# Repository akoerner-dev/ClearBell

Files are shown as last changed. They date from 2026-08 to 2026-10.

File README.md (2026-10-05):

# ClearBell — Smart-Doorbell (ESP32-S3, Hardware + Firmware)

Selbst entwickeltes Türklingelsystem für ein Zweifamilienhaus — vollständig
eigenentwickelt von der Schaltung über das PCB-Layout bis zur Firmware.
Das Projekt dokumentiert nicht nur *was* gebaut wurde, sondern die
**begründeten Technikentscheidungen** dahinter.

> Leitsatz des Projekts: **„Keep it simple, but working."**

**Aktuelle Generation: V0.2** — Redesign auf den ESP32-S3. Beide Platinen sind fertig
verlegt, geprüft und werden bei PCBWay gefertigt und bestückt. Die erste Generation läuft
im Haus und liegt im [Archiv](archiv/V0.1/).

| Außeneinheit V0.2 | Inneneinheit V0.2 |
|---|---|
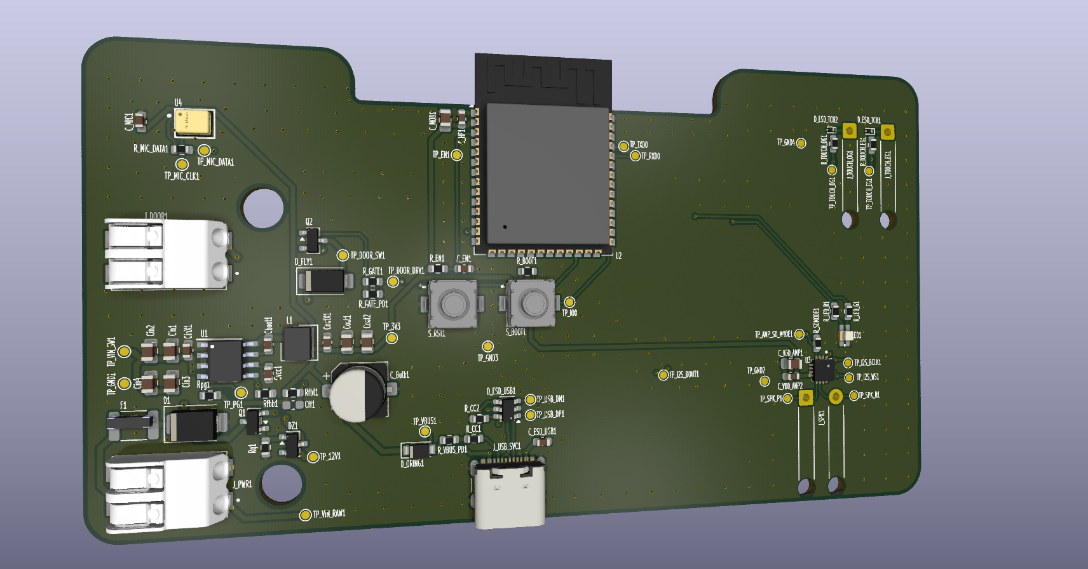
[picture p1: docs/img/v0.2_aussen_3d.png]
Außeneinheit V0.2 – KiCad-3D-Ansicht
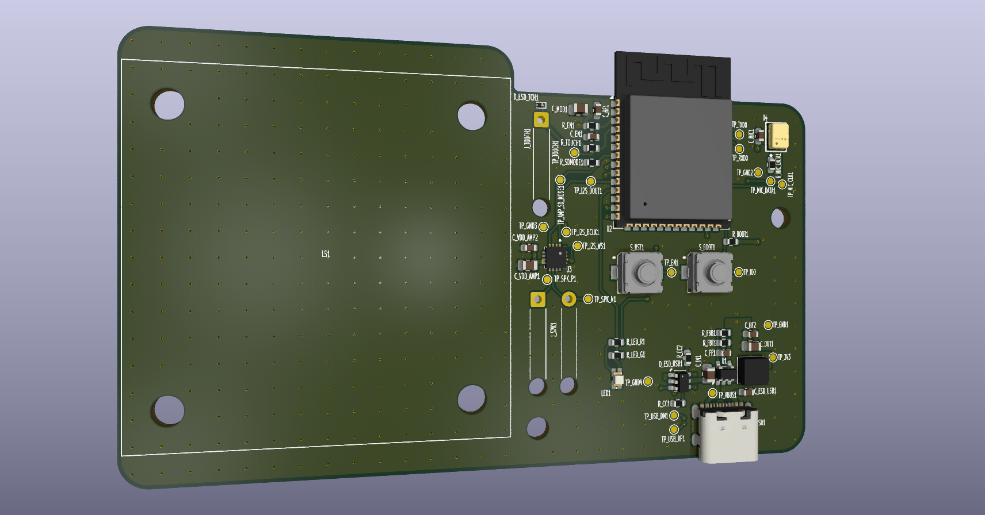
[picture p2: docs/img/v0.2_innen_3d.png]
Inneneinheit V0.2 – KiCad-3D-Ansicht
|  |  |
| 110 × 60 mm, 4 Lagen, 12 V DC | 98 × 60 mm, 4 Lagen, USB-C |

---

## Überblick

Eine **Außeneinheit** an der Haustür und zwei baugleiche **Inneneinheiten**
(je eine pro Wohnung). Klingeln und Türöffnen laufen als quittierte,
gegen Replay abgesicherte Transaktionen über WLAN/UDP.

| Merkmal | V0.2 |
|---|---|
| Controller | ESP32-S3-WROOM-1-N16R8 (16 MB Flash, 8 MB PSRAM), beide Einheiten |
| Stromversorgung außen | 12 V DC (SELV) → 3,3 V mit LMR33630; Polyfuse, TVS-Diode, Verpolschutz |
| Stromversorgung innen | USB-C 5 V → 3,3 V mit TLV62568 |
| Programmierung | natives USB (USB-Serial-JTAG) — innen über die USB-C-Buchse, außen über eine zusätzliche Service-USB-C |
| Bedienung | kapazitive Touch-Taster mit Bronze-Elektroden, ESD-geschützt |
| Audio | MAX98357A I2S-Class-D, Visaton K 50 FL (außen) / K 50 SQ (innen) |
| Mikrofon | Infineon IM72D128V01 (PDM, IP57) auf beiden Einheiten |
| Anzeige | zweifarbige Status-LED (grün / rot, zusammen bernstein) |
| Türöffner | Low-Side-MOSFET mit Freilaufdiode |
| Kommunikation | WLAN + UDP über den Heim-Router, Türbefehl per HMAC-SHA256 authentifiziert |

---

## Was sich gegenüber V0.1 geändert hat — und warum

- **ESP32-S3 statt ESP32.** Natives USB: Flashen und Logs ohne UART-Adapter und ohne
  Tastendruck. PSRAM für Audiopuffer, Flash-Reserve für zwei OTA-Partitionen, vom
  Hersteller zugesagte Verfügbarkeit bis 2033.
- **Mikrofon auf beiden Einheiten** — als Vorbereitung für späteres Wechselsprechen.
  Die Wahl fiel auf ein PDM-Mikrofon, das direkt an 3,3 V läuft: kein zweiter
  Spannungsbereich, keine Pegelwandler.
- **Keine SD-Karte mehr.** Die Klingeltöne sollen im Flash liegen und über die
  Statusseite getauscht werden — ein Steckverbinder und ein mechanischer Fehlerpfad weniger.
- **4 Lagen statt 2.** Beide Innenlagen sind Masse; jede Signallage hat ihre Bezugsfläche direkt
  darunter. Grund: Bei 1,6 mm liegt der dicke Kern zwangsläufig zwischen den Innenlagen, eine
  eigene Versorgungslage brächte dort kaum Flächenkapazität. Bekannte Abweichung (Inneneinheit):
  Eine 3,3-V-Leitung verläuft auf In2 und unterbricht dort die Massefläche.
  USB D+/D−, I2S_BCLK, I2S_WS und LED_RED auf der Unterseite kreuzen diesen Schlitz; ihr Rückstrom
  muss ausweichen. Funktional unkritisch bei USB Full Speed, aus EMV-Sicht aber vermeidbar.
  Behebung in V0.3: Leitung auf eine Außenlage verlegen, In2 wieder geschlossen.
- **Vias neben den Pads, nicht darin.** Ein Via im Pad zieht beim Reflow Lot ab. Der DRC
  prüft das nicht — deshalb eigene Prüfskripte über alle Vias und Pads.
- **Touch ohne Shield/Guard.** Die Bronze-Elektroden bleiben frei zugänglich. Gegen Drift
  durch Feuchte ist eine adaptive Baseline in der Firmware vorgesehen; die ESD-Dioden haben
  nur 0,5 pF, damit die Empfindlichkeit erhalten bleibt.
- **Türöffner-Freilaufdiode auf 1 A ausgelegt** (SMA-Gehäuse). In V0.1 saß dort eine
  Signaldiode, die für den Spulenstrom des Türöffners zu klein war.

Der Funk-Transport bleibt WLAN/UDP über den Router — ESP-NOW wurde an den echten
Montageorten gemessen und verworfen, siehe
[`docs/Funkvalidierung_ESPNOW.md`](docs/Funkvalidierung_ESPNOW.md).

---

## Repo-Struktur

```
clearbell/
├── hardware/                  V0.2, KiCad 10
│   ├── Ausseneinheit/         Schaltplan, Platine, Schaltplan.pdf
│   │   └── fertigung/         Gerber-ZIP, Stückliste, Bestückungsdaten
│   └── Inneneinheit/          dito
├── docs/
│   ├── img/                   3D-Ansichten V0.2
│   ├── Softwarearchitektur_V0.2.md      Firmware-Architektur, Laufzeit, Sicherheit
│   ├── Softwarearchitektur_V0.2.en.md   dasselbe auf Englisch
│   └── Funkvalidierung_ESPNOW.md
└── archiv/V0.1/               erste Generation: Hardware, Firmware, Dashboard, Dokumentation
```

---

## Fertigung

| | |
|---|---|
| Lagenaufbau | 4 Lagen, 1,6 mm, FR-4 (S1000H, TG150), 1 oz außen und innen, keine Impedanzkontrolle |
| Oberfläche | ENIG, Lötstopplack grün, Bestückungsdruck weiß (nur oben) |
| Bestückung | einseitig, maschinell — außen 56, innen 33 Bauteile |
| Stückliste | je Einheit in `fertigung/`, mit Spalte „Ersatz zulässig" (kritische Teile ohne Ersatz) |
| Prüfung | DRC und ERC ohne Befund |

Leiterplatten und Bestückung der V0.2 übernimmt **[www.pcbway.com](https://www.pcbway.com)** im Rahmen eines Sponsorings.

---

## Firmware

Die Firmware — Arduino Core, quittiertes UDP-Protokoll, HMAC-gesicherter Türbefehl,
eigener WAV-Player — läuft auf V0.1 und liegt unter
[`archiv/V0.1/firmware/`](archiv/V0.1/firmware/). Die V0.2-Firmware entsteht nach der
Inbetriebnahme der V0.2-Platinen: Die Prinzipien des Protokolls werden übernommen,
Paketformat, Türbefehl, Fern-Öffnen und Touch-Auswertung dagegen neu aufgesetzt.

**Wie die V0.2-Firmware aufgebaut wird, beschreibt ein eigenes Dokument:** Architektur und
Ausführungsmodell, authentifiziertes Protokoll, Startsequenz und Laufzeitverhalten,
Datenhaltung und Flash-Aufteilung, ein Sicherheitskapitel mit Angreifermodell,
**offen benannten Restrisiken** und einem Abgleich mit ETSI EN 303 645, Fehlerverhalten,
Portierungsplan und Teststrategie. Die aktuelle Revision 2 ist das Ergebnis eines
kritischen Reviews der ersten Fassung mit 29 Befunden.

📄 [**Softwarearchitektur V0.2**](docs/Softwarearchitektur_V0.2.md) · 🇬🇧 [English version](docs/Softwarearchitektur_V0.2.en.md)

Was dort bereits läuft und was noch Entwurf ist, ist durchgehend gekennzeichnet — ebenso die
fünf Verhaltensfragen, die bewusst noch offen sind.

---

## Stand

- **V0.2:** Platinen beider Einheiten in Fertigung und Bestückung bei PCBWay; die
  Firmware-Architektur steht ([Revision 2](docs/Softwarearchitektur_V0.2.md)). Als Nächstes:
  Inbetriebnahme (Versorgung → USB/Flash → Audio → Mikrofon → Touch → Türöffner), danach die
  Firmware-Portierung.
- **V0.1:** läuft im Haus; WLAN/UDP-Transport im Dauertest ohne Paketverlust.

---

## Hinweise

- **Datenblätter** der verwendeten Bauteile sind aus Urheberrechtsgründen **nicht** enthalten —
  sie sind über die Herstellerseiten frei verfügbar; die Typen stehen in den Stücklisten.
- Die eigene KiCad-Bibliothek ist in Schaltplan und Platine eingebettet. Die meisten
  **3D-Modelle** stammen aus der KiCad-Standardbibliothek und erscheinen in jeder
  KiCad-10-Installation; zehn Bauteile nutzen Herstellermodelle (Littelfuse, Panasonic,
  Infineon, TI, WAGO), die aus Lizenzgründen nicht enthalten sind — dort zeigt die
  3D-Ansicht nur die Pads.
- Netzwerknamen, Passwörter und kryptografische Schlüssel sind nicht im Repo.
- **Sicherheitslücken** bitte vertraulich melden, nicht als Issue — wie, steht in
  [`SECURITY.md`](SECURITY.md).

## Lizenz

[MIT](LICENSE) © 2026 André Körner

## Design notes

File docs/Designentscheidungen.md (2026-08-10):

# ClearBell – Designentscheidungen & Begründungen

Dieses Dokument hält fest, WARUM Bauteile gewählt wurden und welche Alternativen verworfen wurden. Wird zu Beginn jedes neuen Chats gelesen, um vollständigen Kontext herzustellen.

---

## Block 1 – Stromversorgung Außeneinheit (12V → 3,3V)

### IC: LMR33630CDDAR (Texas Instruments)

- **Begründung:** Buck-Converter mit 3A, 36V Eingang, 2,1MHz fsw → kleines Induktivitäts-Footprint, hohe Effizienz
- **Alternativen geprüft:** Keine dokumentiert

### L1: Würth 74438356018HT (1,8µH)

- **Begründung:** Passend zur berechneten Induktivität für fsw=2,1MHz, hoher IDC (6,05A), niedriger DCR
- **Status:** Verifiziert gegen Datenblatt ✓

### Verpolschutz: P-Kanal MOSFET (Stelle: Q1)

- **Konzept:** Passiver Verpolschutz ohne aktive Ansteuerung:
  - Source → 12V Eingang
  - Gate → GND über 100kΩ Pull-down (selber Typ wie Rpg, bereits in BOM)
  - Drain → Eingang Buck-Converter
  - Korrekte Polarität: VGS = GND - 12V = -12V → MOSFET leitet
  - Falsche Polarität: VGS = 0V → MOSFET sperrt
- **Begründung für MOSFET statt Schottky:** Verlust bei 1A: \~40mW (MOSFET) vs \~400mW (Schottky) — relevant bei 24/7 Betrieb
- **MOSFET:** DMG2305UX-7 (Diodes Inc., SOT-23) — bleibt in BOM
- **Problem (Review 1.3):** VGS(max) = ±8V, aber bei Betrieb entsteht VGS = -12V → Überschreitung absolutes Maximum
- **Lösung (Review 1.3 ✓):** Zener-Clamp DZ1 parallel Gate-Source
  - Bauteil: Nexperia BZX84-C7V5,215 (7,5V, 250mW, SOT-23)
  - Wirkung: begrenzt VGS auf max. -7,5V → sicher innerhalb ±8V
  - Sättigung des MOSFET bei VGS = -7,5V vollständig gewährleistet (VGS(th) nur -0,5 bis -0,9V)
  - Industriestandard-Lösung, kein Redesign des MOSFET nötig
- **Digikey-Nr. DZ1:** noch einzutragen (BOM v11, Spalte H, Zeile DZ1)

### D1: SMBJ15A (Vishay)

- **Begründung:** TVS-Diode zum Schutz des LMR33630 vor Überspannungstransienten am 12V-Eingang
- **Standoff 15V:** liegt über Betriebsspannung 12V → TVS leitet im Normalbetrieb nicht
- **Klemmspannung 24,4V max.:** tritt nur bei Transienten auf (Spitzenstrom 24,6A) → LMR33630 verträgt 36V → sicher
- **Spitzenleistung 600W:** ausreichend für Transienten in SELV-Haushaltsnetz (kein KFZ)
- **Status:** Verifiziert ✓ (Review 1.4)

### Kondensatoren (Cin, Cout)

- **Regel:** Mindestgehäuse 0603; X7R bevorzugt, X5R akzeptabel wenn Betriebstemperatur ≤ 60°C
- **Temperaturbetrachtung:** Außeneinheit max. \~35°C Umgebung + \~25°C Eigenerwärmung = realistisch \~60°C am Kondensator → X5R (bis 85°C) wäre ausreichend; X7R-Pflicht war zu pauschal

#### Cin — GELÖST (Review 1.5 ✓)

- **Bauteil:** GRM21BZ71E106KE15L — 10µF, 25V, X7R, 0805
- **SimSurfing-Messung bei 12V DC:** nur 2,78µF effektiv (72% Verlust)
- **TI-Anforderung (LMR33630, Section 9.2.2.6):** min. 10µF effektive Kapazität am Eingang
- **Geprüfte Alternativen (verworfen):**
  - GRM21BR61E226ME44 (22µF, 10V, X5R, 0805) → nur 3,85µF bei 12V, unzureichend
  - Höhere Nennspannung in 0805 bei Murata nicht verfügbar
- **Lösung (gewählt): 4× GRM21BZ71E106KE15L parallel**
  - 4 × 2,78µF = \~11,1µF effektiv → erfüllt TI-Minimum von 10µF ✓
  - Kein neues Bauteil nötig, gleicher Typ bereits in BOM
  - TI empfiehlt ohnehin Aufteilung auf beide VIN-Pins (je 2 Caps pro Pin)
- **Fallback Option B** (nur falls PCB-Fläche kritisch wird): Murata GRM32ER71E106KA12L (10µF, 25V, X7R, **1210**) — größeres Gehäuse, besseres DC-Bias-Verhalten, ein Footprint

#### Cout — OK

- **Aktuell:** GRM21BZ71A226ME15L — 22µF, 10V, X7R, 0805 bei 3,3V
- Verhältnis 3,3V/10V = 33% Nennspannung → DC-Bias-Derating unkritisch ✓

---

## Block 2 – ESP32-WROOM-32 Beschaltung

- GPIO6–11 reserviert (internes SPI-Flash) → nicht verwenden ✓ (Review 2.1)
- ADC2 nicht gleichzeitig mit WiFi nutzbar → nur ADC1 Pins verwenden ✓ (Review 2.2)
- GPIO0 Pull-up: 10kΩ empfohlen, Espressif gibt keinen spezifischen Wert vor → 10kΩ akzeptabel ✓ (Review 2.3)
- GPIO12/GPIO15 Strapping-Pins: WROOM-32 hat eFuses für 3,3V Flash gebrannt, GPIO12 unkritisch. Externe Beschaltung darf Strapping-Level nicht überschreiben ✓ (Review 2.4)
- Bulk-Kondensator 100µF (Panasonic EEEFC0J101P): ausreichend für WiFi-Peaks ✓ (Review 2.5)
- UART0: TX=GPIO1, RX=GPIO3 ✓ (Review 2.6)

---

## Block 3 – Kapazitive Touch-Taster (Außeneinheit)

- Touch-Pins: GPIO32 (T9) + GPIO33 (T8) ✓ (Review 3.1) — Hinweis: T8/T9 Bezeichnung in manchen Arduino-Versionen vertauscht, nur Firmware-relevant
- 1kΩ Serienwiderstand ESD-Schutz: innerhalb Espressif-Empfehlung (470Ω–2kΩ, pref. 510Ω) ✓ (Review 3.2)
- Touch durch 2–3mm Holz: Keine Datenblatt-Angabe für max. Dicke. Muss bei Inbetriebnahme empirisch getestet werden (setup_mode: true in ESPHome) ⚠️ (Review 3.3 — offen)
- Steckverbinder: JST-PH

---

## Block 4 – Audio (Außeneinheit)

- IC: MAX98357AETE+T (Maxim/ADI), Class-D, I2S, TSSOP-16
- I2S-Pins: GPIO25 (LRCLK), GPIO26 (BCLK), GPIO22 (DIN) — gängige ESP32 I2S-Pins, via GPIO-Matrix ✓ (Review 4.1)
- ESPHome: i2s_audio + media_player Komponente unterstützt SD-Karten-Audio ✓ (Review 4.2)
- Lautsprecher: Visaton K 36 WP, 8Ω, wetterfest
- SD-Karte für Klingeltöne

---

## Block 2.8 – USB-C Eingang Inneneinheit

### Buchse: Same Sky UJC-HP-3-SMT-TR

- **Typ:** Power-only, 6 Pins (VBUS, GND, CC1, CC2 + 2× Befestigungslaschen), SMD, rechtwinklig
- **Bewertung:** 20V / 3A — ausreichend, Eingang ist 5V
- **Begründung:** Kein Datentransfer nötig → power-only Variante günstiger, einfacher, weniger Footprint-Pins
- **Verfügbarkeit:** Digikey DE, ships today ✓
- **KiCad Symbol/Footprint:** SnapEDA ✓
- **CC-Terminierung:** 2× 5,1kΩ (R_CC1, R_CC2), je CC1/CC2 nach GND
  - Begründung: Ohne Pull-downs kein VBUS-Ausgabe bei modernen USB-C-Netzteilen. Beide CC-Pins müssen beschaltet sein — ein einziger Widerstand genügt nicht.
  - 5,1kΩ signalisiert dem Netzteil: Sink, 5V, Default Current (500mA) — ausreichend für ESP32 + Audio
- **TVS-Schutz:** Entfällt ✓
  - SMBJ5.0A geprüft (Vishay Datenblatt lokal): VC(max) = 9,2V bei IPPM — liegt weit über TLV62568 Abs.Max 5,5V → schützt nicht
  - TVS für 5V-Systeme mit 5,5V Abs.Max generell ungeeignet (kein Bauteil mit VC < 5,5V verfügbar in SMBJ-Serie)
  - Einsteck-Transienten bei USB-C Netzteil in Innenräumen: unkritisch (kurzes Kabel, niedringe Induktivität, interne PSU-Caps, Cin 4,7µF dämpft zusätzlich)
  - Entscheidung: Kein TVS. Cin (4,7µF) ist ausreichender Schutz.

## Block 2.7 – Stromversorgung Inneneinheit (5V USB-C → 3,3V)

- IC: TLV62568DBVR (TI), Buck-Converter, SOT-23-5
- L1: Cyntec SDER041H-2R2MS, 2,2µH
- Cin: Murata GRM188Z71A475KE15D (4,7µF, 10V, X7R, 0603)
- Cout: GRM21BZ71E106KE15L (10µF, 25V, X7R, 0805) — Wiederverwendung aus Außeneinheit-BOM
- **EN-Pin:** Direkt an VIN (+5V) — kein R_EN nötig. Datenblatt Section 7.4.1 + Figure 5 (Referenzschaltbild): EN direkt an VIN, kein Widerstand. Darf laut Datenblatt nicht floaten, direkte VIN-Verbindung ist Standard.
- **C_HF:** 100nF 0603 auf +3V3 direkt an U1 (Layoutregel Datenblatt Section 10.1)
- **PWR_FLAG:** je 1× auf +5V-Netz und +3V3-Netz für ERC

---

## Allgemeine Designregeln

- Mindestgehäuse: 0603
- Kondensatoren: X7R bevorzugt, X5R akzeptabel bei max. ~60°C Betriebstemperatur
- Passivbauteile: 10er-Gebinde
- Lieferanten: Digikey (primär), Mouser, LCSC
- EDA: KiCad (ab Phase 3)
- Firmware: ESPHome
- Leitsatz: **Keep it simple, but working**
- Keine Exoten: E96-Widerstände und schwer beschaffbare Teile vermeiden
- **ESP-NOW + WiFi:** laufen simultan auf demselben WiFi-Kanal. ESP-NOW Kanal kann nicht separat konfiguriert werden wenn WiFi aktiv — teilt automatisch den WiFi-Kanal. Kein Problem für ClearBell. Belegt: ESPHome Docs espnow-Komponente ✓ (Review 5.1)
- **ESPHome Touch:** esp32_touch Komponente vollständig unterstützt. Schwellwert bei Inbetriebnahme kalibrieren ✓ (Review 5.2)

---

## Phase 4 – PCB-Layout Außeneinheit

### Allgemeine Layout-Grundsätze
- **Einseiteige Bestückung:** Alle Bauteile auf Oberseite (F.Cu). Unterseite bleibt frei — wird mit Doppelklebeband ins Gehäuse geklebt.
- **THT-Pins:** Überstehende Lötpins auf der Unterseite werden nach dem Löten bündig abgeknipst, damit die Klebefläche eben ist.
- **J_UART:** Female Socket 90° (liegend), 1×4, 2,54mm, THT — Würth 61300411021, Digikey 732-61300411021-ND. Öffnung muss zur PCB-Kante zeigen (Breadboard-Kabel-Zugänglichkeit).

### Gehäuse & Platinengröße
- Außenmaß Gehäuse: 150 × 100mm
- Rand (Wandstärke + Montagespielraum): 2× 20mm je Achse
- **Platinengröße final: 98 × 60mm** (optimiert nach BT-Platzierung, war initial 110×60mm)
- Touchflächen: mind. 25 × 25mm je Taste (EG rund, OG eckig laut Frontpanel-Design)
- Frontpanel-Layout: 2 Touchflächen + 2 Beschriftungsfelder (vertikal angeordnet)
- **Lautsprecher Visaton K 36 WP: wird auf die PCB geklebt. Hat keine Schraubbefestigung, keine Lötstifte — nur Lötpads direkt auf der Unterseite des Gehäuses. Verbindung zur Schaltung über kurze Drähte in J_SPK (WAGO 2086-1202).**
- **Sperrfläche Lautsprecher: 45×45mm (Keepout Rule Area) — oben rechts in der PCB-Ecke. Kein Bauteil darf unter dem aufgeklebten Lautsprecher liegen. Wird als erstes Element im PCB-Layout eingezeichnet.**
- Touch-Elektroden: Bronze-Blech extern, per kurzem Kabel an R_TOUCH_EG1/R_TOUCH_OG1 angeschlossen (kein PCB-Pad nötig, kein Positionszwang durch Frontpanel-Geometrie)

### Kritische Layout-Randbedingung
- **Touch-Elektroden auf der PCB müssen exakt hinter den Touchflächen des Frontpanels liegen.**
  - Die Kupferfläche der Touch-Pads ist positionsfest durch das Gehäusedesign.
  - Konsequenz: Touch-Pad-Positionen im PCB-Layout zuerst festlegen, dann restliche Bauteile um diese herum platzieren.
- Lautsprecher (Visaton K 36 WP, ø36mm): Position und Gehäuse-Ausschnitt noch festzulegen.

### Fortschritt Phase 4 Außeneinheit
- [x] PCB-Umriss 110×60mm auf Edge.Cuts eingezeichnet
- [x] Keepout Rule Area 45×45mm Lautsprecher — oben rechts eingezeichnet
- [x] PCB aus Schaltplan aktualisiert (F8) — erster Durchlauf, nur Bauteile mit Footprint
- [x] Footprints alle Bauteile zugewiesen (siehe Tabelle unten)
- [x] PCB erneut aus Schaltplan aktualisiert (F8) — alle Bauteile erscheinen
- [x] Footprints manuell auseinandergezogen (kein automatisches Verteilen in KiCad 10 gefunden)
- [x] Bauteilplatzierung abgeschlossen
- [x] Routing abgeschlossen
- [x] GND-Fläche B.Cu gesetzt
- [x] Thermal Vias unter U1 EP gesetzt (0,3mm Bohrung, 0,5mm Pad, Netz GND)
- [x] DRC bestanden: 0 Fehler, 0 Warnungen, 0 Unverbundene Elemente, 37 Ausschlüsse (bekannte SnapEDA-Kosmetik)
- [x] **Phase 4 Außeneinheit PCB-Layout: ABGESCHLOSSEN ✅**

- [ ] **Nächster Schritt: Phase 4 Inneneinheit PCB-Layout**
  - Voraussetzung: F8 Gehäusekonzept Inneneinheit klären (F8)

### Layoutregeln (verifiziert gegen LMR33630 Datenblatt Section 10.1)

**Buck-Converter:**
- Cin direkt an VIN-Pins U1, je 2× pro VIN-Pin
- SW-Knoten (L1 ↔ SW-Pin) so kurz wie möglich, min. 1,5mm breit
- Feedbackteiler (Rfbt/Rfbb) nah an FB-Pin, aber räumlich getrennt vom SW-Knoten (min. 2–3mm)
- EP (Exposed Pad) U1 per Thermal-Via-Array mit GND-Fläche verbinden: 4–9 Vias, 0,3mm Bohrung, 0,5mm Pad, 1mm Raster, Netz GND, kein Via-Tenting Unterseite
- Leiterbahnbreiten: SW-Knoten 1,5mm, 12V-Eingang 1,0mm, +3V3 0,5mm, Signale 0,25mm

**ESP32:**
- C_HF (100nF) direkt am VCC-Pin — näher als C_bulk
- C_bulk (100µF) direkt daneben
- Antenne freihalten: kein Kupfer unter/neben Antennenbereich (auch B.Cu Massefläche)
- Antenne möglichst Richtung Gehäuseaußenwand
- J_UART, S_RST, S_BOOT an PCB-Kante / gut zugänglich

**Thermal Vias allgemein:** 0,3mm Bohrung, 0,5mm Pad, Netz GND, kein Tenting

#### Footprint-Zuweisung — Status

| Bauteil(e) | Footprint | Status |
|---|---|---|
| Alle Widerstände 0603 | `Resistor_SMD:R_0603_1608Metric` | ✓ Festgelegt |
| Kondensatoren 0603 | `Capacitor_SMD:C_0603_1608Metric` | ✓ Festgelegt |
| Kondensatoren 0805 | `Capacitor_SMD:C_0805_2012Metric` | ✓ Festgelegt |
| C_bulk (Elko Ø6,3×5,4mm) | `Capacitor_SMD:CP_Elec_6.3x5.4` | ✓ Festgelegt |
| Q1, DZ1, Q2 (SOT-23) | `Package_TO_SOT_SMD:SOT-23` | ✓ Festgelegt |
| D1 (SMBJ15A, DO-214AA/SMB) | `Diode_SMD:D_SMB` | ✓ Festgelegt |
| D_FLY1 (1N4148W-E3-18, SOD-123) | `Diode_SMD:D_SOD-123` | ✓ Festgelegt — verifiziert gegen Vishay DB: Package = SOD-123 |
| J_UART (Würth 61300411021, Female 90°) | `Connector_PinSocket_2.54mm:PinSocket_1x04_P2.54mm_Horizontal` | ✓ Festgelegt |
| J_TOUCH1, J_TOUCH2 (Lotpad) | `TestPoint:TestPoint_Pad_2.0x2.0mm` | ✓ Festgelegt |
| **WAGO 2086-1202** (J_PWR, J_DOOR, J_SPK) | Von SnapEDA heruntergeladen, in Projektbibliothek eingebunden | ✓ Erledigt |
| **L1 Würth 74438356018HT** | Von Würth heruntergeladen, in Projektbibliothek eingebunden | ✓ Erledigt |
| **PTS526 SK15 SMTR2 LFS** (S_RST, S_BOOT) | Manuell erstellt im KiCad Footprint-Editor. Maße aus C&K-Datenblatt (01/30/26): Körper 5,2×5,2mm, PCB Land 7,0×6,4mm, 4-Pin Gull-Wing. | ✓ Erledigt |

- [ ] Footprint-Zuweisung Inneneinheit (analog, nach Außeneinheit)
- [ ] Bauteilplatzierung
- [ ] Routing

---

## Phase 3 – KiCad Schaltplan (laufend)

### Setup
- KiCad 10.0, deutsche UI
- Zwei separate Projekte (Option A): Außeneinheit + Inneneinheit
- Außeneinheit-Projekt: `<Projektordner>\KiCad\Ausseneinheit\ClearBell_Ausseneinheit.kicad_pro`
- Blattgröße A3, Titelblock ausgefüllt (Rev. 1.0)
- Bibliotheken (projektspezifisch): `<Projektordner>\KiCad\Bibliotheken\`

### Externe Symbole/Footprints (nicht in KiCad-Standardbibliothek)
- **LMR33630CDDAR:** Von TI-Website heruntergeladen, als projektspezifische Bibliothek eingebunden. Footprint: DDA0008J (.pretty-Ordner). ✓
- **ESP32-WROOM-32E-N4:** Von SnapEDA heruntergeladen (N8-Variante, elektrisch identisch zu N4 — gleiche Pins, gleicher Footprint). Als projektspezifische Bibliothek eingebunden. ✓
  - Hinweis: KiCad 10.0 hat ESP32-Symbole bereits in Standardbibliothek (RF_Module) — für zukünftige Bauteile erst dort suchen.

### KiCad-Hinweise aus Praxis
- Standardbibliothek "Device" war initial leer — Lösung: Globale Bibliotheksliste zurücksetzen
- D_TVS in KiCad = bidirektional; unidirektionale TVS (SMBJ15A) → Symbol Device:D_Zener verwenden
- PWR_FLAG auf 12V-Netz UND GND-Netz notwendig um ERC-Fehler "Input-Power-Pin" zu vermeiden
- ERC 7× Ausschlüsse (false positives): VIN/VCC/BOOT/SW Power-Pin-Fehler + Bibliothekswarnungen aus TI-Symbol — alle unkritisch

### Fortschritt Außeneinheit
- [x] Projekt angelegt, Titelblock, A3
- [x] Block 1 komplett: U1, L1, Cin×4+CinX, Cout1/2/CoutX, Cboot, Cvcc, Cff(DNP), Rfbt/Rfbb/Rpg/Rg, Q1+DZ1, D1, J_PWR, 2×PWR_FLAG — ERC sauber
- [x] Block 2 komplett: U2, C_HF1, C_Bulk1, C_EN1, R_EN1, R_BOOT1, R_GPIO2, R_RXD1, S_RST, S_BOOT, J_UART1 — verdrahtet, ERC sauber (10× pin_not_connected für spätere Blöcke bewusst offen)
  - UART J_UART: Pin 2 = TX (ESP TXD0), Pin 3 = RX (ESP RXD0 via R_RXD). Kreuzung TX↔RX passiert im Kabel zum USB-Adapter, nicht auf der Platine.
- [x] Block 3 komplett: R_TOUCH_EG1 (1k), R_TOUCH_OG1 (1k), J_TOUCH_EG (Conn_01x01), J_TOUCH_OG (Conn_01x01) — GPIO32→R→J_TOUCH_EG, GPIO33→R→J_TOUCH_OG
- [x] Block 4 komplett: U2 MAX98357AETE+T (TSSOP-16), C_VDD_AMP1 (10µF), C_VDD_AMP2 (100n), J_SPK (Conn_01x02). SD-Karte: J_SD (Micro_SD_Card, Molex 475710001, Digikey WM9731TR-ND), C_SD (100n). SD_MODE→+3V3 (Left-Channel, direkte Verbindung, kein R_SDMODE), GAIN_SLOT→GND (12dB), EP→GND, Shield→GND. Kein R_SD1–R_SD4 (SPI-Leitungen kurz, 25MHz unkritisch).
- [x] Block 5 komplett: Q2 IRLML6344TRPBF (N-Kanal MOSFET, SOT-23), R_GATE1 (100R), R_GATE_PD1 (100k Pull-down), D_FLY1 (1N4148W), J_DOOR1 (Conn_01x02). GPIO21→R_GATE→Gate, Gate→R_GATE_PD→GND, Source→GND, Drain→J_DOOR Pin1+Anode D_FLY, Kathode D_FLY→+12V, J_DOOR Pin2→+12V. ERC sauber.
  - Türöffner: 9-16V DC, 480mA. Versorgung über vorhandene 12V-Schiene.
  - Designentscheid: MOSFET statt Relais wegen Baugröße (Außeneinheit soll dünn bleiben).
- [x] Block 6 entfällt — alle Steckverbinder bereits in Blöcken 1–5 integriert. Außeneinheit Schaltplan komplett.
- [ ] Inneneinheit Schaltplan
  - [x] KiCad-Projekt angelegt: `KiCad\Inneneinheit\ClearBell_Inneneinheit.kicad_pro`
  - [x] Titelblock: A3, Rev. 0.1
  - [x] Projektbibliotheken eingebunden (ESP32, MAX98357A, UJC-HP-3-SMT-TR)
  - [x] Block 1 vollständig verdrahtet — ERC sauber (2× ignorierte false positives: V-BUS/+5V Netzname + EN bidirektional)
    - J_USB: VBUS→+5V, GND+Shield→GND, CC1→R_CC1→GND, CC2→R_CC2→GND
    - U1: VIN→+5V, EN→+5V, GND→GND, SW→L1→+3V3, FB→Teiler R_FBT/R_FBB
    - R_FBT (470kΩ): +3V3→FB, R_FBB (100kΩ): FB→GND → VOUT = 3,42V (BOM v13: R1_INN=470kΩ RC0603FR-07470KL, R2_INN=100kΩ RC0603FR-07100KL)
    - C_IN1→+5V/GND, C_OUT1/C_HF1→+3V3/GND, PWR_FLAG 1→+5V, PWR_FLAG 2→+3V3
  - [x] Block 2 komplett verdrahtet — ERC sauber (15× ignorierte false positives: GND Kastell-Pads, 3V3/VCC bidirektional; 8× pin_not_connected für Blöcke 3+4 bewusst offen)
    - J_UART1: Pin1=GND, Pin2=TXD0, Pin3=100Ω→RXD0, Pin4=+3V3
    - R_EN1 (10kΩ): +3V3→EN, C_EN1 (100nF): EN→GND, S_RST: EN→GND
    - R_BOOT1 (10kΩ): +3V3→GPIO0, S_BOOT: GPIO0→GND
    - R_GPIO2 (10kΩ): GPIO2→GND (Pull-down für Boot-Modus), No-Connect auf alle ungenutzten Pins
  - [x] Block 3 komplett: R_TOUCH1 (1kΩ) GPIO32→J_TOUCH1
  - [x] Block 4 komplett: U3 MAX98357AETE+T, C_VDD1 (10µF), C_VDD2 (100nF), J_SPK1 (Conn_01x02), J_SD1 (Molex 1040310811, Digikey WM9731CT-ND), C_SD1 (100nF). Kein R_SD-Serienwiderstände, SD_MODE direkt +3V3.
    - I2S: GPIO22→DIN, GPIO25→LRCLK, GPIO26→BCLK, SD_MODE→+3V3
    - SPI SD: GPIO23→CS(DAT3), GPIO21→MOSI(CMD), GPIO19→SCK(CLK), GPIO18→MISO(DAT0), DAT1/DAT2→No Connect — Pins 37/33/31/30 am Modul, optimiert für kurzes Routing zum SD-Slot
    - ERC: 16 Warnungen (SnapEDA-Symbole), teilweise behoben — restliche Fixes ausstehend (s. F5)
  - [x] Block 5 entfällt — alle Steckverbinder bereits in Blöcken 1–4 integriert. Abgleich mit Projektdokumentation Rev.2 bestätigt Vollständigkeit.
  - [x] Inneneinheit Schaltplan komplett — ERC: 0 Fehler, Warnungen werden bereinigt (F5)

### Phase 5 – PCB Layout Inneneinheit
- [x] Edge.Cuts gesetzt (110×65mm vorläufig → optimiert)
- [x] Alle BT platziert
- [x] Geroutet — DRC fehlerfrei
- [x] **F12 GELÖST: Boardgröße optimiert** — finale Größe noch einzutragen (nach Zusammenschieben). Routing wiederholt, DRC sauber.
- [x] **Phase 5 Inneneinheit PCB-Layout: ABGESCHLOSSEN ✅**

### Phase 4 – PCB Layout Außeneinheit (Nachtrag)
- [x] Boardgröße nach Optimierung auf **98×60mm** reduziert (war 110×60mm)

---

## Offene Punkte / Flags

| # | Thema | Beschreibung |
|---|---|---|
| ~~F1~~ | ~~DZ1 Digikey-Nr.~~ | ✓ Gelöst: BZX84-C7V5,215 → DK **1727-5040-1-ND** — in BOM v13 eingetragen |
| ~~F2~~ | ~~Cin Außeneinheit~~ | ✓ Gelöst: 4× GRM21BZ71E106KE15L parallel → ~11,1µF effektiv. Fallback Option B: GRM32ER71E106KA12L 1210 falls Platz knapp. |
| ~~F7~~ | ~~Steckverbinder J_PWR / J_DOOR~~ | ✓ Gelöst: **WAGO 2086-1202 für alle Drahtanschlüsse** (J_PWR, J_DOOR, J_SPK, J_SPK_INN). Begründung: Push-Wire ohne Crimpen, geeignet für Hausinstallationsquerschnitte bis 1,5mm², SMD liegend, kein Spezialwerkzeug. JST-PH Einträge für J_SPK / J_SPK_INN in BOM v13 ersetzt. J_TOUCH/J_TOUCH_INN bleiben Lotpad (Direktanlötung Bronzeelektrode). J_UART bleibt Pin-Header (Programmierschnittstelle). |
| F3 | Review 3.3 Touch/Holz | **Direktkontakt validiert (08.05.2025):** Bronzeelektrode, 1kΩ Reihenwiderstand, GPIO32 (T9), Arduino-ESP32-Core (neuere Version → Rohwerte ~1000er-Bereich, nicht 60–80). Baseline: ~1060, Touch (Finger direkt): ~200, dünner Handschuh: ~910, dicker Skihandschuh: ~990 (bewusst ausgeschlossen). Firmware-Schwellwerte: TOUCH_ON=950, TOUCH_OFF=1000, READS_NEEDED=2, delay=50ms. Skihandschuh: Designentscheidung — nicht unterstützt. **Kalibrierung am eingebauten Gerät (IBN) ausstehend** — Baseline kann je nach Einbauumgebung abweichen. |
| ~~F4~~ | ~~BOM 2.7.3 Digikey-Nr.~~ | ✓ Gelöst: TLV62568DBVR → DK **296-47359-1-ND** — SDER041H-2R2MS → DK **2037-SDER041H-2R2MSCT-ND** — in BOM v13 eingetragen |
| F8 | Inneneinheit Gehäuse | Gehäusekonzept noch nicht entschieden — Bestückungsseite, Befestigung, Formfaktor offen. Entscheidung vor Phase 4 Inneneinheit erforderlich. |
| ~~F12~~ | ~~Boardgröße Inneneinheit optimieren~~ | ✓ Gelöst: BT zusammengeschoben, Routing wiederholt, DRC fehlerfrei. Finale Boardgröße: siehe Phase 5. |
| ~~F11~~ | ~~L1 Inneneinheit Footprint~~ | ✓ Gelöst: Würth WE-MAPI-4020HT Footprint gegen Cyntec SDER041H-2R2MS Datenblatt geprüft — Pad-Maße passen. |
| F5 | ERC Symbol-Mismatch | SnapEDA-Symbole: Pin-Typen direkt im Schaltplan korrigiert (nicht in Bibliothek, da schreibgeschützt). Ursprüngliche 16 Warnungen (falsche Pin-Typen) behoben. Verbleibend: 3× lib_symbol_mismatch (Außeneinheit) + 4× (Inneneinheit) — ignoriert, rein kosmetisch. **ACHTUNG: Niemals "Symbole aus Bibliothek aktualisieren" ausführen — das würde die Schaltplan-Korrekturen mit den alten Bibliotheksversionen überschreiben!** |
| ~~F6~~ | ~~SD-Halter Footprint~~ | ✓ Gelöst: Würth-Footprint aus KiCad-Symbol war nicht kompatibel mit Molex 1040310811. In beiden Schaltplänen auf passenden Molex-Footprint gewechselt. Molex günstiger und mechanisch besser geeignet. BOM-Teilenummer (WM9731CT-ND) war bereits korrekt. |

---
## REVISION 2026-07-05: Kommunikationsarchitektur
ESP-NOW-Direktfunk fuer Klingel/Tueroeffner VERWORFEN nach
Funkvalidierung (Strecke an Montageorten funktional tot, alle Hebel
bewertet: Sendeleistung bereits Maximum 19,5 dBm / EU-Grenze 20 dBm
EIRP; Long-Range-Modus nur ~4 dB; externe Antenne 32UE verworfen).
NEU: Kommunikation ueber Heim-WLAN, UDP direkt zwischen den
Einheiten (kein Broker, kein Pi — Home Assistant laeuft nicht).
Quittungsprotokoll aus ESPNOW_Test wird auf UDP portiert.
Tuerbefehl: Authentifizierung auf Anwendungsebene (Schluessel +
Zaehler). RSSI an allen Montageorten gemessen und tragfaehig.
Details und Messwerte: Funkvalidierung_ESPNOW_2026-07-05.md
Offene Klaerpunkte vor Umsetzung: IoT-SSID vs. Hauptnetz
(Klienten-Isolation pruefen!), DHCP-Reservierungen, Nachrichtensatz,
Wiederverbindungslogik, Volllasttest 3V3, Inneneinheit 2 reparieren.

2026-07-06: WLAN/UDP ueber «Heimnetz» als Transport bestaetigt und
funktional abgenommen (Klingel + Tuer beidseitig, 0 Verluste am
verschaerften OG-Punkt). Langzeit + reale entfernte Funkstrecke als
Worst-Case-Annahme akzeptiert (siehe Funkvalidierung). Naechster
Schritt: Nachrichtensatz + Anwendungs-Authentifizierung Tuerbefehl.

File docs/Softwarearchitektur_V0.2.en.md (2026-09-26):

# ClearBell V0.2 — Software Architecture and Firmware Plan

> **Document type:** architecture and design document for the generation V0.2 firmware · **Revision 2**
> **As of:** 2026-09-26 · **Hardware:** in fabrication · **Firmware:** port not yet started
> **Deutsche Fassung:** [`Softwarearchitektur_V0.2.md`](Softwarearchitektur_V0.2.md)

---

## 0. What this document is — and what it is not

ClearBell is a custom doorbell system for a two-family house: one outdoor unit at the front door, two identical
indoor units, communicating over WLAN/UDP with no server of its own and no broker. The V0.2 hardware is fully
designed and in fabrication; the firmware for that hardware does not exist yet.

This document describes **the software that will run on those boards**: architecture, runtime behaviour, security
concept, data storage, test strategy, and the path from the V0.1 firmware currently in service.

**Revision 2** is the result of a review of the first version that was allowed to question everything except the
external constraints — one outdoor unit, two indoor units, the fabricated hardware, push notifications to a
smartphone. It found 29 issues, among them three paths to the front door against which the carefully built
cryptography did nothing. The seven decisions that followed are incorporated here and recorded in the project as
design decisions R17–R23. Section 16 shows what changed.

**Three things are kept strictly apart throughout:**

| Marker | Meaning |
|---|---|
| **[V0.1 — running]** | In continuous service in the house, measured or confirmed under test. The source is the actual code. |
| **[V0.2 — design]** | Specified target for the upcoming firmware. Not implemented, not measured. |
| **[open]** | Deliberately undecided. Collected in section 12. |

This is not a formality. An architecture document that makes planned work look like finished work is worthless —
and in this project the most expensive mistakes were all caught because assumptions were checked against reality
rather than the other way round. Statements about the platform in this document were checked against the Arduino-ESP32
core 3.3.10 actually installed, not against its documentation.

**Not contained here:** network names, passwords, cryptographic keys, push topics, MAC addresses. Those are
operational secrets of one specific installation, not part of the architecture.

---

## 1. System overview

### 1.1 Topology

```mermaid
graph TB
    subgraph NET["Internet"]
        direction LR
        N["ntfy.sh<br/>push service"] <-->|"Push · signed reply"| S["Smartphone<br/>GF apartment"]
    end

    R{{"Home router<br/>WLAN · static IPs"}}

    subgraph AU["Outdoor unit · 12 V DC · front door"]
        direction TB
        A_T["2× touch<br/>bell GF / UF"] --> A_M["ESP32-S3<br/>N16R8"]
        A_MIC["Microphone<br/>IM72D128V01"] -.-> A_M
        A_M --> A_A["Audio<br/>MAX98357A"]
        A_M --> A_D["Door opener<br/>MOSFET"]
    end

    subgraph EG["Indoor unit GF · USB-C 5 V"]
        direction TB
        E_T["1× touch<br/>door release"] --> E_M["ESP32-S3<br/>N16R8"]
        E_MIC["Microphone<br/>IM72D128V01"] -.-> E_M
        E_M --> E_A["Audio<br/>MAX98357A"]
    end

    subgraph OG["Indoor unit UF · USB-C 5 V"]
        direction TB
        O_T["1× touch<br/>door release"] --> O_M["ESP32-S3<br/>N16R8"]
        O_MIC["Microphone<br/>IM72D128V01"] -.-> O_M
        O_M --> O_A["Audio<br/>MAX98357A"]
    end

    NET <-->|"HTTPS · outdoor unit only"| R
    R <-->|"UDP 4210"| AU
    R <-->|"UDP 4210"| EG
    R <-->|"UDP 4210"| OG
```

*GF = ground floor apartment, UF = upper floor apartment.* The microphones are dashed because in V0.2 they are fitted
but have no function (section 5.7).

### 1.2 Roles and responsibilities

| | Outdoor unit (1×) | Indoor unit (2×, identical) |
|---|---|---|
| **Triggers** | bell GF, bell UF | door release request |
| **Executes** | door opener pulse, push dispatch | chime playback |
| **Verifies** | door commands from the indoor units (challenge–response) and remote openings from the phone (signature) | rings and acknowledgements from the outdoor unit |
| **Knows keys** | one link key each for GF and UF, plus the phone keys | only its own link key |
| **Logs** | remote openings individually, touch openings only as a total | the openings of its own apartment |
| **Supply** | 12 V DC (SELV) | USB-C 5 V |
| **Particularity** | extra service USB-C; carries the door opener driver | supply and programming share one socket |

**Two independent bell paths.** The GF button reaches only the GF unit, the UF button only the UF unit. No
broadcast, no group logic — every ring is a self-contained transaction to exactly one destination. The **door
opener, by contrast, is shared**: both apartments open the same front door.

This asymmetry shapes the security concept (section 7): a failed ring is an annoyance, a falsely triggered door
opener is a burglary. At the same time the two apartments are two **separate households** — what one unit logs is
none of the other's business (section 6.4).

### 1.3 Quality goals

| Goal | Metric | Target | Status |
|---|---|---|---|
| **The door opens only when authorised** | trigger paths without authentication | **0** | design — sections 5.4, 7 |
| **Nothing is lost silently** | messages acknowledged but not executed | **0** | design — section 4.3 |
| The ring gets through | touch outside → chime inside | ≤ 0.5 s | measure during bring-up |
| Failure is reported | touch → failure tone at the door when the apartment does not answer | ≤ 1.5 s | V0.1: ≈ 1.2 s |
| Door command | release indoors → door opener pulse | ≤ 1 s | measure during bring-up |
| Self-healing | WLAN back → operational, without restart | ≤ 30 s | measure during bring-up |
| Continuous operation | no restart, free heap stable | 7 h as the gate for the port, ≥ 72 h before installation | V0.1: 7 h passed |
| Updates | a faulty update | rolls itself back to the previous version | design — section 8.1 |
| Privacy | microphone in normal operation | off | design — section 5.7 |

The targets are commitments of this design, not measurements. They are measured during bring-up and either confirmed
there or adjusted with a stated reason.

---

## 2. Platform and constraints

### 2.1 Target platform

| | Value | Note |
|---|---|---|
| Module | ESP32-S3-WROOM-1-**N16R8** | 16 MB flash, 8 MB octal PSRAM |
| Build | **ESP-IDF project with Arduino-ESP32 as a component** | Arduino API in the code, configuration (`sdkconfig`) under our control |
| Versions | pinned as a pair; the Arduino core 3.3.10 used so far is built on ESP-IDF 5.5.4 | verify the pairing against the release notes during setup; the component requires `CONFIG_FREERTOS_HZ=1000` |
| Configuration | `sdkconfig.defaults` and `partitions.csv` in the repository | every build is reproducible |
| Audio | `ESP_I2S` + custom WAV player | deliberately **not** `ESP32-audioI2S` |
| File system | LittleFS in internal flash | the SD card is dropped relative to V0.1 |
| Programming | native **USB-Serial-JTAG** (GPIO19/20) | flashing, console and debugging over one socket |
| Updates | dual OTA, **signed**, rollback **after a self-test** | section 8.1 |

**Why ESP-IDF rather than the Arduino IDE.** In the precompiled Arduino core, secure boot, flash encryption, NVS
encryption, anti-rollback and signed updates are switched off and cannot be switched on; Espressif itself points to
“Arduino as component” for this. As an IDF project the entire security configuration becomes reachable without giving
up the Arduino code. **Reachable does not mean enabled** — whatever is irreversible follows the hardening stages in
section 7.7.

**Why not `ESP32-audioI2S`.** The library requires PSRAM and pulls in decoders the project does not need. The custom
player reads 16-bit PCM block by block and pushes it to I2S — that is the entire required feature set. Even with the
S3's PSRAM this remains the right choice.

### 2.2 Hard constraints that bind the software

These follow from datasheets and from the fabricated board:

| Constraint | Consequence for software |
|---|---|
| **GPIO35/36/37 are octal PSRAM** | must never be configured — otherwise hard-to-diagnose boot failures |
| **PDM receive only on I2S0, 16-bit only** | microphone must be on **I2S0**, amplifier on **I2S1** |
| **GPIO19/20 = USB** | cannot be repurposed |
| **GPIO0/3/45/46 = strapping** | only GPIO0 is used deliberately (boot button) — and only during operation: held at power-up, the chip starts in download mode |
| **GPIO39–42 (JTAG) carry no copper** | no external JTAG adapter; debugging with GDB/OpenOCD runs over the built-in USB-JTAG on GPIO19/20 |
| **Deep sleep impossible** | both units are UDP receivers — a sleeping unit does not open the door |
| **Door opener gate floats after reset** | firmware drives the pin LOW **before anything else** (section 5.1) |
| **The door opener driver sits in the outdoor unit** | physical access to the outdoor unit is access to the door — no firmware helps against that, the mounting does (section 7.5) |

### 2.3 V0.2 pin assignment

Both units deliberately share **one** set of pin constants. Where a function does not exist indoors, the pin simply
stays unused rather than shifting the assignment.

| Function | GPIO | Outdoor | Indoor | Direction |
|---|---|---|---|---|
| Touch bell GF / door release button | **4** | bell GF | door release | analog in |
| Touch bell UF | **5** | bell UF | — | analog in |
| *Reserve guard / shield* | 6 / 14 | keep free | keep free | — |
| I2S1 BCLK → amplifier | **15** | ✓ | ✓ | out |
| I2S1 WS/LRCLK → amplifier | **16** | ✓ | ✓ | out |
| I2S1 DOUT → amplifier | **17** | ✓ | ✓ | out |
| Amplifier `SD_MODE` (mute) | **7** | ✓ | ✓ | out |
| I2S0 PDM CLK → microphone | **38** | ✓ | ✓ | out |
| I2S0 PDM DATA ← microphone | **21** | ✓ | ✓ | in |
| **Door opener gate** | **47** | ✓ | *unused* | out |
| Status LED red | **48** | ✓ | ✓ | out |
| Status LED green | **18** | ✓ | ✓ | out |
| USB D− / D+ | 19 / 20 | service socket | supply + data | — |
| Boot / reset | 0 / EN | button | button | — |
| UART0 TXD0 / RXD0 | 43 / 44 | test points | test points | fallback path |

**Free as reserve:** GPIO1, 2, 8, 9, 10, 11, 12, 13 — locked in the schematic with no-connect flags. “Reserve”
explicitly means *decide again at V0.3*, not *available at any time*.

The pin constants in the code carry **exactly the net names from the schematic** — including where these contain
German abbreviations (EG/OG, the German names of the two apartments, i.e. GF/UF). This prevents transcription errors
between hardware and software. All V0.1 pin definitions are void; nothing is carried over.

---

## 3. Software architecture

### 3.1 Layers

```mermaid
graph TD
    subgraph L4["Application logic"]
        direction TB
        KL["Ring transaction"]
        TU["Door release transaction"]
        ST["Diagnostics & log"]
    end
    subgraph L3["Services"]
        direction TB
        TX["Transport<br/>sessions · ACK"]
        AU["Audio<br/>WAV player"]
        TC["Touch<br/>arming window"]
        PU["Remote opening<br/>push · signature"]
        MO["Operating modes<br/>maintenance · setup"]
        WB["Status page<br/>HTTP"]
        TX ~~~ PU
        AU ~~~ MO
        TC ~~~ WB
    end
    subgraph L2["Platform abstraction"]
        direction TB
        NET["WLAN · UDP · TLS"]
        CRY["HMAC · RNG"]
        FS["NVS · LittleFS"]
        I2S["I2S0 · I2S1"]
    end
    subgraph L1["ESP-IDF with Arduino component"]
        direction TB
        HW["Drivers · FreeRTOS · OTA"]
    end
    L4 --> L3 --> L2 --> L1
```

The layering exists so the **application logic stays testable without hardware**: ring and door-release
transactions, protocol, WAV parser and state machines run as unit tests on a PC (section 11.3). In V0.1 it was
exactly this separation that made it possible to separate the protocol test from the production code.

### 3.2 Execution model

Four ground rules:

1. **The main loop never blocks.** [V0.1 — running, carried over] Anything that can take more than a few
   milliseconds — WLAN association, TLS, audio, uploads — runs as a state machine in the loop or in its own task.
2. **Every resource has exactly one owner.** Other contexts only put requests into its queue. Above all the door
   opener: neither the touch path nor remote opening ever touch GPIO47 themselves.
3. **Hand-over only via FreeRTOS queues.** A `volatile` flag is not synchronisation on a dual-core processor. V0.1
   shared the push buffers and the token table between loop and task that way — a second push could overwrite the
   first one while it was being sent.
4. **Everything is on the watchdog.** The idle tasks of both cores and every task of our own are monitored. Out of the
   box the Arduino core does not monitor the main loop — that is switched on explicitly.

| Context | Content | Owner of |
|---|---|---|
| **Main loop** | transport (UDP, sessions, retries, heartbeat), touch, operating modes, LED | send slots, touch state |
| **Task `door`** *(outdoor)* | accepts opening requests, checks the lockout, generates the pulse, logs | **GPIO47** |
| **Task `audio`** | reads the file system, feeds I2S1, switches the amplifier | I2S1, `SD_MODE` |
| **Task `remote`** *(outdoor)* | sends the ring push, keeps the command stream open, issues and verifies tokens | token table |
| **HTTP server** (IDF) | status page, in its own task | — |

The ESP-IDF HTTP server runs in its own task anyway — one more reason for the IDF build: the Arduino `WebServer` reads
every request, including uploads, inside the calling loop; a 400 KB chime would have blocked it for seconds.

> **Unverified:** whether `i2s.write()` blocks on a full DMA buffer and thereby sets the pace of the audio task
> itself has never been measured. That belongs in bring-up (section 11.1).

### 3.3 Module split [V0.2 — design]

V0.1 is a single 731-line `.ino` — right for bring-up, no longer viable for V0.2.

| Module | Responsibility |
|---|---|
| `config.h` | pins (schematic net names), timing constants, unit type — **no secrets** |
| `cb_provisioning` | reads role, keys and WLAN credentials from the factory partition; setup, factory reset |
| `cb_protocol` | v2 frame, serialisation, HMAC, sessions, challenge–response |
| `cb_transport` | UDP, send slots, retries, heartbeat, rate limiting |
| `cb_audio` | WAV parser, playback, priorities, volume, `SD_MODE` |
| `cb_touch` | hardware baseline, plausibility, arming window |
| `cb_door` *(outdoor)* | door task — **the only place that touches GPIO47** |
| `cb_remote` *(outdoor)* | push, tokens, command stream, phone signatures |
| `cb_status` | LED, status page, door-opening log, counters |
| `cb_modes` | normal operation, maintenance, setup |
| `cb_ota` | accept an update, verify its signature, self-test, rollback |

There is **one firmware image per unit type** (outdoor, indoor). GF and UF differ only in their provisioning — no image
contains a secret.

Isolating `cb_door` is intentional: if exactly one task drives the door opener pin, answering “what can open the
door?” is a text search rather than a code review.

---

## 4. Communication protocol

### 4.1 Transport decision

**WLAN + UDP directly between the units via the home router.** No MQTT broker, no Raspberry Pi, no cloud.

ESP-NOW was not rejected on taste but after a full RF validation at the actual mounting locations: the link was
functionally dead there, and every lever (channel choice, transmit power, antenna orientation) had been exhausted.
The measurements are in [`Funkvalidierung_ESPNOW.md`](Funkvalidierung_ESPNOW.md) (German). The WLAN/UDP stack
subsequently passed a seven-hour endurance test with no packet loss and no restart.

UDP offers no transport acknowledgement. **The only success criterion is therefore the application acknowledgement** —
not “sent”, but “the receiver confirmed that it processed this”.

### 4.2 Protocol v2 [V0.2 — design]

V0.1 used a 14-byte packet in which only the door command was authenticated. Version 2 authenticates **every**
message, detects restarts of the sender and allows later changes.

| Field | Bytes | Purpose |
|---|---|---|
| `magic` = `CB` | 2 | discard foreign packets without computation |
| `version` | 1 | later changes without breakage — the devices are updated one after another |
| `type` · `sender` · `receiver` | 3 | receiver in the packet: a packet meant for GF is not valid at UF |
| `session` | 4 | random number per start of the sender (section 4.3) |
| `seq` | 4 | running within the session |
| `payload` | 0…n | e.g. random challenge, result |
| `tag` | 16 | HMAC-SHA256 over `"CBv2"` ‖ all preceding fields, truncated to 128 bits |

**Rules:**

* **One key per link** — outdoor↔GF and outdoor↔UF each have their own. GF and UF share no key and cannot forge each
  other.
* **Fixed byte order** (little endian) and serialisation through dedicated functions, not through a `packed struct`.
* **Order of checks on receipt:** length and `magic` → rate limit per sender → version → tag (constant time) → session
  and `seq`. Whatever fails is discarded without an answer.
* **Versions:** every unit understands its own version and the previous one.
* **Why 128 bits:** NIST allows truncation down to 32 bits; the forgery probability is (1/2)^(λ − t) with 2^t allowed
  failed attempts. 64 bits would suffice with rate limiting — 128 bits take the question off the table for 8 bytes.

**Message types:**

| Type | Direction | Purpose | V0.1 |
|---|---|---|---|
| `PING` / `PONG` | both | heartbeat every 30 s; establishes sessions | defined, never sent |
| `RING` / `RING_ACK` | outdoor → indoor / back | ring | `KLINGEL` / `KLINGEL_QUITT` |
| `DOOR_REQUEST` | indoor → outdoor | request a door command | — |
| `DOOR_CHALLENGE` | outdoor → indoor | fresh random number | — |
| `DOOR_CONFIRM` | indoor → outdoor | returns the random number; the tag proves the key | `TUER_AUF` (with counter) |
| `DOOR_ACK` | outdoor → indoor | result | `TUER_QUITT` |

### 4.3 Acknowledgement, retry, sessions

```mermaid
sequenceDiagram
    participant A as Outdoor unit
    participant I as Indoor unit GF
    Note over A: touch GF detected
    A->>I: RING (session s, seq n)
    Note over A: send slot taken, t₀ = now
    I->>A: RING_ACK (s, n)
    Note over I: acknowledge FIRST,<br/>then start the chime
    Note over A: slot released, success tone
```

| Parameter | Value | Rationale |
|---|---|---|
| Acknowledgement timeout | **300 ms** | shown in RF testing to sit safely above round-trip time [V0.1 — running] |
| Retries | **max. 3** | after that the transmission counts as definitively lost |
| Time to “failure” | **≈ 1.2 s** | initial send plus three retries of 300 ms |
| Concurrent transmissions | **3 slots** | GF and UF rings may overlap |

**The acknowledgement goes out before the payload action.** The indoor unit replies first and only then starts the
chime; the other way round, audio output would eat into the sender's acknowledgement window.

**Sessions and duplicates.** Every unit draws a new session number at every start. A duplicate is a message with
**the same session and the same number** as one already processed; it is not executed again, **but it is still
acknowledged** — the most common cause of a duplicate is a lost acknowledgement.

The session number exists because of a flaw in V0.1: there the ring counter started at 0 at every boot, and the indoor
unit recognised a duplicate only by an equal number. After a restart of the outdoor unit a ring could therefore be
**acknowledged but not played** — the visitor heard the success tone, nothing rang inside.

**New sessions** are confirmed by the heartbeat: after starting, every unit immediately reports to its peers. If a
message with an unknown session arrives nonetheless, the receiver answers with a challenge and the sender's retry
gets through — at worst 300 ms later. A recorded packet from an old session fails this challenge.

**Heartbeat:** every 30 s; after three missing answers the peer counts as unreachable (LED red). The outdoor unit thus
knows that an apartment is unreachable before the next ring.

### 4.4 Door command by challenge–response

```mermaid
sequenceDiagram
    participant I as Indoor unit
    participant A as Outdoor unit
    participant T as Door task
    Note over I: valid touch (section 5.6)
    I->>A: DOOR_REQUEST
    Note over A: fresh random number,<br/>valid 2 s, single use
    A->>I: DOOR_CHALLENGE (random number)
    I->>A: DOOR_CONFIRM (random number)
    Note over A: verify tag (constant time),<br/>number open and fresh?
    A->>I: DOOR_ACK (result)
    Note over I: success tone
    A->>T: opening request (queue)
    Note over T: check lockout,<br/>pulse, log
```

| Property | Implementation |
|---|---|
| **Authenticity** | the tag on every message (section 4.2), a separate key per apartment |
| **Freshness** | random number from the hardware RNG — truly random while the radio is active —, valid 2 s, single use |
| **Replay** | impossible: a recorded confirmation matches no new random number |
| **No persistent state** | no counter in NVS — nothing can drift apart after reflashing |
| **Acknowledge before acting** | `DOOR_ACK` goes out, then the door task takes over |

**Why the V0.1 counter is gone.** V0.1 protected the door command with a strictly increasing counter in the NVS of both
sides. That has two weaknesses: if the outdoor unit loses its NVS, recorded commands become valid again; if an indoor
unit loses its NVS — for instance through a full reflash — its counter restarts at 1 and the outdoor unit discards
every one of its commands as a replay, practically forever. Challenge–response has neither problem.

**Cost:** one extra round trip on the LAN. With modem sleep each step may wait for the router's next DTIM beacon — the
time to the pulse is measured during bring-up (target ≤ 1 s, section 1.3).

### 4.5 Remote opening via push [V0.2 — design]

The use case is concrete: a child is locked out, no adult is home.

```mermaid
sequenceDiagram
    participant A as Outdoor unit
    participant N as ntfy.sh
    participant H as Phone (app)
    Note over A: GF ring detected,<br/>generate token (128 bits, single use)
    A->>N: push with button (TLS verified)
    N->>H: notification
    Note over H: button opens the app with the token,<br/>HMAC with the phone key
    H->>N: signed reply
    N->>A: command stream (TLS verified)
    Note over A: verify signature and token,<br/>consume token,<br/>opening request to the door task
    A->>N: confirmation “door opened via app”
```

| Property | Implementation |
|---|---|
| **The phone signs** | HMAC-SHA256 over the token with a key that exists only on this phone and in the outdoor unit; the message carries an algorithm identifier |
| **One key per phone** | revocable individually, e.g. when a phone is lost |
| **Token** | 128 bits, single use, bound to exactly one ring; its validity is set during bring-up — 5 min is acceptable because the token is worthless without the phone key |
| **TLS** | certificate validation against the certificate bundle embedded in the core (Mozilla list); no pinning — the server certificates change every few weeks |
| **Topics** | may remain public; ntfy.sh is only a transport |
| **Traceable** | every remote opening is confirmed by push and logged (section 6.4) |

**Why this way.** In V0.1 the one-time token was carried in the push itself. On ntfy.sh a topic without a paid
reservation is public — “the topic is essentially a password” —, and messages are retained for 12 hours. Anyone
reading the alert topic held a valid opening token. Access control on ntfy.sh costs money or requires an own server
reachable from the internet. The phone signature solves the problem for free and takes the service operator out of
the chain of trust as well.

**Platforms.** Android: the app “HTTP Shortcuts” has a built-in HMAC function and accepts values through deep links —
the push button opens it with the token. iOS: the Shortcuts app, as far as available descriptions go, has no HMAC,
only plain hashes; how signing can work there is [open]. The algorithm identifier keeps the door open for a second
scheme without breaking Android.

---

## 5. Runtime behaviour — what happens when

### 5.1 Start-up sequence [V0.2 — design, safety critical]

Principle: **first bring everything into a safe state, then enable functions.**

| # | Step | Why here |
|---|---|---|
| 1 | **GPIO47 as output, LOW** *(outdoor)* | the pin floats after reset; until firmware defines it, only the 100 kΩ gate pull-down holds it. Very first statement. |
| 2 | **Amplifier muted** (`SD_MODE` LOW) | no switch-on pop; the pull-down already keeps it muted during boot |
| 3 | Status LED off | “dark” means *firmware not running yet* |
| 4 | Logging over USB-CDC | diagnostics available from here on |
| 5 | Read reset reason and boot counter | an unexpected restart of the outdoor unit is reported later by push (section 7.5) |
| 6 | Check the factory partition | not provisioned → setup (section 5.9); otherwise load role and keys |
| 7 | NVS settings, check the schema version | migrate data after an update if needed |
| 8 | Mount LittleFS | if that fails, the device continues silently |
| 9 | Configure I2S1 (amplifier) | no output yet |
| 10 | **Do not start the microphone** | no clock, no data — section 5.7 |
| 11 | Initialise touch, learn the baseline | needs a brief quiet period with no contact |
| 12 | Start WLAN — event-driven, non-blocking | the device must become operational even without a network |
| 13 | Start tasks, register all with the watchdog | `door`, `audio`, `remote`, HTTP server |
| 14 | Update self-test if a new image is running | confirmed only once WLAN and the peer respond (section 8.1) |
| 15 | Set the LED to the first real state | from here the display tells the truth |

Step 1 is the core of the requirement “the door opener must never trigger through boot, reset or brownout”: in
hardware through the pull-down, in software through this ordering — **both together**.

### 5.2 Main loop

One iteration, fixed order, no step blocks:

| Step | Purpose |
|---|---|
| Transport | accept one UDP packet (rate limited), sessions, due retries, heartbeat |
| Touch | evaluate hardware values, plausibility, arming window, put requests into queues |
| Operating modes | boot button, maintenance time window |
| LED | update the status colour |
| Watchdog | sign of life |

Audio, push, command stream, door opener and status page run in their tasks (section 3.2).

### 5.3 Ring sequence — complete

```mermaid
sequenceDiagram
    participant B as Visitor
    participant A as Outdoor unit
    participant I as Indoor unit
    participant P as ntfy (GF only)
    participant S as Smartphone

    B->>A: touches electrode GF
    Note over A: hardware baseline,<br/>plausibility checked
    par RF path
        A->>I: RING
        I->>A: RING_ACK
        Note over I: chime,<br/>window for a short tap opens
        Note over A: success tone at the door
    and Push path (best effort)
        Note over A: generate one-time token
        A->>P: HTTPS POST + button (TLS verified)
        P->>S: notification
    end
```

**The push path never blocks the RF path.** It runs in its own task and is explicitly best-effort: with no internet
it is skipped, and the visitor never notices. What happens when someone taps the button in the notification is
shown in section 4.5: the phone signs, the outdoor unit verifies and opens.

| Event | When |
|---|---|
| Touch detected | after repeatedly confirmed samples, on the order of 100 ms (V0.1 value, to be re-measured on the S3) |
| Acknowledgement back | typically a few ms, with modem sleep up to the next DTIM beacon |
| Success tone at the door | effectively immediately after the acknowledgement |
| **Failure tone** (apartment empty / no WLAN) | **only after ≈ 1.2 s** — before that, failure is not established |
| No WLAN at all | immediate failure path, no send attempt |

The late failure tone is not a defect but a consequence of “the acknowledgement is the only success criterion”.

### 5.4 Door opener — two trigger paths

```mermaid
graph LR
    T1["① Touch on an<br/>indoor unit"] -->|"challenge–response<br/>arming window"| Q["Queue"]
    T3["③ Push button<br/>on the phone"] -->|"phone signature<br/>TLS verified"| Q
    Q --> G["Door task<br/>GPIO47"]
    G --> D["Door opener<br/>MOSFET"]
    style G fill:#5b3a1a,color:#fff
```

| Path | Who | Protection |
|---|---|---|
| **①** touch on an indoor unit | residents at home | challenge–response (section 4.4), touch plausibility and arming window (section 5.6) |
| **②** ~~status page, HTTP POST~~ | — | **removed:** it had no authentication — “POST only, local network only” protects neither against a foreign device on the WLAN nor against cross-site request forgery. The status page does not open the door, not even with a password. |
| **③** push button on the phone | residents away | phone signature, TLS validation, one-time token (section 4.5) |

The numbers are kept so references stay unambiguous; ② is not reused.

**The door task** is the only owner of GPIO47 (section 3.2):

* It takes requests from its queue — whichever path they come from.
* It sets the gate and ends the pulse via a **hardware timer**, i.e. even if the loop hangs; plus a hard upper limit on
  the on-time.
* After every opening a **lockout applies to all paths**.
* Every opening is logged (section 6.4); a remote opening is additionally confirmed by push.

The pulse duration is [open] (section 12). The door-opener dry run during bring-up uses a serial command over USB, i.e.
only with physical access to the device — never over the network.

### 5.5 Audio

**Flow:** open file → parse RIFF/WAVE (find `fmt ` and `data` chunks, skip unknown ones) → compare the sample rate with
the current I2S configuration and reconfigure only on mismatch → enable the amplifier → playback in the audio task.

| Property | V0.1 | V0.2 |
|---|---|---|
| Source | SD card (FAT32, SPI) | **LittleFS** in internal flash |
| Format | WAV, 16-bit PCM | unchanged |
| Block size | read 512 bytes, for mono pass 1 KB of stereo to I2S | unchanged, in the audio task |
| Volume | digital scaling 0–100 % before I2S | unchanged |
| Steps | 15 / 30 / 50 / 75 / 100 %, via the boot button, stored in NVS | unchanged (short press) |
| Amplifier | permanently enabled | **`SD_MODE` enables it on demand** |
| Precedence | the newest sound replaces the current one | **ranking:** ring > failure > success > UI feedback |

The digital attenuation deliberately sits **before** I2S: the MAX98357A has no volume control; its `GAIN` pin only sets
the clipping point (12 dB against GND here). After enabling via `SD_MODE` the amplifier needs a moment before the sound
starts cleanly — the audio task therefore begins with silence; the required lead time is determined during bring-up.

If a file is missing or is not 16-bit WAV, the device continues silently and logs it. **Audio is never a reason to
crash** — the doorbell must still be able to open the door without sound.

### 5.6 Touch

The bronze electrodes are **openly accessible**, not behind wood. That yields a large signal swing but exposes the
electrode directly to condensation and grime; a canopy stops driving rain, not dew. A shield channel and a guard ring
were deliberately rejected (both would require additional electrodes).

**The hardware provides the foundation.** On the S3 the core's touch driver uses the new IDF driver with a **hardware
baseline** (“benchmark”), a hardware filter and thresholds relative to the baseline (default 1.5 %); on top of that come
the internal denoise channel as well as hysteresis and debouncing. The firmware builds on this instead of implementing
its own baseline:

| # | Measure | Effect |
|---|---|---|
| 1 | **Evaluation relative to the hardware baseline** | fixed thresholds do not survive a change of season |
| 2 | **No tracking while a key is held** | the baseline does not creep onto a resting finger |
| 3 | **Outdoor plausibility:** if *both* bell buttons trigger simultaneously → discard | that is not a finger, that is wetness |
| 4 | **Minimum hold time** | debounces and filters transients |
| 5 | **Raw value and baseline on the status page** | drift becomes visible *before* it causes misbehaviour |

**Indoors the situation is harder:** outdoors a false trigger means a spurious ring, indoors it means an **open front
door** — and measure 3 does not apply there, because there is only one touch channel.

| | Indoor measure |
|---|---|
| a | **Maximum hold time for the short tap:** anything present for more than ~2 s is a cloth, a towel or someone leaning on it → discard and relearn the baseline |
| b | **Trigger only on release** — a permanently wetted sensor never triggers |
| c | **Longer minimum hold time than outdoors** |
| d | **Lockout after every door command** — for all paths (section 5.4) |
| e | **After a restart, fix the baseline only after a brief quiet period** |
| f | **Arming window:** for up to **2 min** after a ring **at this apartment**, a short tap opens the door. Otherwise it takes **holding for 3 s**; a confirmation tone signals when to let go. Whoever does not let go within a few seconds after the tone is discarded. |

In the normal case — the bell rings, someone presses — (f) costs no convenience. A cleaning cloth, a child or an
accidental touch outside the window triggers nothing.

The V0.1 thresholds (on 600 / off 800, 2× confirmed, 50 ms) are **not transferable** — the S3's value range is
different. To be clarified during bring-up: whether the denoise channel is active, how the hardware baseline is tracked
while a touch is resting, the upper limit for the long press, and whether the window closes after the first opening.

### 5.7 Microphone

The hardware is fitted on all three units: Infineon IM72D128V01, PDM, runs directly off 3.3 V, IP57, top port.

**In V0.2 the microphone has no function — and it does not run.** In normal operation the firmware does not start I2S0:
no clock, no data in buffers. That is privacy by default and saves power. During bring-up the path is checked with a
test command.

The later target state is **half-duplex intercom**: talk or listen, never both — the operating mode of every ordinary
door intercom, without echo cancellation.

> **A correction recorded in the project:** the earlier claim “full duplex is impossible by construction” has been
> withdrawn — it was unsubstantiated. Both I2S controllers sit on the same die and can possibly be fed from the same
> clock source. That is **unverified** and belongs in the V0.3 backlog.

When the microphone may be active at all is [open] — section 12.

### 5.8 Network behaviour

| Situation | Behaviour |
|---|---|
| No WLAN at start-up | the device boots fully, association proceeds in the background |
| WLAN lost | reconnect **event-driven**, with growing intervals up to at most 60 s — an association in progress is **never** aborted |
| WLAN returns | re-establish sessions via heartbeat, increment the drop counter |
| Send attempt without WLAN | treated as failure **immediately** — no waiting for a timeout |
| Foreign packet on the UDP port | discarded without being read |
| Packet flood | rate limit per sender before the HMAC check, counted on the status page |
| Command stream to the push service drops | reconnect with growing intervals and a random component — never every second |
| Peer unreachable at its static IP | fall back to the unit's mDNS name |
| **Modem sleep** | enabled; its effect on the 300 ms acknowledgement window is **measured**, not assumed |

**Why reconnection is rebuilt:** V0.1 called `disconnect()` and `begin()` every 3 s while not connected — even while an
association was still in progress. With a weak signal, where WPA2 and DHCP take longer, it aborted every attempt itself.

**Recommendations for the network**, outside the firmware: a dedicated network segment for just the three units, where
they can reach one another, separated from the rest of the home network — a guest network usually also isolates the
devices from each other and thereby breaks the UDP traffic. In addition WPA3 or protected management frames (PMF),
which prevent deauthentication attacks: the chip supports both, but PMF defaults to “optional” — the firmware sets
“required” when the router supports it.

### 5.9 Operating modes [V0.2 — design]

```mermaid
stateDiagram-v2
    [*] --> Normal
    [*] --> Setup: not provisioned
    Normal --> Maintenance: boot button<br/>5 s
    Maintenance --> Normal: 10 min<br/>or button
    Maintenance --> Setup: boot button 5 s
    Setup --> Normal: saved
```

| Mode | How it is reached | What is possible |
|---|---|---|
| **Normal** | default | ringing, door command ①, remote opening ③; status page read-only, with device password |
| **Maintenance** | hold the boot button for 5 s during operation; ends after 10 min or via the button | sound upload, update, settings, diagnostics |
| **Setup** | from maintenance, or automatically as long as the device is not provisioned | set up role, keys and WLAN credentials; add or revoke phone keys; factory reset |

The boot button sits inside the housing. **Physical presence is therefore the second factor** for everything that
changes the firmware or its secrets — without user accounts, without password management. A short press steps the
volume, as in V0.1.

Initial provisioning runs over USB. If a unit later cannot join the WLAN — for instance after a router replacement —, in
maintenance it opens its own access point for setup; so nobody has to open the outdoor housing to reflash it. Press
durations and time windows are design values.

---

## 6. Data storage

### 6.1 Flash layout [V0.2 — design]

The basis is the Arduino core's standard scheme `default_16MB` (2 × 6.25 MB app, 3.4 MB file system, 64 KB core dump),
extended by a partition for the factory state.

| Area | Size | Purpose |
|---|---|---|
| 2× OTA app | ≈ 6 MB each | two full firmware slots |
| LittleFS | ≈ 3.4 MB | chime, success and failure tones (one chime ≈ 424 KB) |
| `nvs` | 20 KB | settings, calibration, door-opening log, schema version |
| `fctry` | small | **factory state:** role, link and phone keys, WLAN credentials, device password — read-only in normal operation |
| `coredump` | 64 KB | crash dump for diagnostics |
| `otadata`, `phy` | small | update management, RF calibration |

The table lives in the repository as `partitions.csv` and is **final before the first deployment** — it cannot be
changed by an update.

An update writes only the currently passive app slot; the file system and the NVS partitions are untouched. The real
risk of an update is therefore not data loss but **a changed data format** — for that the NVS carries a schema version,
and new firmware migrates on first start.

The headroom is this generous because speech recognition does **not** run on the device; its models alone would have
taken about 6 MB.

### 6.2 NVS

| Partition | Content | Written |
|---|---|---|
| `nvs` | volume, touch calibration, door-opening log, schema version | during operation |
| `fctry` | role, keys, WLAN credentials, device password | only in setup; erased only by a factory reset |

The separation ensures that resetting the settings does not take the keys with it — and conversely that a factory
reset really erases everything secret. The door-command counters of V0.1 disappear entirely with challenge–response.

### 6.3 Changing chimes without a PC

The SD card is gone. Chimes are uploaded into LittleFS through the status page — **only in maintenance**: the file is
written to a temporary file, checked as 16-bit WAV and only then renamed into place atomically; an aborted upload leaves
no half chime. That was the condition for dropping the card: *“the SD can go if the chimes can be swapped without a PC.”*

### 6.4 Door-opening log [V0.2 — design]

The log makes misuse visible — for instance a remote opening nobody triggered. But it inevitably contains data from
**both** households. Therefore:

| Where | What is logged and shown |
|---|---|
| **Indoor unit GF / UF** | only the door openings of its **own** apartment, with time and result |
| **Outdoor unit** | remote openings **individually** (they exist only for GF anyway); touch openings **only as a total**, without time and without apartment |

The log is a ring buffer in NVS. The time comes from NTP while internet is available; otherwise entries are relative to
uptime and marked as such.

---

## 7. Security concept

### 7.1 Assets, by weight

| # | Asset | Damage if lost |
|---|---|---|
| **1** | **The front door** | unauthorised entry — the single most severe failure of the system |
| 2 | Availability of ringing | a visitor goes unnoticed |
| 3 | Integrity of the firmware and the update path | whoever replaces the firmware owns the door |
| 4 | Confidentiality of room audio | microphones in living spaces and at the front door |
| 5 | Privacy between the households | what one apartment does is none of the other's business |
| 6 | Integrity of the display | a resident believes the door was opened when it was not |

### 7.2 Attacker model

| | Attacker | Capabilities | Response of the design |
|---|---|---|---|
| **A** | a device on the same WLAN (guest, compromised IoT device) | send arbitrary packets, eavesdrop | every message authenticated, challenge–response, no door via the web — and ideally a dedicated network segment |
| **B** | an attacker within RF range without WLAN access | jam, deauthenticate, test recorded handshakes offline against the WLAN password | PMF against deauthentication, WPA3 where possible, a strong WLAN password |
| **C** | an attacker on the internet path to the push service — or the service itself | redirect, eavesdrop | TLS with certificate validation; the phone signature makes an intercepted token worthless |
| **D** | physical access to the outdoor unit | open the housing | **opens the door directly** — the driver sits there; the mounting helps against that. Without secure boot the attacker could also install firmware with a backdoor → hardening stage C |
| **E** | an unauthorised person inside at an indoor unit | press the touch pad | arming window — outside it, a 3 s hold is required; anyone inside can unlock anyway |
| **F** | the other household | open the status pages | logs separated per household, a device password per unit |
| **G** | anyone who could install an update | load their own firmware | only in maintenance, only signed |

### 7.3 Measures

| Measure | Against | Stage (7.7) |
|---|---|---|
| **Every message authenticated**, 128-bit tag, one key per link | A, B | A |
| **Challenge–response** for the door command | A, B — record and replay | A |
| **Session numbers**, rate limiting | A — forgery, flooding; silent losses | A |
| **No door via the web** — path ② removed | A — a single HTTP request | A |
| **Phone signature** for remote opening, single-use token | C — intercepted tokens, service operator | A |
| **TLS with certificate validation** | C | A |
| **Arming window**, trigger on release, plausibility | E, false triggers | A |
| **Door task** as the only owner, pulse via hardware timer, lockout | concurrency, a hanging loop | A |
| **Door pin driven LOW first**, 100 kΩ gate pull-down | boot, reset, brownout, crash | hardware + A |
| **Maintenance via the boot button** for upload, update, setup | A, G | A |
| **Signed updates**, rollback after a self-test | G | A |
| **Provisioning instead of compiled-in secrets** | publication of images, D | A |
| **Keys in eFuse** (usable, not readable), encrypted NVS | D — read-out over USB | B |
| **Secure boot** of the outdoor unit | D — backdoor via reflashing | C |
| **Door-opening log**, confirmation push, restart report | traceability, tamper indication | A |
| **Microphone off**, no recording | asset 4 | A |
| **No secrets in the repository** | publication | done |

### 7.4 What revision 1 left open — and how it is solved

Revision 1 named eight weaknesses, some of them in the running V0.1 code. The review found two more paths to the door.
Status after revision 2:

| | Weakness | Solution |
|---|---|---|
| S-1 | TLS without certificate validation on the push path | certificate bundle of the core (4.5) |
| S-2 | push topic as a password on a public service | irrelevant for the door: the phone signs (4.5) |
| S-3 | losing NVS resets the replay protection | no counter any more: challenge–response (4.4) |
| S-4 | only the door command authenticated | every message authenticated (4.2) |
| S-5 | keys unencrypted in flash | provisioning, stage B (eFuse), stage C (7.7) |
| S-6 | no rate limit | rate limit per sender (4.2) |
| S-7 | 64-bit tag | 128 bits (4.2) |
| S-8 | WLAN credentials in plain text | provisioning, stage B (encrypted NVS) |
| new | **the status page opened the door without authentication** | path ② removed (5.4) |
| new | **the token was carried in the push itself** | phone signature (4.5) |

### 7.5 Remaining risks — deliberately accepted

* **The door opener driver sits in the outdoor unit.** Whoever opens the housing opens the door — no firmware changes
  that. In door-intercom practice it is therefore common to put the switching stage inside the secured area. For V0.2
  the hardware is fixed; what works is the **mounting**: a housing that cannot be opened from outside, and supply lines
  that cannot be reached from outside. Moving the driver inside is earmarked for V0.3.
* **Tamper indication only on power interruption.** The outdoor unit reports every restart with its cause by push; the
  indoor units report its outage through the heartbeat. Opening it without interrupting power goes unnoticed — the
  board has no housing switch.
* **Until hardening stage C**, someone with access to the housing can install their own firmware.
* **The push service is best-effort.** If ntfy.sh fails there is no push and no remote opening; ringing and the indoor
  door command do not depend on it.
* **A lost phone** is protected by its screen lock until its key is revoked.
* **Router and WLAN** remain a precondition for ringing; without them the door gives a distinguishable notice tone
  (section 12, F-4).

### 7.6 Keys and secrets

| Secret | Where | Stage B / C |
|---|---|---|
| Link keys outdoor↔GF, outdoor↔UF | factory partition | eFuse (HMAC peripheral: usable, not readable) |
| Phone keys | factory partition of the outdoor unit, and on the phone | encrypted NVS |
| WLAN credentials, device password | factory partition | encrypted NVS |
| Update signing key | **private key offline with a copy**, public key in the firmware | stage C: secure boot key plus a spare key |

Losing the signing key would be the only way to lock oneself out **for good** — hence the copy and the spare key.

**eFuse budget:** the S3 has exactly **6 key blocks**, shared by flash encryption, secure boot digests and HMAC keys.
With the outdoor unit fully hardened — 2 link keys, 1 NVS key, 1 flash encryption key, 2 secure boot keys — all 6 are
used. The allocation is fixed before the first block is burned; a wrongly assigned block is lost.

### 7.7 Hardening in stages

| Stage | Content | Reversible? | When |
|---|---|---|---|
| **A** | everything in 7.3 without eFuse | yes | with the port |
| **B** | keys in eFuse, NVS encryption, anti-rollback | burning eFuses is final, **but does not lock the device** | after acceptance of the port |
| **C** | outdoor unit only: secure boot with a spare key, secure download mode; flash encryption only if still justified then | **no** | at the earliest after some months of stable operation, and only once the mounting protects the housing |

The indoor units get no stage C — they hang inside the apartments. For the outdoor unit secure boot without flash
encryption will probably suffice: the firmware is open source and need not be secret, and after stage B the secrets
live in eFuse or in encrypted NVS.

### 7.8 Privacy

Microphones in a home and at a front door are not legally neutral. In Germany, recording the spoken word engages § 201
of the Criminal Code (StGB), and the GDPR applies on top — all the more once audio leaves the device. The decisions:

* **No recording, no storage** as default behaviour; a visitor journal is not planned.
* **The microphone does not run in normal operation** (section 5.7).
* **No dedicated activity indicator in hardware** — decided reversibly: the status LED could add one in firmware.
* **The logs are separated per household** (section 6.4).
* When the microphone may be active at all is [open] — section 12.

*I am not a lawyer; this section is not legal advice.*

### 7.9 Alignment with ETSI EN 303 645

EN 303 645 (V3.1.3, 2024-09) is the European baseline standard for consumer IoT cyber security. For a private build it
is not mandatory, but as a yardstick it is exactly right.

| No. | Provision | Implementation in the design |
|---|---|---|
| 5.1 | No universal default passwords | keys and device password per unit, generated at provisioning |
| 5.2 | Implement a means to manage reports of vulnerabilities | [`SECURITY.md`](../SECURITY.md): reporting channel, timelines for acknowledgement and status updates |
| 5.3 | Keep software updated | signed updates, rollback after a self-test |
| 5.4 | Securely store sensitive security parameters | provisioning, stage B |
| 5.5 | Communicate securely | every message authenticated, TLS validated |
| 5.6 | Minimize exposed attack surfaces | no door via the web, write actions only in maintenance |
| 5.7 | Ensure software integrity | signed updates, stage C |
| 5.8 | Ensure that personal data is secure | microphone off, logs per household |
| 5.9 | Make systems resilient to outages | sessions, challenge–response, watchdog, reconnection |
| 5.10 | Examine system telemetry data | door-opening log, restart report, counters |
| 5.11 | Make it easy for users to delete user data | factory reset |
| 5.12 | Make installation and maintenance of devices easy | maintenance and setup via the boot button |
| 5.13 | Validate input data | order of checks in the protocol, upload validation, fuzzing |

**Binding** only once a product is placed on the market. The cyber security requirements of the Radio Equipment
Directive apply since 1 August 2025; the EN 18031 series has been harmonised for them since January 2025, with
restrictions — for example no presumption of conformity for EN 18031-2 if the user may skip setting a password. The
device password therefore cannot be disabled. The Cyber Resilience Act applies in full from 11 December 2027.

---

## 8. Failure behaviour and diagnostics

### 8.1 Guiding principle

**Every fault becomes a defined operating state, never a crash.** The order of resilience is: open the door > deliver
the ring > play the sound > send the push > serve the status page. When something fails, it fails from the back.

| Fault | Behaviour |
|---|---|
| No WLAN | device runs, send attempts fail immediately with a failure tone, LED red |
| Peer unreachable | LED red after three missed heartbeats; a ring ends after ≈ 1.2 s with a failure tone |
| Sound file missing or corrupt | continues silently, log entry |
| File system cannot be mounted | continues silently, all other functions remain |
| No internet | no push, no remote opening; everything else untouched |
| All send slots occupied | immediate failure tone instead of silent discard |
| Firmware hangs | watchdog → restart; the door opener pulse ends via the hardware timer anyway |
| Crash | core dump to flash, restart, cause on the status page |
| Faulty update | rollback to the previous slot |

**Rollback needs a real self-test.** Out of the box the Arduino core confirms a new update immediately at start-up:
`verifyOta()` returns `true` before `setup()` even runs. An update that boots but no longer joins the WLAN would thus
be kept for good — and could not receive another update. ClearBell therefore overrides `verifyRollbackLater()` and
confirms an update only once WLAN, the peer and the update path work; otherwise it returns to the previous version.

### 8.2 Status LED

Two colours (red 630 nm / green 570 nm in one package), both channels active HIGH and PWM capable.

| Display | Meaning |
|---|---|
| **green** | **Ready** — device running, WLAN up, peer answers the heartbeat |
| **red** | **Fault** — no WLAN, or peer unreachable |
| **amber** (red + green) | **Ring acknowledged** — the press got through |
| off | no supply, or firmware not running yet |

* **During boot the LED is necessarily dark.** Neither pin is a strapping pin; both float after reset. **Every
  indication is a deliberate statement by the firmware.**
* **Amber is created optically, not electrically.** The two dies sit 1.2 mm apart; whether they blend into one colour is
  decided by the diffuser in the wooden front panel — to be judged during bring-up with the light guide fitted.
* Green appears brighter than the current suggests (1.87 mA green against 2.07 mA red), because 570 nm sits closer to
  the eye's peak sensitivity; the correction belongs in firmware via PWM.

**Blink patterns, night dimming, the maintenance indication and the colour semantics of the indoor unit are [open]**
and can be decided during bring-up without any hardware change.

### 8.3 Status page [V0.2 — design]

A small HTTP page per unit on the local network, in the IDF HTTP server's own task — **read-only, with a device
password**:

| Area | Content |
|---|---|
| RF | RSSI, channel, BSSID, connection drops |
| Protocol | sent / acknowledged / retried / lost, discarded and rate-limited packets, sessions |
| **Touch** | **raw value and hardware baseline per channel** |
| Door openings | the log according to section 6.4 — on each unit only what it may show |
| Audio | volume, last file, file listing |
| System | firmware version, uptime, restart cause, minimum free heap, active OTA slot |

**Write actions** — upload a sound, update, settings — exist **only in maintenance**. **There is no “open door”
action.**

The touch row is the real reason for the page: it makes drift measurable *before* it causes misbehaviour, and it
provides the basis for the one retrofit option the hardware keeps open (shield/guard on the reserved GPIO6/14).

### 8.4 Logging and debugging

USB-CDC over the service socket that exists anyway; the built-in USB-JTAG for debugging with GDB/OpenOCD runs over the
same socket. After a crash a core dump is in flash. As a fallback, TXD0/RXD0 are routed to test points; together with
EN, IO0, 3V3 and GND that forms a complete flashing path without USB.

---

## 9. Conventions

| Rule | Reason |
|---|---|
| **Identifiers and comments in English** | consistent with the English APIs; readable for anyone who reads the code. The reasoning is documented in detail in the documents. |
| **Pin constants = schematic net names** | prevents transcription errors between hardware and software; “EG”/“OG” are the German names of the apartments there and are commented in the code |
| **Project prefix `CB_` for constants** | identifiers such as `STATUS`, `OK` or `ERROR` collide with ESP32 ROM headers — a real and hard-to-find error |
| **Configuration lives in the repository** | `sdkconfig.defaults`, `partitions.csv`, pinned versions — every build is reproducible |
| **Secrets never in the repository and never in an image** | they reach the device by provisioning |
| **Explicit serialisation** instead of `packed struct` | fixed byte order, testable in unit tests |
| **No dynamic strings in long-running paths** | no creeping heap fragmentation |
| **Warnings as errors**, static analysis | errors early rather than in the field |
| **MAC via `esp_read_mac(..., ESP_MAC_WIFI_STA)`** | `WiFi.macAddress()` returns zeros before WLAN start-up |
| **I2S sine with a 2π-wrapped phase accumulator** | a growing index loses float precision → audible distortion |
| **Exactly one unit type per image**, checked at compile time | prevents mis-flashed devices |
| **Versions per SemVer**, Git tags, changelog | every device shows what it runs |

---

## 10. Porting plan V0.1 → V0.2

### 10.1 What carries over — and what does not

| Building block | Disposition |
|---|---|
| Protocol principles — application acknowledgement, acknowledge before acting, 300 ms / 3 retries | **carried over** — validated, confirmed in endurance testing |
| Packet format and duplicate detection | **replaced** by protocol v2 with sessions |
| Door command with NVS counter | **replaced** by challenge–response |
| WAV parser and volume logic | carried over, plus upload validation and sound ranking |
| WLAN upkeep | **new** — event-driven, with growing intervals |
| Push and remote opening | **new** — TLS validation, phone signature |
| Touch evaluation | **new** — hardware baseline, M-34, arming window |
| Web triggering of the door opener (test sketch) | **dropped** |
| Pin assignment | replaced entirely |
| SD card / SPI | dropped → LittleFS |
| Audio at loop cadence | → audio task |
| Door opener stub | → door task |
| `clearbell_protocol.h` (ESP-NOW leftovers) | **delete** |

### 10.2 Order of work

No software step begins before the corresponding hardware stage has been signed off during bring-up.

```mermaid
graph TB
    subgraph A["Foundation"]
        direction LR
        S1["1 · Scaffold<br/>IDF project, versions,<br/>partitions, bootloader,<br/>watchdog, CI, tests"] --> S2["2 · Safe default state<br/>door pin, SD_MODE,<br/>modes, provisioning"]
    end
    subgraph B["Communication and security"]
        direction LR
        S3["3 · Network<br/>WLAN, protocol v2,<br/>sessions, heartbeat"] --> S4["4 · Door command<br/>challenge–response,<br/>rate limiting"]
    end
    subgraph C["Peripherals"]
        direction LR
        S5["5 · Audio<br/>LittleFS, WAV,<br/>task, ranking"] --> S6["6 · Touch<br/>hardware baseline,<br/>arming window"] --> S7["7 · Door opener<br/>door task, pulse,<br/>lockout"]
    end
    subgraph D["Operation and maintenance"]
        direction LR
        S8["8 · Diagnostics<br/>status page,<br/>log, LED"] --> S9["9 · Remote opening<br/>TLS validation,<br/>phone signature"] --> S10["10 · Updates<br/>signed, rollback<br/>after self-test"]
    end
    S0["Bring-up passed"] --> A
    A --> B --> C --> D --> S11["11 · Acceptance<br/>7 h, then 72 h"]
```

Why the door command (4) comes before audio (5), even though audio is more visible: the front door is asset number one.
Its path gets finished while attention is fresh — not at the end, when everything else already works and the pressure
to be done is rising. For the same reason operating modes and provisioning sit in step 2: without them, the first tests
would once again rely on compiled-in secrets.

**Whatever cannot be changed safely later belongs in step 1:** the partition table, the bootloader with the rollback
logic, and signature verification for updates. Bootloader and partition table are not replaced after installation,
and a first image without signature verification would accept every subsequent update. The watchdog belongs at the
start for the same reason: every task registers with it from day one. Step 10 then only builds the update path
itself — upload in maintenance mode, self-test, fallback.

### 10.3 Acceptance criteria

The port counts as complete when **all** of the following hold:

- [ ] Feature parity with V0.1: both ring paths, door command, success and failure tones
- [ ] The door opens only via ① and ③; the security and robustness tests from section 11.2 pass
- [ ] Remote opening with phone signature on Android; TLS with a wrong certificate fails
- [ ] Chime replaceable without a PC (maintenance, upload)
- [ ] Signed update without a cable; a deliberately broken update rolls back
- [ ] A factory reset erases all secrets; re-provisioning works
- [ ] Touch raw values and baseline on the status page; arming window and 3 s hold tested
- [ ] Door opener tested on a dummy load **and** on the real load
- [ ] Modem sleep and the times from section 1.3 measured and documented
- [ ] **7-hour endurance test** with no packet loss, no restart, no memory leak — plus **72 h** before installation

The 7-hour test is the criterion V0.1 was measured against and thus provides a direct comparison. The 72 h are added
because heap fragmentation only shows over days.

---

## 11. Test strategy

### 11.1 Hardware bring-up (precedes the software)

Fixed order, each stage signed off before the next begins:

```
Supply → USB / flash → I2S output → I2S microphone → touch (incl. moisture test)
→ door opener dry run → RF validation at the real mounting locations
```

**Never power a populated board blindly** — measure first, then flash. The first door-opener attempt runs on a
multimeter or a dummy load, **not** on the real door opener; that is a lesson from V0.1.

Known from layout and design and explicitly to be measured:

| Point | Why |
|---|---|
| Ripple on +3V3 and overshoot at the switch node **indoors** | the input capacitor sits 4.2 mm from the regulator input — deliberately left that way |
| **Temperature of the outdoor amplifier** | its thermal pad has no via on the outdoor board; whether the copper pour suffices is unverified |
| **Indoor current budget** | +3V3 ≈ 0.77 A peak against 1 A allowed, from VBUS ≈ 0.58 A — more than a USB 2.0 PC port supplies |
| The times from section 1.3 | with and without modem sleep |
| Hardware baseline while touched, denoise channel | basis for section 5.6 |
| Does `i2s.write()` block? Lead time after `SD_MODE`? | basis for the audio task |

### 11.2 Software tests

| Level | Content | Criterion |
|---|---|---|
| **Component** | HMAC against the test vectors of RFC 4231 | bit-for-bit match |
| | protocol v2 serialisation | round trip lossless, edge cases rejected |
| | WAV parser against unknown chunks, odd lengths, wrong bit depth, truncated files | no crash, clean rejection |
| | send state machine with simulated packet loss | exactly 3 retries, then failure |
| **Security** | message with a wrong tag, foreign receiver, unknown version | discarded, not answered |
| | replay a recorded `DOOR_CONFIRM` | discarded |
| | random number after expiry or used twice | discarded |
| | remote opening with a wrong signature, a consumed or expired token, a revoked phone | discarded, logged |
| | TLS against a server with a wrong certificate | connection fails |
| | ask the status page to open the door | there is nothing to ask |
| | upload or update outside maintenance | rejected |
| | packet flood on the UDP port | rate limit applies, ringing keeps working |
| **Robustness** | restart the outdoor unit between two rings | both rings arrive |
| | fully reflash and re-provision an indoor unit | door commands work immediately |
| | power loss during update, NVS write, upload | device starts in a valid state |
| | deliberately broken update | rollback |
| | switch the WLAN off during operation and back on | reconnect without restart |
| | wet cloth on the electrode, both outdoor buttons at once | no trigger |
| | tap indoors inside the window; outside the window; hold for 3 s | opens; does not open; opens |
| **Endurance** | 7 h, then 72 h | no loss, no restart, free heap stable |
| **Field** | moisture test on the mounted outdoor unit | baseline drifts, no false trigger |

### 11.3 Infrastructure

* **Unit tests on a PC** for everything without a hardware dependency: protocol, HMAC, WAV parser, state machines.
* **Automated build** of both unit types on every change (GitHub Actions with ESP-IDF).
* **Fuzzing** of the two parsers that accept data from outside: UDP frames and WAV files.
* **Static analysis** and warnings as errors.

---

## 12. To be decided

Five behavioural questions are deliberately open. None affects the board; all can wait until bring-up.

**F-1 · Ring retry when an indoor unit is unreachable.** Today: 3 retries within ≈ 1.2 s, then a failure tone.
> **Recommendation: keep it.** Someone who is not home will not be home in 30 seconds either; the push covers the case
> more sensibly.

**F-2 · Feedback on a failed door command.** Today: failure tone indoors.
> **Recommendation: keep the tone, add the reason to the status page** (no WLAN / no answer / rejected).

**F-3 · Door opener pulse duration.** Today: 2000 ms as a starting value, never exercised on real hardware.
> **Recommendation: determine it during bring-up on the actual door opener** and record it together with the
> measurement conditions.

**F-4 · Outdoor unit behaviour without WLAN.** Today: immediate failure tone.
> **Recommendation: a distinguishable notice tone rather than a chime** — a chime would falsely signal to the visitor
> that somebody had been notified.

**F-5 · When may the microphone be active?** Decided already: no storage, no hardware indicator.
> **Recommendation: only after a bell press or on explicit request**, never continuously.

**Implementation details that bring-up settles** (without a new decision of principle): upper limit of the long press
and whether the arming window closes after the first opening (5.6) · validity of the push token (4.5) · press durations
of the operating modes (5.9) · blink patterns and the maintenance indication (8.2) · signing scheme on iOS (4.5).

**Decided on 2026-09-26** (recorded in the project as R17–R23):

| | Decision |
|---|---|
| R17 | The status page does not open the door — path ② removed |
| R18 | Indoors: a short tap only within 2 min after a ring, otherwise hold for 3 s |
| R19 | Door-opening log separated per household |
| R20 | Remote opening: the phone signs itself |
| R21 | Build as an ESP-IDF project with Arduino as a component |
| R22 | Hardening in stages; stage C only outdoors, after mounting and stable operation |
| R23 | Identifiers and comments in the code in English |

---

## 13. Deliberately out of scope

A **scope freeze** has been in force since 2026-08-20: new ideas go into the V0.3 backlog. Exceptions exist only for
defects that would make V0.2 unusable or unsafe — the findings of the review belong to them.

| Not in V0.2 | Rationale |
|---|---|
| On-device speech recognition | Espressif's recognition models support no German; recognition runs externally |
| Intercom | the hardware keeps the option open (microphone, PSRAM, WLAN); target state half duplex |
| Door opener driver inside the secured area | requires hardware — earmarked for V0.3 |
| Remote opening on iOS, a dedicated app | only needed with a possible sale |
| Camera, battery operation, cloud connection | explicitly outside the target picture |
| Shield / guard ring | only if touch drift appears in the field; GPIO6/14 stay free for it |
| Amplifier from 5 V | verified and permissible (+3.9 dB), rejected — the level at 3.3 V suffices |

---

## 14. Glossary

| Term | Meaning |
|---|---|
| **GF / UF** | ground floor and upper floor apartment — the two households (German: EG / OG) |
| **Challenge–response** | the verifying side poses a fresh random challenge; the answering side proves with its key that it knows it |
| **HMAC** | a keyed checksum; without the key it cannot be produced |
| **Tag** | the HMAC truncated to 128 bits, attached to every message |
| **Token** | a one-time random number for a single remote opening |
| **Session** | the period between two restarts of a unit, identified by a random number |
| **Heartbeat** | periodic `PING`/`PONG` to check reachability and establish sessions |
| **Provisioning** | the one-off setup of role, keys and WLAN credentials on a device |
| **Maintenance / setup** | operating modes reachable only via the boot button on the device |
| **Arming window** | the 2 min after a ring during which a short tap indoors opens the door |
| **Baseline** | the resting value of a touch channel, tracked by the hardware (“benchmark”) |
| **NVS** | key-value storage in flash |
| **OTA** | firmware update over the network, into two alternating app slots |
| **eFuse** | one-time programmable bits in the chip; for keys and security switches |
| **Secure boot** | the chip only starts signed firmware |
| **DTIM** | the interval at which the router tells sleeping stations about waiting packets |
| **Modem sleep** | a WLAN power-saving mode in which the connection is kept |
| **PMF** | protected management frames — protection against forged deauthentication frames |
| **PDM** | pulse-density modulation, the microphone's interface |
| **CSRF** | cross-site request forgery — a foreign website makes a user's browser trigger an action on the home network |

---

## 15. Referenced documents and sources

| Document | Content |
|---|---|
| [`Funkvalidierung_ESPNOW.md`](Funkvalidierung_ESPNOW.md) | measurements and rationale for the transport choice (German) |
| [`../README.md`](../README.md) | V0.2 hardware overview, fabrication data (German) |
| [`../archiv/V0.1/firmware/`](../archiv/V0.1/firmware/) | running V0.1 firmware, test sketches |
| Internal project document set | project plan, design decisions R1–R23, GPIO mapping, review of the software architecture — not public |

**External sources** (retrieved 2026-09-26):

* ETSI EN 303 645 V3.1.3 (2024-09) — https://www.etsi.org/deliver/etsi_en/303600_303699/303645/03.01.03_60/en_303645v030103p.pdf
* Delegated Regulation (EU) 2023/2444 (application of (EU) 2022/30 from 1 August 2025) — https://eur-lex.europa.eu/legal-content/EN/TXT/PDF/?uri=OJ:L_202302444
* Implementing Decision (EU) 2025/138 (EN 18031) — https://op.europa.eu/en/publication-detail/-/publication/16a8f500-deab-11ef-be2a-01aa75ed71a1/
* Cyber Resilience Act, European Commission summary — https://digital-strategy.ec.europa.eu/en/policies/cra-summary
* NIST SP 800-107 Rev. 1, section 5.3 (truncated HMAC; withdrawal announced) — https://csrc.nist.gov/publications/detail/sp/800-107/rev-1/final
* ESP-IDF: HMAC peripheral, NVS encryption, random numbers, secure boot v2, eFuse, touch sensor, WLAN security — https://github.com/espressif/esp-idf/tree/master/docs/en
* Arduino-ESP32: Arduino as an ESP-IDF component — https://github.com/espressif/arduino-esp32/blob/master/docs/en/esp-idf_component.rst · secure boot and flash encryption — https://github.com/espressif/arduino-esp32/issues/8974
* ntfy: access control, data retention, action buttons — https://github.com/binwiederhier/ntfy/tree/main/docs · pricing — https://ntfy.sh/
* HTTP Shortcuts (Android): scripting and deep links — https://http-shortcuts.rmy.ch/scripting · https://http-shortcuts.rmy.ch/advanced
* 2N Security Relay (switching stage inside the secured area) — https://www.2n.com/en-US/faqs/2N-Security-Relay-Describtion-and-usage-with-2N-IP-Intercoms-kA0Rn000000ttogKAA

**Datasheets** are not included for copyright reasons; all part numbers appear in the bills of materials.

---

## 16. Revision history

| Rev. | Date | Change |
|---|---|---|
| 1 | 2026-09-20 | First version |
| 1a | 2026-09-26 | Diagrams corrected: topology (UF indoor unit complete, indoor microphones, HTTPS via the router), layers, order of work; in the door command diagram acknowledgement before opening, as in the code |
| 2 | 2026-09-26 | Revision after a review with 29 findings: path ② removed; protocol v2 with authentication of every message and sessions; challenge–response instead of a counter; remote opening with phone signature; arming window indoors; operating modes and provisioning; ESP-IDF with Arduino component; rollback after a self-test; watchdog for all tasks; door-opening log per household; hardening in stages; new: quality goals, alignment with EN 303 645, glossary |

---

*ClearBell V0.2 · Software architecture · Revision 2 · 2026-09-26*

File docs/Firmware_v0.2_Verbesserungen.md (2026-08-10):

# ClearBell – Verbesserungen für v0.2

Lebende Datei. Wird während Prototypenbau / Inbetriebnahme (IBN) laufend ergänzt.
Stand: 2026-07-03.

---

## Offene Punkte

| Nr. | Bereich | Beschreibung | Betrifft | Priorität | Status |
|-----|---|---|---|---|---|
| V01 | Layout | Testpunkte einplanen (3V3-Rail, GND-Referenzen, Touch-Leitungen, I2S-Bus BCLK/DIN/LRCLK, SPI-SD-Bus) | Außen + Innen | Mittel | Offen |
| V02 | Schematic | **Q1 (DMG2305UX-7) Symbol-Pinbelegung korrigieren** – SnapEDA-Symbol hat D/S/G falsch nummeriert | Außeneinheit | **Kritisch** | Offen |
| V03 | Schematic | **Q2 (IRLML6344) gegen Datenblatt prüfen** – gleiches SnapEDA-Fehlerbild wie Q1 möglich; Q2 schaltet den Türöffner | Außeneinheit | Hoch | Offen |
| V04 | Schematic | MAX98357 SD_MODE über GPIO steuerbar machen (aktuell fest auf 3V3 → keine SW-Abschaltung) | Außen + Innen | Niedrig–Mittel | Offen |
| V05 | Layout | Antenne von Variante B → A (Überhang) wechseln, **falls Reichweite unzureichend**; 15-mm-Keepout inkl. GND-Flood/Vias auf allen Lagen sicherstellen | Außen + Innen | Mittel (bedingt) | Offen |
| V06 | Schematic | Pull-ups (10 kΩ) auf SD-SPI-Leitungen (MISO, MOSI, SCK, CS) nach 3V3 ergänzen | Außen + Innen | Mittel | Offen |
| V07 | BOM/HW | Modul N8 → **N8R2** (2 MB PSRAM) erwägen – reine RAM-Reserve | Außen + Innen | **Optional / Niedrig** | Offen |
| V08 | Layout | **S_RST + S_BOOT (PTS526) um 90° verdreht platziert** – EN und GPIO0 liegen auf GND, ESP startet nicht | Inneneinheit | **Kritisch** | Nacharbeit v0.1 erledigt / Layoutfix offen |
| V09 | BOM/Layout | Klemmen 2086-1202 (THT) → **WAGO 2060-452/998-404 (SMD)** – Bauhöhe reduzieren; Prüfpunkte siehe Detail | Außen + Innen | Mittel | Offen |
| V10 | BOM/HW | Lautsprecher vereinheitlichen: **K 36 WP auch innen?** – Hörtest erforderlich | Inneneinheit | Niedrig–Mittel | Prüfen |
| V11 | Schematic/BOM | **S_RST/S_BOOT durch 2-polige Taster ersetzen**; zusätzlich prüfen: Auto-Programmierung über DTR/RTS → Taster ggf. ganz entfallen | Außen + Innen | Mittel–Hoch | Offen |

---

## Detail

### V02 – Q1 (DMG2305UX-7) Symbol-Pinbelegung falsch  *(kritisch)*
**Einheit:** Außeneinheit, Power-Block.

SnapEDA-**Symbol** hat die Pin-Nummern falsch den Funktionen (D/S/G) zugeordnet →
Netze lagen im Layout rotiert auf den Pads:

| Pad (Footprint) | Pin lt. Datenblatt DS36196 | Netz v0.1 (falsch) | Soll |
|---|---|---|---|
| Pad 3 (Einzelpin) | Drain | +12V | Net-(Q1-D) → LMR-VIN |
| Pad 1 | Gate | Net-(Q1-D) → LMR-VIN | Gate-Netz (DZ1/Rg1) |
| Pad 2 | Source | Gate-Netz (DZ1-A) | +12V |

Footprint korrekt, **Fehler liegt im Symbol.**

**Auswirkung v0.1:** Q1 leitete nicht (kein Stromfluss → keine 3,3 V). Gemessen
VGS = −11,5 V gegen VGS(max) ±8 V → **Q1 vermutlich gate-oxid-geschädigt, ersetzen.**
DZ1 (BZX84-C7V5) konnte nicht klemmen (lag nicht über echter GS-Strecke).

**Korrektur v0.2:**
1. Symbol-Pin-Nummern **G=1, S=2, D=3** (Datenblatt DS36196, Top View) – im Bibliotheks-Symbol.
2. „PCB aus Schaltplan aktualisieren" (erlaubt).
3. **NICHT** „Symbole aus Bibliothek aktualisieren" (überschreibt Fixes).
4. Neu verdrahten + DRC.

**v0.1-Workaround (vorhandene Platine):** Q1 ausgelötet, Lötbrücke Pad 3 (+12V) →
Pad 1 (LMR-VIN). **Verpolschutz entfällt → nur Laborbetrieb mit fester Polarität,
nicht für Endeinbau.** D1 (SMBJ15A) bleibt wirksam.

**Prozess-Lehre:** SnapEDA-Symbol-Pinnummern beim Import IMMER gegen das Datenblatt
prüfen. DRC fängt semantische Pin-Mapping-Fehler nicht.

### V03 – Q2 (IRLML6344) Datenblatt-Verifizierung ausstehend
Q2 (Türöffner-MOSFET, Gate an GPIO21 via R_GATE1 100 Ω) ist noch **nicht** gegen sein
Datenblatt auf dasselbe SnapEDA-Pin-Mapping-Fehlerbild wie Q1 geprüft. Ein vertauschtes
Source/Drain kann beim Schalten Schaden anrichten. **Vor erneuter Bestückung/Fertigung
bzw. vor dem Türöffner-Test prüfen.**

### V04 – MAX98357 SD_MODE fest auf 3V3
SD_MODE hart auf +3V3 → Amp dauerhaft aktiv, Ausgang (L+R)/2, GAIN auf GND (15 dB),
**keine GPIO-Abschaltung** aus der Firmware. Für v0.1 funktional, aber kein SW-Mute.
**v0.2:** SD_MODE GPIO-steuerbar (Mode-Select-Widerstand: GPIO-Low = Shutdown,
GPIO-High = (L+R)/2). **Vor Umbau verifizieren:** MAX98357-Datenblatt – Auto-Sleep bei
fehlendem I2S-Takt + exakte SD_MODE-Schwellen/Widerstandswerte.

### V05 – Antenne Variante B → A / Keepout
Aktuell **Variante B** (Antenne vollständig auf PCB). Plan: in v2 auf **Variante A**
(über Platinenrand) wechseln, **falls** Reichweite im Zwei-Familienhaus unzureichend.
Bei Variante B ist die 15-mm-Keepout Pflicht – auf **allen Lagen**, inkl.
GND-Flood-Aussparung auf Bottom und keine Vias in der Zone. **Voraussetzung für die
Entscheidung:** systematische Reichweitenmessung (RSSI im Firmware-Test berücksichtigen).

### V06 – Pull-ups auf SD-SPI-Leitungen
Auf v0.1 fehlen Pull-ups auf den SD-Leitungen. **v0.2:** je 10 kΩ von MISO (GPIO19),
MOSI (GPIO23), SCK (GPIO18) und CS (GPIO5) nach 3V3.
**Hinweis:** Empfohlene Praxis für SD-über-SPI, **nicht** die Ursache des v0.1-NONE-Problems
(das war ein falscher CS-Pin im Test-Sketch, GPIO17 statt GPIO5 – HW war korrekt).
Bewusst ergänzt, da robust und schadlos. Pin-Mapping Innen ≠ Außen beachten.
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

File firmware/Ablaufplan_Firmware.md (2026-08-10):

# ClearBell – Firmware Entwicklungsplan

## Ziel
Vollständige, eigenständige Firmware für Außen- und Inneneinheit.
Kein ESPHome, kein Home Assistant, kein externer Server.

---

## Übersicht: Phasen

```
Phase 0  │  Vorbereitung         │  Jetzt  ─────────────────────────────────────┐
Phase 1  │  Hardware IBN         │  wenn PCBs da                                │
Phase 2  │  Komponententests     │  Bottom-up, je Modul                         │
Phase 3  │  Integration          │  alles zusammen                              │
Phase 4  │  Robustheit           │  Dauerbetrieb, Fehlerverhalten               │
Phase 5  │  Abschluss            │  Einbau, Dokumentation fertig                │
```

---
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

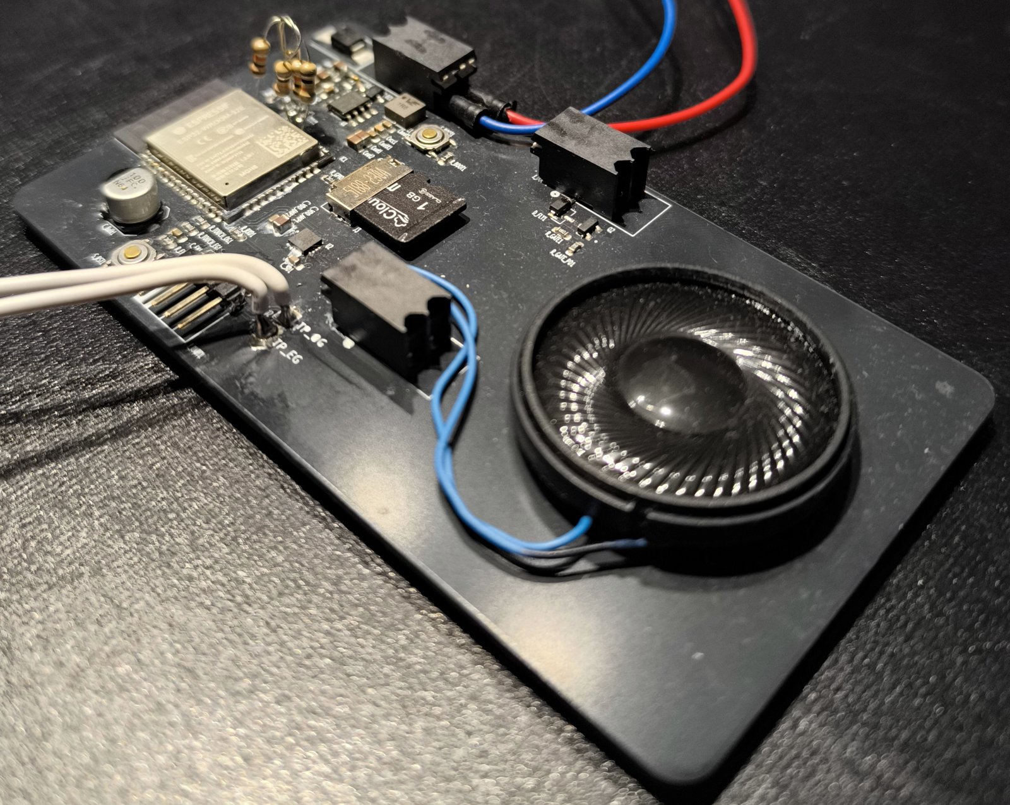
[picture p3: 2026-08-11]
docs/img/hero.jpg

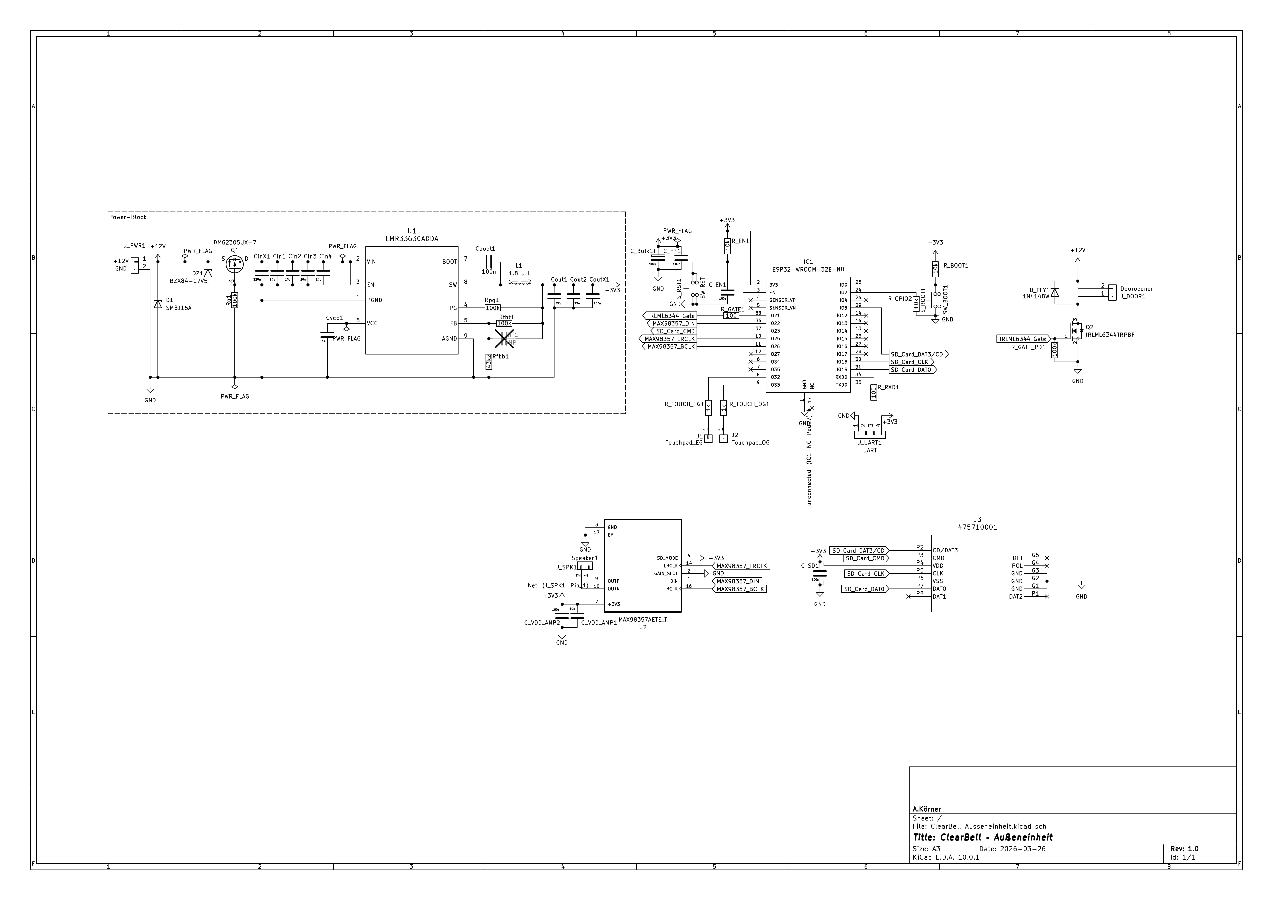
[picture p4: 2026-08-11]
docs/img/schaltplan.jpg

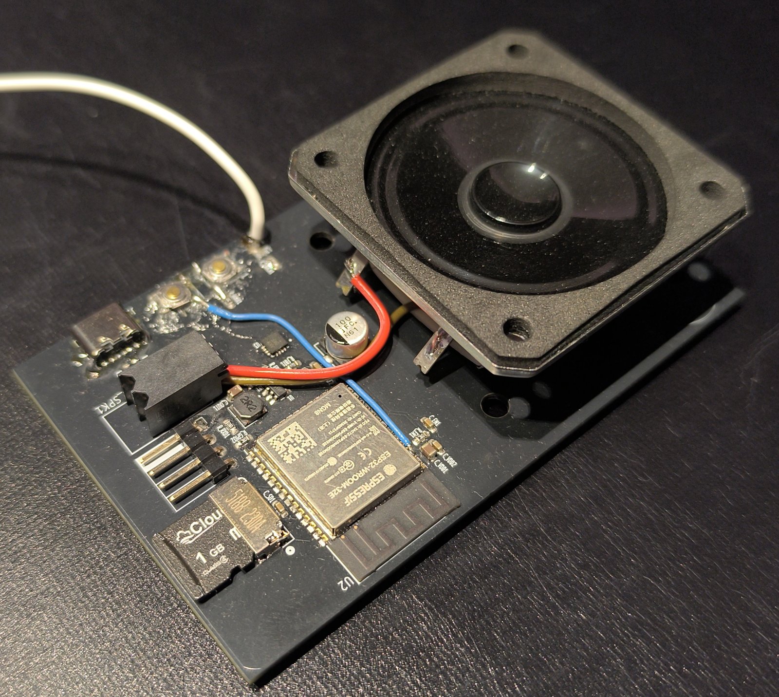
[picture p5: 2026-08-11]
docs/img/pcb_innen.jpg

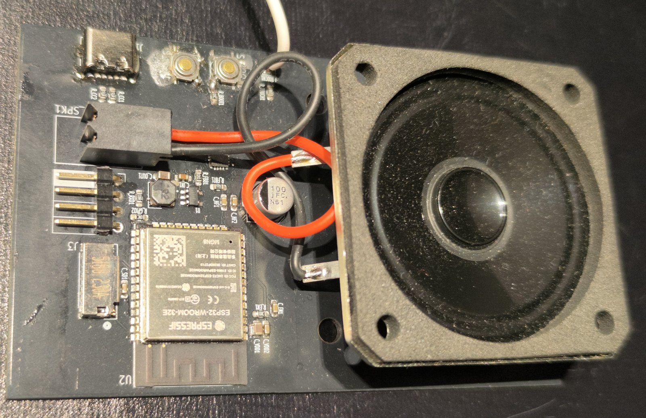
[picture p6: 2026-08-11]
docs/img/prototyp.jpg

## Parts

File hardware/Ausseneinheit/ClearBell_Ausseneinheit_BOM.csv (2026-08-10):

Reference | Qty | Value | DNP | Exclude from BOM | Exclude from Board | Footprint | Datasheet
Cboot1 | 1 | 100n |  |  |  | Capacitor_SMD:C_0603_1608Metric_Pad1.08x0.95mm_HandSolder
Cff1 | 1 | DNP | Nicht bestücken |  |  | Capacitor_SMD:C_0603_1608Metric_Pad1.08x0.95mm_HandSolder
Cin1,Cin2,Cin3,Cin4 | 4 | 10u |  |  |  | Capacitor_SMD:C_0805_2012Metric_Pad1.18x1.45mm_HandSolder
CinX1 | 1 | 220n |  |  |  | Capacitor_SMD:C_0603_1608Metric_Pad1.08x0.95mm_HandSolder
Cout1,Cout2 | 2 | 22u |  |  |  | Capacitor_SMD:C_0603_1608Metric_Pad1.08x0.95mm_HandSolder
CoutX1 | 1 | 100n |  |  |  | Capacitor_SMD:C_0603_1608Metric_Pad1.08x0.95mm_HandSolder
Cvcc1 | 1 | 1u |  |  |  | Capacitor_SMD:C_0603_1608Metric_Pad1.08x0.95mm_HandSolder
C_Bulk1 | 1 | 100u |  |  |  | Capacitor_SMD:C_Elec_6.3x5.4
C_EN1 | 1 | 100n |  |  |  | Capacitor_SMD:C_0603_1608Metric_Pad1.08x0.95mm_HandSolder
C_HF1 | 1 | 100n |  |  |  | Capacitor_SMD:C_0603_1608Metric_Pad1.08x0.95mm_HandSolder
C_SD1 | 1 | 100n |  |  |  | Capacitor_SMD:C_0603_1608Metric_Pad1.08x0.95mm_HandSolder
C_VDD_AMP1 | 1 | 10u |  |  |  | Capacitor_SMD:C_0603_1608Metric_Pad1.08x0.95mm_HandSolder
C_VDD_AMP2 | 1 | 100n |  |  |  | Capacitor_SMD:C_0603_1608Metric_Pad1.08x0.95mm_HandSolder
D1 | 1 | SMBJ15A |  |  |  | Diode_SMD:D_SMB-SMC_Universal_Handsoldering
DZ1 | 1 | BZX84-C7V5 |  |  |  | Package_TO_SOT_SMD:SOT-23
D_FLY1 | 1 | 1N4148W |  |  |  | Package_TO_SOT_SMD:SOT-23 | https://www.vishay.com/docs/85748/1n4148w.pdf
IC1 | 1 | ESP32-WROOM-32E-N8 |  |  |  | ESP32-WROOM-32E-N4:ESP32WROOM32EN8 | https://www.espressif.com/sites/default/files/documentation/esp32-wroom-32e_esp32-wroom-32ue_datasheet_en.pdf
J1 | 1 | Touchpad_EG |  |  |  | TestPoint:TestPoint_Pad_2.0x2.0mm
J2 | 1 | Touchpad_OG |  |  |  | TestPoint:TestPoint_Pad_2.0x2.0mm
J3 | 1 | 475710001 |  |  |  | MOLEX MICRO SD CARD_475710001:MOLEX MICRO SD CARD_475710001 | https://www.molex.com/en-us/products/part-detail-pdf/475710001?display=pdf
J_DOOR1 | 1 | Dooropener |  |  |  | Wago_2086-1202:Wago_2086-1202
J_PWR1 | 1 | WAGO_2086-1202 |  |  |  | Wago_2086-1202:Wago_2086-1202
J_SPK1 | 1 | Speaker1 |  |  |  | Wago_2086-1202:Wago_2086-1202
J_UART1 | 1 | UART |  |  |  | Connector_PinSocket_2.54mm:PinSocket_1x04_P2.54mm_Horizontal
L1 | 1 | 4020HT_74438356018HT |  |  |  | Inductor_SMD_Wurth:L_Wurth_WE-MAPI-4020HT | https://www.we-online.com/catalog/datasheet/74438356018HT.pdf?ki
Q1 | 1 | DMG2305UX-7 |  |  |  | Package_TO_SOT_SMD:SOT-23 | https://www.panjit.com.tw/upload/datasheet/PJA3415.pdf
Q2 | 1 | IRLML6344TRPBF |  |  |  | IRLML6344:TRANS_IRLML6344TRPBF
Rfbb1 | 1 | 43k2 |  |  |  | Resistor_SMD:R_0603_1608Metric_Pad0.98x0.95mm_HandSolder
Rfbt1 | 1 | 100k |  |  |  | Resistor_SMD:R_0603_1608Metric_Pad0.98x0.95mm_HandSolder
Rg1 | 1 | 100k |  |  |  | Resistor_SMD:R_0603_1608Metric_Pad0.98x0.95mm_HandSolder
Rpg1 | 1 | 100k |  |  |  | Resistor_SMD:R_0603_1608Metric_Pad0.98x0.95mm_HandSolder
R_BOOT1 | 1 | 10k |  |  |  | Resistor_SMD:R_0603_1608Metric_Pad0.98x0.95mm_HandSolder
R_EN1 | 1 | 10k |  |  |  | Resistor_SMD:R_0603_1608Metric_Pad0.98x0.95mm_HandSolder
R_GATE1 | 1 | 100 |  |  |  | Resistor_SMD:R_0603_1608Metric_Pad0.98x0.95mm_HandSolder
R_GATE_PD1 | 1 | 100k |  |  |  | Resistor_SMD:R_0603_1608Metric_Pad0.98x0.95mm_HandSolder
R_GPIO2 | 1 | 10k |  |  |  | Resistor_SMD:R_0603_1608Metric_Pad0.98x0.95mm_HandSolder
R_RXD1 | 1 | 100 |  |  |  | Resistor_SMD:R_0603_1608Metric_Pad0.98x0.95mm_HandSolder
R_TOUCH_EG1 | 1 | 1k |  |  |  | Resistor_SMD:R_0603_1608Metric_Pad0.98x0.95mm_HandSolder
R_TOUCH_OG1 | 1 | 1k |  |  |  | Resistor_SMD:R_0603_1608Metric_Pad0.98x0.95mm_HandSolder
S_BOOT1 | 1 | SW_BOOT1 |  |  |  | CK_PTS526:CK_PTS526 | https://www.ckswitches.com/products/switches/product-details/Tactile/PTS526/
S_RST1 | 1 | SW_RST |  |  |  | CK_PTS526:CK_PTS526 | https://www.ckswitches.com/products/switches/product-details/Tactile/PTS526/
U1 | 1 | LMR33630ADDA |  |  |  | LMR33630ADDA:DDA0008J | https://www.ti.com/lit/gpn/lmr33630
U2 | 1 | MAX98357AETE_T |  |  |  | MAX98357AETE_T:QFN50P300X300X80-17N | https://www.analog.com/media/en/technical-documentation/data-sheets/MAX98357A-MAX98357B.pdf

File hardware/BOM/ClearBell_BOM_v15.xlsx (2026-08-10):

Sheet: Vollständige BOM
ClearBell – Stückliste Außeneinheit + Inneneinheit
Rev. 15 | Inneneinheit Lautsprecher: K 50 SQ (Art. 2897) | PCB Inneneinheit 60x75mm | 2026-05-13
Ref. | Bezeichnung | Wert / Typ | Gehäuse | Hersteller | Hersteller-Teilenr. | Lieferant | Lieferant-Teilenr. | Menge | Preis/Stk (€) | Gesamt (€) | Notiz
BLOCK 1 – STROMVERSORGUNG AUSSENEINHEIT
U1 | Step-Down Regler | LMR33630CDDAR | 8SOPWR | Texas Instruments | LMR33630CDDAR | Mouser | 595-LMR33630CDDAR | 1 | 2.190 € | 2.19 € | Step-Down 12V→3,3V, -40..+125°C
L1 | Speicherspule | 1,8µH 26mΩ 6,05A | 5×5mm SMD | Würth Elektronik | 74438356018HT | Digikey | 732-74438356018HTTR-ND | 1 | 1.780 € | 1.78 € | SRF 37,5MHz, IDC 6,05A
Q1 | P-Kanal MOSFET | 20V 4,2A 40mΩ | SOT-23-3 | Diodes Inc. | DMG2305UX-7 | Digikey | DMG2305UX-7DICT-ND | 1 | 0.284 € | 0.28 € | Verpolschutz Eingang; VGS-Clamp via DZ1 (Gate-Source) erforderlich
DZ1 | Zener-Diode | 7,5V 250mW | SOT-23 | Nexperia | BZX84-C7V5,215 | Digikey | 1727-5040-2-ND | 1 | 0.110 € | 0.11 € | VGS-Clamp Q1 Gate-Source; begrenzt VGS auf -7,5V; 1727-5040-1-ND verifiziert (Nexperia-Code 1727, Pattern konsistent)
D1 | TVS-Diode | 15V unidirektional | DO-214AA | Vishay | SMBJ15A-E3/52 | Digikey | SMBJ15A-E3/52GITR-ND | 1 | 0.440 € | 0.44 € | Klemmspg. 24,4V max.
Rfbt | Widerstand | 100kΩ ±1% 0,1W | 0603 | Yageo | RC0603FR-07100KL | Digikey | 311-100KHRCT-ND | 10 | 0.020 € | 0.20 € | Spannungsteiler oben, 10er Gebinde
Rfbb | Widerstand | 43,2kΩ ±1% 0,1W | 0603 | Yageo | RC0603FR-0743K2L | Digikey | 311-43.2KHRCT-ND | 10 | 0.020 € | 0.20 € | Spannungsteiler unten, 10er Gebinde
Rpg | Widerstand | 100kΩ ±1% 0,1W | 0603 | Yageo | RC0603FR-07100KL | Digikey | 311-100KHRCT-ND | 0 | 0.020 € | 0.00 € | Power-Good, gleicher Typ wie Rfbt
Cin | Keramikkondensator | 10µF 25V X7R | 0805 | Murata | GRM21BZ71E106KE15L | Digikey | 490-GRM21BZ71E106KE15LCT | 10 | 0.161 € | 1.61 € | 4x parallel: 4x2,78uF=11,1uF effektiv bei 12V DC-Bias; TI min. 10uF erfuellt; 10er Gebinde reicht; Fallback: GRM32ER71E106KA12L 1210
Cinx | Keramikkondensator | 220nF 25V X7R | 0603 | Murata | GRM188R71E224KA88D | Digikey | 490-3290-2-ND | 10 | 0.041 € | 0.41 € | Eingang HF, 10er Gebinde
Cout1 | Keramikkondensator | 22µF 10V X7R | 0805 | Murata | GRM21BZ71A226ME15L | Digikey | 490-GRM21BZ71A226ME15LCT | 10 | 0.166 € | 1.66 € | Ausgang Bulk, 10er Gebinde
Cout2 | Keramikkondensator | 22µF 10V X7R | 0805 | Murata | GRM21BZ71A226ME15L | Digikey | 490-GRM21BZ71A226ME15LCT | 0 | 0.166 € | 0.00 € | Gleicher Typ wie Cout1
Coutx | Keramikkondensator | 100nF 16V X7R | 0603 | Murata | GCM188R71C104KA37D | Digikey | 490-GCM188R71C104KA37DCT | 10 | 0.020 € | 0.20 € | Ausgang HF + Cboot, 10er Gebinde
Cboot | Keramikkondensator | 100nF 16V X7R | 0603 | Murata | GCM188R71C104KA37D | Digikey | 490-GCM188R71C104KA37DCT | 0 | 0.020 € | 0.00 € | Gleicher Typ wie Coutx
Cvcc | Keramikkondensator | 1µF 25V X7R | 0603 | Würth Elektronik | 885012206076 | Digikey | 732-7994-2-ND | 10 | 0.050 € | 0.50 € | VCC Bypass, 10er Gebinde
Cff | nicht bestückt (DNP) | – | 0603 | – | – | – | – | 0 | 0.000 € | 0.00 € | Footprint vorhanden, unbestückt
 |  |  |  |  |  |  |  |  |  | 9.58 €
BLOCK 2 – ESP32 BESCHALTUNG
U2 | WiFi/BT Modul | ESP32-WROOM-32E-N8 | SMD 38-Pin | Espressif | ESP32-WROOM-32E-N8 | Digikey | 5407-ESP32-WROOM-32E-N8TR-ND | 1 | 4.610 € | 4.61 € | 4MB Flash, CE-zertifiziert; N8 (8MB Flash) gewählt – N4 Preisdiff. <0,50€
C_bulk | Elektrolytkondensator | 100µF 6,3V SMD | Ø6,3×5,4mm | Panasonic | EEEFC0J101P | Mouser | 667-EEE-FC0J101P | 1 | 0.320 € | 0.32 € | Bulk-Puffer ESP32 WiFi-Peaks
C_hf | Keramikkondensator | 100nF 16V X7R | 0603 | Murata | GCM188R71C104KA37D | Digikey | 490-GCM188R71C104KA37DCT | 0 | 0.020 € | 0.00 € | HF-Bypass ESP32, gleicher Typ Coutx
R_EN | Widerstand | 10kΩ ±1% 0,1W | 0603 | Yageo | RC0603FR-0710KL | Digikey | 311-10.0KHRTR-ND | 10 | 0.020 € | 0.20 € | Pull-up Enable Pin, 10er Gebinde
C_EN | Keramikkondensator | 100nF 16V X7R | 0603 | Murata | GCM188R71C104KA37D | Digikey | 490-GCM188R71C104KA37DCT | 0 | 0.020 € | 0.00 € | Entprellung Reset, gleicher Typ
S_RST | Taster SMD | 160gf 1,5mm Hub 12V | 5,2×5,2mm | C&K | PTS526 SK15 SMTR2 LFS | Digikey | CKN12221-2-ND | 10 | 0.122 € | 1.22 € | Reset, nur Entwicklung
R_BOOT | Widerstand | 10kΩ ±1% 0,1W | 0603 | Yageo | RC0603FR-0710KL | Digikey | 311-10.0KHRTR-ND | 0 | 0.020 € | 0.00 € | Pull-up GPIO0, gleicher Typ R_EN
R_GPIO2 | Widerstand | 10kΩ ±1% 0,1W | 0603 | Yageo | RC0603FR-0710KL | Digikey | 311-10.0KHRTR-ND | 0 | 0.020 € | 0.00 € | Pull-down GPIO2, gleicher Typ R_EN
S_BOOT | Taster SMD | 160gf 1,5mm Hub 12V | 5,2×5,2mm | C&K | PTS526 SK15 SMTR2 LFS | Digikey | CKN12221-2-ND | 0 | 0.122 € | 0.00 € | Boot-Modus, gleicher Typ S_RST
J_UART | Pin-Header liegend | 4-Pin 2,54mm 90° | THT | Würth Elektronik | 61300411021 | Digikey | 732-5337-ND | 1 | 0.000 € | 0.00 € | UART Programmierschnittstelle, vorhanden
R_RXD | Widerstand | 100Ω ±1% 0,1W | 0603 | Yageo | RC0603FR-07100RL | Digikey | 311-100HRCT-ND | 10 | 0.020 € | 0.20 € | Schutzwiderstand RXD0, 10er Gebinde
 |  |  |  |  |  |  |  |  |  | 6.55 €
BLOCK 3 – KAPAZITIVE TOUCH-TASTER
R_TOUCH1 | Widerstand | 1kΩ ±1% 0,1W | 0603 | Yageo | RC0603FR-071KL | Digikey | 311-1.00KHRTR-ND | 10 | 0.020 € | 0.20 € | ESD-Schutz Touch EG, 10er Gebinde
R_TOUCH2 | Widerstand | 1kΩ ±1% 0,1W | 0603 | Yageo | RC0603FR-071KL | Digikey | 311-1KHRCT-ND | 0 | 0.020 € | 0.00 € | ESD-Schutz Touch OG, gleicher Typ
J_TOUCH1 | Lotpad | – | – | – | – | – | – | 0 | 0.000 € | 0.00 € | Kein Stecker – Lotpad auf Platine genügt (1-polig)
J_TOUCH2 | Lotpad | – | – | – | – | – | – | 0 | 0.000 € | 0.00 € | Kein Stecker – Lotpad auf Platine genügt (1-polig)
 |  |  |  |  |  |  |  |  |  | 0.20 €
BLOCK 4 – SD-KARTE + CLASS-D + LAUTSPRECHER
J_SD | MicroSD Halter | Push-Push SMD | SMD | Molex | 475710001 | Digikey | WM9731TR-ND | 1 | 0.880 € | 0.88 € | Molex MicroSD Push-Push SMD; Hersteller-Nr. 475710001; DK-Nr. verifiziert
R_SD1 | entfallt | – | 0603 | – | – | – | – | 0 | 0.000 € | 0.00 € | Nicht im Schaltplan – SPI-Leitungen kurz genug, Serienwiderstande nicht erforderlich
R_SD2 | entfallt | – | 0603 | – | – | – | – | 0 | 0.000 € | 0.00 € | Nicht im Schaltplan – SPI-Leitungen kurz genug, Serienwiderstande nicht erforderlich
R_SD3 | entfallt | – | 0603 | – | – | – | – | 0 | 0.000 € | 0.00 € | Nicht im Schaltplan – SPI-Leitungen kurz genug, Serienwiderstande nicht erforderlich
R_SD4 | entfallt | – | 0603 | – | – | – | – | 0 | 0.000 € | 0.00 € | Nicht im Schaltplan – SPI-Leitungen kurz genug, Serienwiderstande nicht erforderlich
C_SD | Keramikkondensator | 100nF 16V X7R | 0603 | Murata | GCM188R71C104KA37D | Digikey | 490-GCM188R71C104KA37DCT | 0 | 0.020 € | 0.00 € | VDD Bypass SD, gleicher Typ Cboot
U3 | Class-D Verstärker | MAX98357AETE+T | TSSOP-16 | Analog Devices | MAX98357AETE+T | Digikey | MAX98357AETE+TCT-ND | 1 | 2.800 € | 2.80 € | I2S, 3,2W@4Ohm, filterfrei
C_AMP1 | Keramikkondensator | 10µF 25V X7R | 0805 | Murata | GRM21BZ71E106KE15L | Digikey | 490-GRM21BZ71E106KE15LCT | 0 | 0.060 € | 0.00 € | VDD Bulk AMP 10µF, gleicher Typ Cout_INN (laut MAX98357A DB)
C_AMP2 | Keramikkondensator | 100nF 16V X7R | 0603 | Murata | GCM188R71C104KA37D | Digikey | 490-GCM188R71C104KA37DCT | 0 | 0.020 € | 0.00 € | VDD HF AMP, gleicher Typ Cboot
Lautsprecher1 | Lautsprecher | 36mm 8Ohm 1W WP | 36mm rund | Visaton | K 36 WP | Digikey | 2056-K36WP-8OHM-ND | 1 | 6.380 € | 6.38 € | Weatherproof, Außeneinheit
J_SPK | WAGO Steckklemme | 2-polig 1,5mm² 3,5mm | SMD | WAGO | 2086-1202 | WAGO | 2086-1202 | 1 | 0.000 € | 0.00 € | Lautsprecher Anschluss, gleicher Typ J_DOOR
 |  |  |  |  |  |  |  |  |  | 10.06 €
BLOCK 5 – TÜRÖFFNER
Q2 | N-Kanal MOSFET | 30V 5A Logic-Level | SOT-23 | Infineon | IRLML6344TRPBF | Mouser | 942-IRLML6344TRPBF | 1 | 0.550 € | 0.55 € | Türöffner Treiber, DNP
D_FLY1 | Schaltdiode | 100V 300mA | SOD-123W | Vishay | 1N4148W-E3-18 | Digikey | 1N4148W-E3-18TR-ND | 1 | 0.100 € | 0.10 € | Freilaufdiode Turofner, SOD-123W; Footprint prufen gegen Schaltplan-Symbol
R_GATE1 | Widerstand | 100Ω ±1% 0,1W | 0603 | Yageo | RC0603FR-07100RL | Digikey | 311-100HRCT-ND | 0 | 0.020 € | 0.00 € | Gate-Vorwiderstand Q2, 10er Gebinde; gleicher Typ R_RXD
R_GATE_PD1 | Widerstand | 100kΩ ±1% 0,1W | 0603 | Yageo | RC0603FR-07100KL | Digikey | 311-100KHRCT-ND | 0 | 0.020 € | 0.00 € | Gate Pull-down Q2, gleicher Typ Rfbt; 10er Gebinde
J_DOOR | WAGO Steckklemme | 2-polig 1,5mm² 3,5mm | SMD | WAGO | 2086-1202 | WAGO | 2086-1202 | 1 | 0.000 € | 0.00 € | Push-in Klemme Türöffner, DNP, vorhanden
 |  |  |  |  |  |  |  |  |  | 0.65 €
BLOCK 6 – STECKVERBINDER / KLEMMEN
J_PWR | WAGO Steckklemme | 2-polig 1,5mm² 3,5mm | SMD | WAGO | 2086-1202 | WAGO | 2086-1202 | 1 | 0.000 € | 0.00 € | 12V Eingang, gleicher Typ J_DOOR
 |  |  |  |  |  |  |  |  |  | 0.00 €
BLOCK 7 – STROMVERSORGUNG INNENEINHEIT (USB-C 5V → 3,3V)
R_CC1_INN | Widerstand | 5,1kΩ ±1% 0,1W | 0603 | Yageo | RC0603FR-075K1L | Digikey | YAG2320CT-ND | 2 | 0.020 € | 0.04 € | USB-C CC1 Pull-down 5,1kΩ gegen GND; 2× Inneneinheit; identisch R_CC2_INN; RC0603FR-075K1L verifiziert
R_CC2_INN | Widerstand | 5,1kΩ ±1% 0,1W | 0603 | Yageo | RC0603FR-075K1L | Digikey | YAG2320CT-ND | 2 | 0.020 € | 0.04 € | USB-C CC2 Pull-down 5,1kΩ gegen GND; 2× Inneneinheit; identisch R_CC1_INN; RC0603FR-075K1L verifiziert
U_INN | Step-Down Regler | TLV62568DBVR | SOT23-5 | Texas Instruments | TLV62568DBVR | Digikey | 296-47359-1-ND | 2 | 0.166 € | 0.33 € | TLV62568DBVR 5V→3,3V 1A SOT23-5; DK-Nr. 296-47359-1-ND verifiziert
Cin_INN | Keramikkondensator | 4,7µF 10V X7R | 0603 | Murata | GRM188Z71A475KE15D | Digikey | 490-GRM188Z71A475KE15DCT | 10 | 0.040 € | 0.40 € | Eingang, 10er Gebinde
Cout_INN | Keramikkondensator | 10µF 25V X7R | 0805 | Murata | GRM21BZ71E106KE15L | Digikey | 490-GRM21BZ71E106KE15LCT | 10 | 0.060 € | 0.60 € | Ausgang; gleicher Typ wie Cin Außeneinheit, Gebinde erhöhen
L1_INN | Speicherspule | 2,2µH 45mΩ 2,8A Isat | 4,0×4,0×1,8mm | Cyntec | SDER041H-2R2MS | Digikey | 2037-SDER041H-2R2MSCT-ND | 2 | 0.156 € | 0.31 € | Cyntec SDER041H-2R2MS 2,2µH 3,1A; DK-Nr. 2037-SDER041H-2R2MSCT-ND verifiziert; Footprint 4,0x4,0x1,8mm
R1_INN | Widerstand | 470kΩ ±1% 0,1W | 0603 | Yageo | RC0603FR-07470KL | Digikey | 311-470KHRCT-ND | 10 | 0.020 € | 0.20 € | Spannungsteiler oben TLV62568; VOUT=3,42V; 10er Gebinde
R2_INN | Widerstand | 100kΩ ±1% 0,1W | 0603 | Yageo | RC0603FR-07100KL | Digikey | 311-100KHRCT-ND | 0 | 0.020 € | 0.00 € | Spannungsteiler unten TLV62568; gleicher Typ Rfbt/R1_INN, Gebinde reicht
 |  |  |  |  |  |  |  |  |  | 1.92 €
BLOCK 8 – ESP32 BESCHALTUNG INNENEINHEIT (2× identisch)
U2_INN | WiFi/BT Modul | ESP32-WROOM-32E-N8 | SMD 38-Pin | Espressif | ESP32-WROOM-32E-N8 | Digikey | 5407-ESP32-WROOM-32E-N8TR-ND | 2 | 4.610 € | 9.22 € | 2× Inneneinheit; N8 (8MB Flash) gewählt – N4 Preisdiff. <0,50€
C_bulk_INN | Elektrolytkondensator | 100µF 6,3V SMD | Ø6,3×5,4mm | Panasonic | EEEFC0J101P | Mouser | 667-EEE-FC0J101P | 2 | 0.320 € | 0.64 € | Bulk-Puffer ESP32 WiFi-Peaks; 2× Inneneinheit
S_RST_INN | Taster SMD | 160gf 1,5mm Hub 12V | 5,2×5,2mm | C&K | PTS526 SK15 SMTR2 LFS | Digikey | CKN12221-2-ND | 2 | 0.122 € | 0.24 € | Reset; 2× Inneneinheit
S_BOOT_INN | Taster SMD | 160gf 1,5mm Hub 12V | 5,2×5,2mm | C&K | PTS526 SK15 SMTR2 LFS | Digikey | CKN12221-2-ND | 2 | 0.122 € | 0.24 € | Boot-Modus; gleicher Typ S_RST; 2× Inneneinheit
J_UART_INN | Pin-Header liegend | 4-Pin 2,54mm 90° | THT | Würth Elektronik | 61300411021 | Digikey | 732-5337-ND | 2 | 0.000 € | 0.00 € | UART Programmierschnittstelle; gleicher Typ J_UART Außeneinheit; ✓ BESCHAFFT – vorhanden
R_EN_INN | Widerstand | 10kΩ ±1% 0,1W | 0603 | Yageo | RC0603FR-0710KL | Digikey | 311-10KHRCT-ND | 0 | 0.020 € | 0.00 € | Pull-up Enable; gleicher Typ R_EN, Gebinde reicht
R_BOOT_INN | Widerstand | 10kΩ ±1% 0,1W | 0603 | Yageo | RC0603FR-0710KL | Digikey | 311-10KHRCT-ND | 0 | 0.020 € | 0.00 € | Pull-up GPIO0; gleicher Typ, Gebinde reicht
R_GPIO2_INN | Widerstand | 10kΩ ±1% 0,1W | 0603 | Yageo | RC0603FR-0710KL | Digikey | 311-10KHRCT-ND | 0 | 0.020 € | 0.00 € | Pull-down GPIO2; gleicher Typ, Gebinde reicht
R_RXD_INN | Widerstand | 100Ω ±1% 0,1W | 0603 | Yageo | RC0603FR-07100RL | Digikey | 311-100HRCT-ND | 0 | 0.020 € | 0.00 € | Schutzwiderstand RXD0; gleicher Typ R_RXD, Gebinde reicht
C_hf_INN | Keramikkondensator | 100nF 16V X7R | 0603 | Murata | GCM188R71C104KA37D | Digikey | 490-GCM188R71C104KA37DCT | 0 | 0.020 € | 0.00 € | HF-Bypass ESP32; gleicher Typ Coutx, Gebinde reicht
C_EN_INN | Keramikkondensator | 100nF 16V X7R | 0603 | Murata | GCM188R71C104KA37D | Digikey | 490-GCM188R71C104KA37DCT | 0 | 0.020 € | 0.00 € | Entprellung Reset; gleicher Typ, Gebinde reicht
 |  |  |  |  |  |  |  |  |  | 10.35 €
BLOCK 9 – KAPAZITIVER TOUCH-TASTER INNENEINHEIT (2× identisch)
R_TOUCH_INN | Widerstand | 1kΩ ±1% 0,1W | 0603 | Yageo | RC0603FR-071KL | Digikey | 311-1KHRCT-ND | 0 | 0.020 € | 0.00 € | ESD-Schutz Touch; gleicher Typ R_TOUCH1, Gebinde reicht
J_TOUCH_INN | Lotpad | – | – | – | – | – | – | 0 | 0.000 € | 0.00 € | Kein Stecker – Lotpad auf Platine (1-polig, 2x Inneneinheit)
 |  |  |  |  |  |  |  |  |  | 0.00 €
BLOCK 10 – SD-KARTE + CLASS-D + LAUTSPRECHER INNENEINHEIT (2× identisch)
J_SD_INN | MicroSD Halter | Push-Push SMD | SMD | Molex | 475710001 | Digikey | WM9731TR-ND | 2 | 0.880 € | 1.76 € | Molex MicroSD Push-Push SMD; Hersteller-Nr. 475710001; DK-Nr. verifiziert; 2x Inneneinheit
U3_INN | Class-D Verstärker | MAX98357AETE+T | TSSOP-16 | Analog Devices | MAX98357AETE+T | Digikey | MAX98357AETE+TCT-ND | 2 | 2.800 € | 5.60 € | 2× Inneneinheit; gleicher Typ U3
Lautsprecher1_INN | Lautsprecher | 51x51mm 8Ohm 2W quadr. Korb | 51x51mm quadratisch | Visaton | K 50 SQ | Digikey | 2056-K50SQ-8OHM-ND | 2 | 6.959 € | 13.92 € | Visaton K 50 SQ Art. 2897; 8Ohm 2W; Schallwandoeffnung 45mm; Korb 51x51mm; Montageloecher M4 auf 40x40mm Raster; Anschluss 2,8x0,5mm Flachstecker -> Draht angeloetet; 2x Inneneinheit; DK-Nr. 2056-K50SQ-8OHM-ND verifiziert
J_SPK_INN | WAGO Steckklemme | 2-polig 1,5mm² 3,5mm | SMD | WAGO | 2086-1202 | WAGO | 2086-1202 | 2 | 0.000 € | 0.00 € | Lautsprecher Anschluss; gleicher Typ J_TOUCH; 2× Inneneinheit
Montagebolzen_INN | Abstandsbolzen M4 | M4, Laenge TBD, Metall | THT | Firma (vorhanden) | - | vorhanden | - | 8 | 0.000 € | 0.00 € | Lautsprecher K 50 SQ auf PCB; Montageraster 40x40mm; 4x pro Inneneinheit = 8 gesamt; Laenge abhaengig von Gehaeuse (TBD); F10 offen
R_SD1_INN | entfallt | – | 0603 | – | – | – | – | 0 | 0.000 € | 0.00 € | Nicht im Schaltplan – SPI-Widerstande entfallen
R_SDMODE_INN | entfallt | – | 0603 | – | – | – | – | 0 | 0.000 € | 0.00 € | Nicht im Schaltplan – SD_MODE direkt an +3V3
C_SD_INN | Keramikkondensator | 100nF 16V X7R | 0603 | Murata | GCM188R71C104KA37D | Digikey | 490-GCM188R71C104KA37DCT | 0 | 0.020 € | 0.00 € | VDD Bypass SD; gleicher Typ Coutx, Gebinde reicht
C_AMP1_INN | Keramikkondensator | 10µF 25V X7R | 0805 | Murata | GRM21BZ71E106KE15L | Digikey | 490-GRM21BZ71E106KE15LCT | 0 | 0.060 € | 0.00 € | VDD Bulk AMP 10µF, gleicher Typ Cout_INN (laut MAX98357A DB)
C_AMP2_INN | Keramikkondensator | 100nF 16V X7R | 0603 | Murata | GCM188R71C104KA37D | Digikey | 490-GCM188R71C104KA37DCT | 0 | 0.020 € | 0.00 € | VDD HF AMP; gleicher Typ Coutx, Gebinde reicht
 |  |  |  |  |  |  |  |  |  | 21.28 €
GESAMTKOSTEN AUSSENEINHEIT |  |  |  |  |  |  |  |  |  | 27.04 €
GESAMTKOSTEN INNENEINHEIT (2× Stk., inkl. Lot-Reserve) |  |  |  |  |  |  |  |  |  | 33.55 €
GESAMTKOSTEN PROJEKT |  |  |  |  |  |  |  |  |  | 60.59 €

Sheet: Digikey Upload
Quantity | Digi-Key Part Number | Customer Reference
1 | 732-74438356018HTTR-ND | L1 – 1,8µH 26mΩ 6,05A | TRUE
1 | DMG2305UX-7DICT-ND | Q1 – 20V 4,2A 40mΩ | TRUE
1 | 1727-5040-2-ND | DZ1 – 7,5V 250mW | TRUE
1 | SMBJ15A-E3/52GITR-ND | D1 – 15V unidirektional | TRUE
10 | 311-100KHRCT-ND | Rfbt – 100kΩ ±1% 0,1W | TRUE
10 | 311-43.2KHRCT-ND | Rfbb – 43,2kΩ ±1% 0,1W | TRUE
10 | 490-GRM21BZ71E106KE15LCT | Cin – 10µF 25V X7R, Cout_INN – 10µF 25V X7R | TRUE
10 | 490-3290-2-ND | Cinx – 220nF 25V X7R | TRUE
10 | 490-GRM21BZ71A226ME15LCT | Cout1 – 22µF 10V X7R | TRUE
10 | 490-4774-2-ND | Coutx – 100nF 16V X7R | TRUE
10 | 732-7994-2-ND | Cvcc – 1µF 25V X7R | TRUE
3 | 5407-ESP32-WROOM-32E-N8TR-ND | U2 – ESP32-WROOM-32E-N8, U2_INN – ESP32-WROOM-32E-N8 | TRUE
10 | 311-10.0KHRTR-ND | R_EN – 10kΩ ±1% 0,1W | TRUE
10 | CKN12221-2-ND | S_RST – 160gf 1,5mm Hub 12V, S_RST_INN – 160gf 1,5mm Hub 12V, S_BOOT_INN – 160gf 1,5mm Hub 12V | TRUE
10 | 311-100HRCT-ND | R_RXD – 100Ω ±1% 0,1W | TRUE
10 | 311-1.00KHRTR-ND | R_TOUCH1 – 1kΩ ±1% 0,1W | TRUE
1 | WM9731TR-ND | J_SD – Push-Push SMD | TRUE
3 | MAX98357AETE+TCT-ND | U3 – MAX98357AETE+T, U3_INN – MAX98357AETE+T | TRUE
1 | 2056-K36WP-8OHM-ND | Lautsprecher1 – 36mm 8Ohm 1W WP | TRUE
1 | 1N4148W-E3-18TR-ND | D_FLY1 – 100V 300mA | TRUE
4 | 311-5.10KHRTR-ND | R_CC1_INN – 5,1kΩ ±1% 0,1W | TRUE
2 | 296-47359-1-ND | U_INN – TLV62568DBVR | TRUE
10 | 490-GRM188Z71A475KE15DCT | Cin_INN – 4,7µF 10V X7R | TRUE
2 | 2037-SDER041H-2R2MSCT-ND | L1_INN – 2,2µH 45mΩ 2,8A Isat | TRUE
10 | YAG3609TR-ND | R1_INN – 470kΩ ±1% 0,1W | TRUE
2 | WM9731TR-ND | J_SD_INN – Push-Push SMD | TRUE
2 | 2056-K50SQ-8OHM-ND | Lautsprecher1_INN – 51x51mm 8Ohm 2W quadr. Korb | TRUE

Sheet: Mouser Upload
Quantity | Mouser Part Number | Customer Reference
1 | 595-LMR33630CDDAR | U1 – LMR33630CDDAR
1 | 667-EEE-FC0J101P | C_bulk – 100µF 6,3V SMD
1 | 942-IRLML6344TRPBF | Q2 – 30V 5A Logic-Level
2 | 667-EEE-FC0J101P | C_bulk_INN – 100µF 6,3V SMD
10 | 490-GCM188R71C104KA37D | Coutx – 100nF 16V X7R

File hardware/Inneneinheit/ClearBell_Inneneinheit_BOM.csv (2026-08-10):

Reference | Qty | Value | DNP | Exclude from BOM | Exclude from Board | Footprint | Datasheet | Beschreibung
C_Bulk1 | 1 | 100µ |  |  |  | Capacitor_SMD:C_Elec_6.3x5.4 |  | Unpolarized capacitor
C_EN1,C_HF1,C_HF2,C_SD1,C_VDD2 | 5 | 100n |  |  |  | Capacitor_SMD:C_0603_1608Metric_Pad1.08x0.95mm_HandSolder |  | Unpolarized capacitor
C_IN1 | 1 | 4,7µ |  |  |  | Capacitor_SMD:C_0603_1608Metric_Pad1.08x0.95mm_HandSolder |  | Unpolarized capacitor
C_OUT1,C_VDD1 | 2 | 10µ |  |  |  | Capacitor_SMD:C_0603_1608Metric_Pad1.08x0.95mm_HandSolder |  | Unpolarized capacitor
J1 | 1 | UJC-HP-3-SMT-TR |  |  |  | UJC-HP-3-SMT-TR:CUI_UJC-HP-3-SMT-TR |  | Type C, 20 Vdc, 3 A, Right Angle, Surface Mount, Black Insulator, Power-Only USB Receptacle
J2 | 1 | Conn_01x04 |  |  |  | Connector_PinSocket_2.54mm:PinSocket_1x04_P2.54mm_Horizontal |  | Generic connector, single row, 01x04, script generated (kicad-library-utils/schlib/autogen/connector/)
J3 | 1 | 475710001 |  |  |  | MOLEX MICRO SD CARD_475710001:MOLEX MICRO SD CARD_475710001 | https://www.molex.com/en-us/products/part-detail-pdf/475710001?display=pdf | microSD memory card connector, push-pull, 8 contacts + detect switch, 1.10mm pitch
J_SPK1 | 1 | Speaker1 |  |  |  | Wago_2086-1202:Wago_2086-1202 |  | Generic connector, single row, 01x02, script generated (kicad-library-utils/schlib/autogen/connector/)
J_TOUCH1 | 1 | Conn_01x01 |  |  |  | TestPoint:TestPoint_Pad_2.0x2.0mm |  | Generic connector, single row, 01x01, script generated (kicad-library-utils/schlib/autogen/connector/)
L1 | 1 | 2,2µ |  |  |  | Inductor_SMD_Wurth:L_Wurth_WE-MAPI-4020HT | ${KIPRJMOD}/Datenblätter/SDER041H-000 (B3).pdf | Shielded SMD power inductor 2.2uH +/-20%, Isat 3.1A, 45mOhm, 4.0x4.0x1.8mm
R_BOOT1,R_EN1,R_GPIO2 | 3 | 10k |  |  |  | Resistor_SMD:R_0603_1608Metric_Pad0.98x0.95mm_HandSolder |  | Resistor
R_CC1,R_CC2 | 2 | 5k1 |  |  |  | Resistor_SMD:R_0603_1608Metric_Pad0.98x0.95mm_HandSolder |  | Resistor
R_FBB1 | 1 | 100k |  |  |  | Resistor_SMD:R_0603_1608Metric_Pad0.98x0.95mm_HandSolder |  | Resistor
R_FBT1 | 1 | 470k |  |  |  | Resistor_SMD:R_0603_1608Metric_Pad0.98x0.95mm_HandSolder |  | Resistor
R_RXD1 | 1 | 100 |  |  |  | Resistor_SMD:R_0603_1608Metric_Pad0.98x0.95mm_HandSolder |  | Resistor
R_TOUCH1 | 1 | 1k |  |  |  | Resistor_SMD:R_0603_1608Metric_Pad0.98x0.95mm_HandSolder |  | Resistor
S_BOOT1,S_RST1 | 2 | SW_Push |  |  |  | CK_PTS526:CK_PTS526 | https://www.ckswitches.com/products/switches/product-details/Tactile/PTS526/ | Tactile switch SPST-NO 0.05A 12V, 5.2x5.2mm SMD
U1 | 1 | TLV62568DBVR |  |  |  | TLV62568DBVR:SOT95P280X145-5N | kicad-embed://tlv62568.pdf | 2.5V-5.5V input, 1A high efficiency step-down buck converter in SOT23 and SOT563 package
U2 | 1 | ESP32-WROOM-32E-N8 |  |  |  | ESP32-WROOM-32E-N4:ESP32WROOM32EN8 | https://www.espressif.com/sites/default/files/documentation/esp32-wroom-32e_esp32-wroom-32ue_datasheet_en.pdf | Bluetooth, WiFi 802.11b/g/n, Bluetooth v4.2 +EDR, Class 1, 2 and 3 Transceiver Module 2.4GHz ~ 2.5GHz PCB Trace Surface Mount
U3 | 1 | MAX98357AETE_T |  |  |  | MAX98357AETE_T:QFN50P300X300X80-17N | https://www.analog.com/media/en/technical-documentation/data-sheets/MAX98357A-MAX98357B.pdf | Tiny, Low-Cost, PCM Class D Amplifier with Class AB Performance

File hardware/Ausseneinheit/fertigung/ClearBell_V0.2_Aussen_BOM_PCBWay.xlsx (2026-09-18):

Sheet: BOM
Pos | Designator | Menge / Qty | Wert / Value | Beschreibung / Description | Gehaeuse / Package | KiCad-Footprint | Hersteller / Manufacturer | Hersteller-Teilenummer / MPN | Bestuecken / Populate | Ersatz zulaessig / Substitute allowed | Lieferant / Supplier | Lieferant-Teilenummer / Supplier P/N | Bemerkung / Notes
1 | C_Bulk1 | 1 | 100u | Elektrolytkondensator, 100 µF / 6,3 V | Elko 6,3 x 5,4 mm | Capacitor_SMD:CP_Elec_6.3x5.4 | Panasonic | EEEFC0J101P | ja / yes | NEIN / NO substitute | Mouser | 667-EEE-FC0J101P
2 | C_EN1, Cvcc1 | 2 | 1u | Keramikkondensator, 1 µF / 25 V / X7R | 0603 | Capacitor_SMD:C_0603_1608Metric | Würth Elektronik | 885012206076 | ja / yes | ja, gleiche Daten / yes, identical specs only | Digikey | 732-7994-2-ND
3 | C_ESD_USB1, C_HF1, C_MIC1, C_VDD_AMP2, Cboot1, CoutX1 | 6 | 100n | Keramikkondensator, 100 nF / 16 V / X7R | 0603 | Capacitor_SMD:C_0603_1608Metric | Murata | GCM188R71C104KA37D | ja / yes | NEIN / NO substitute | Digikey | 490-GCM188R71C104KA37DCT
4 | C_MOD1, Cout1, Cout2 | 3 | 22u | Keramikkondensator, 22 µF / 10 V / X7R | 0805 | Capacitor_SMD:C_0805_2012Metric | Murata | GRM21BZ71A226ME15L | ja / yes | NEIN / NO substitute | Digikey | 490-GRM21BZ71A226ME15LCT
5 | C_VDD_AMP1, Cin1, Cin2, Cin3, Cin4 | 5 | 10u | Keramikkondensator, 10 µF / 25 V / X7R | 0805 | Capacitor_SMD:C_0805_2012Metric | Murata | GRM21BZ71E106KE15L | ja / yes | NEIN / NO substitute | Digikey | 490-GRM21BZ71E106KE15LCT
6 | Cff1 | 1 | DNP | nicht bestückt (DNP) | 0603 | Capacitor_SMD:C_0603_1608Metric |  |  | nein / NO (DNP) | - |  |  | NICHT BESTUECKEN / DO NOT PLACE (DNP) - Footprint bleibt frei
7 | CinX1 | 1 | 220n | Keramikkondensator, 220 nF / 25 V / X7R | 0603 | Capacitor_SMD:C_0603_1608Metric | Murata | GRM188R71E224KA88D | ja / yes | NEIN / NO substitute | Digikey | 490-3290-2-ND
8 | D1 | 1 | SMBJ15A | TVS-Diode, 15 V unidirektional | SMB (DO-214AA) | Diode_SMD:D_SMB | Vishay | SMBJ15A-E3/52 | ja / yes | NEIN / NO substitute | Digikey | SMBJ15A-E3/52GITR-ND
9 | DZ1 | 1 | BZX84-C6V2 | Zener-Diode VGS-Clamp, 6,2 V / 250 mW | SOT-23 | Package_TO_SOT_SMD:SOT-23 | Nexperia | BZX84-C6V2,215 | ja / yes | NEIN / NO substitute | Digikey | 1727-2941-1-ND
10 | D_ESD_TCH1, D_ESD_TCH2 | 2 | ESD9L5.0ST5G | ESD-Schutzdiode, sehr niederkapazitiv, 0,5 pF typ. / 0,9 pF max. | SOD-923 | Diode_SMD:D_SOD-923 | onsemi | ESD9L5.0ST5G | ja / yes | NEIN / NO substitute
11 | D_ESD_USB1 | 1 | USBLC6-4SC6 | ESD-Schutzarray, 4-kanalig, 4 Leitungen, 3 pF typ., VBUS-Schutz integriert | SOT-23-6 | Package_TO_SOT_SMD:SOT-23-6 | STMicroelectronics | USBLC6-4SC6 | ja / yes | NEIN / NO substitute | Digikey | 497-4492-1-ND
12 | D_FLY1 | 1 | S1A | Freilaufdiode (Gleichrichter), ≥ 50 V / 1 A | SMA (DO-214AC) | Diode_SMD:D_SMA | Taiwan Semiconductor (oder gleichwertig / or equivalent) | S1A | ja / yes | ja, jeder S1A / yes, any S1A |  |  | Mehrquellentyp / multi-source: jeder S1A im SMA/DO-214AC (>= 50 V / 1 A) ist zulaessig.
13 | D_ORING1 | 1 | PMEG3010ER | Schottky-Diode ORing Service-USB, 30 V / 1 A · VF 320 mV typ @ 1 A | SOD-123W (CFP3) | Diode_SMD:Nexperia_CFP3_SOD-123W | Nexperia | PMEG3010ER | ja / yes | NEIN / NO substitute
14 | F1 | 1 | 1812L150/24MR | Rückstellende Sicherung (PPTC), 1,5 A hold / 3,0 A trip / 24 V | 1812 | ClearBell:Fuse_1812_4532Metric | Littelfuse | 1812L150/24MR | ja / yes | NEIN / NO substitute | Digikey | F3487CT-ND
15 | J_DOOR1, J_PWR1 | 2 | 2060-452/998-404 | Leiterplattenklemme, 2-polig, 0,75 mm² · RM 4 mm · Push-in | Klemme SMD, RM 4 mm | ClearBell:WAGO_2060-452_998-404 | WAGO | 2060-452/998-404 | ja / yes | NEIN / NO substitute | WAGO | 2060-452/998-404
16 | J_USB_SVC1 | 1 | USB4105-GF-A-120 | USB-C-Buchse, Service, USB 2.0, 24-Pos., 16 Signal | USB-C SMD + THT-Anker | Connector_USB:USB_C_Receptacle_GCT_USB4105-xx-A_16P_TopMnt_Horizontal | GCT | USB4105-GF-A-120 | ja / yes | NEIN / NO substitute | Digikey | 2073-USB4105-GF-A-120DKR-ND
17 | L1 | 1 | 1.8u | Speicherspule, 1,8 µH / 26 mΩ / 6,05 A | 4 x 4 mm SMD | ClearBell:L_Wurth_WE-MAPI-4020HT | Würth Elektronik | 74438356018HT | ja / yes | NEIN / NO substitute | Digikey | 732-74438356018HTTR-ND
18 | LED1 | 1 | APHBM2012LSURKCGKC | Status-LED, zweifarbig, rot 630 nm + gruen 570 nm, beide AlGaInP, klare Linse, 4-polig (2 getrennte Chips, gemeinsame Kathoden erst auf der Platine) | 2,0 x 1,25 mm | LED_SMD:LED_Kingbright_APHBM2012_2x1.25mm | Kingbright | APHBM2012LSURKCGKC | ja / yes | NEIN / NO substitute
19 | Q1 | 1 | PJA3415AE-AU | P-Kanal-MOSFET Verpolschutz, 20 V / 4,3 A, ESD-geschützt | SOT-23 | Package_TO_SOT_SMD:SOT-23 | Panjit | PJA3415AE-AU | ja / yes | NEIN / NO substitute |  |  | ESD-geschuetzte Variante, Bestellcode PJA3415AE-AU_R1_000A1 - NICHT durch PJA3415A ersetzen / do NOT replace by PJA3415A.
20 | Q2 | 1 | IRLML6344TRPBF | N-Kanal-MOSFET, 30 V / 5 A, Logic-Level | SOT-23 | Package_TO_SOT_SMD:SOT-23 | Infineon | IRLML6344TRPBF | ja / yes | NEIN / NO substitute | Mouser | 942-IRLML6344TRPBF
21 | R_BOOT1, R_EN1 | 2 | 10k | Widerstand, 10 kΩ ±1 % 0,1 W | 0603 | Resistor_SMD:R_0603_1608Metric | Yageo | RC0603FR-0710KL | ja / yes | ja, gleiche Daten / yes, identical specs only | Digikey | 311-10.0KHRTR-ND
22 | R_CC1, R_CC2 | 2 | 5k1 | Widerstand, 5,1 kΩ ±1 % 0,1 W | 0603 | Resistor_SMD:R_0603_1608Metric | Yageo | RC0603FR-075K1L | ja / yes | ja, gleiche Daten / yes, identical specs only | Digikey | 311-5.10KHRTR-ND
23 | R_GATE1, R_MIC_DATA1 | 2 | 100 | Widerstand, 100 Ω ±1 % 0,1 W | 0603 | Resistor_SMD:R_0603_1608Metric | Yageo | RC0603FR-07100RL | ja / yes | ja, gleiche Daten / yes, identical specs only | Digikey | 311-100HRCT-ND
24 | R_GATE_PD1, R_SDMODE1, Rfbt1, Rg1, Rpg1 | 5 | 100k | Widerstand, 100 kΩ ±1 % 0,1 W | 0603 | Resistor_SMD:R_0603_1608Metric | Yageo | RC0603FR-07100KL | ja / yes | ja, gleiche Daten / yes, identical specs only | Digikey | 311-100KHRCT-ND
25 | R_LED_G1, R_LED_R1 | 2 | 750R | Widerstand, 750 Ω ±1 % 0,1 W | 0603 | Resistor_SMD:R_0603_1608Metric | Yageo | RC0603FR-07750RL | ja / yes | ja, gleiche Daten / yes, identical specs only
26 | R_TOUCH_EG1, R_TOUCH_OG1, R_VBUS_PD1 | 3 | 1k | Widerstand, 1 kΩ ±1 % 0,1 W | 0603 | Resistor_SMD:R_0603_1608Metric | Yageo | RC0603FR-071KL | ja / yes | ja, gleiche Daten / yes, identical specs only | Digikey | 311-1.00KHRTR-ND
27 | Rfbb1 | 1 | 43k2 | Widerstand, 43,2 kΩ ±1 % 0,1 W | 0603 | Resistor_SMD:R_0603_1608Metric | Yageo | RC0603FR-0743K2L | ja / yes | ja, gleiche Daten / yes, identical specs only | Digikey | 311-43.2KHRCT-ND
28 | S_BOOT1, S_RST1 | 2 | EVP-BD6C1A000 | Taster SMD, 2-polig, 6×6×4 mm / 3,5 N / 0,75 mm Hub | Taster 6 x 6 mm SMD | ClearBell:EVP-BD6C1A000 | Panasonic | EVP-BD6C1A000 | ja / yes | NEIN / NO substitute | Digikey | P19748CT-ND
29 | U1 | 1 | LMR33630CDDAR | Step-Down-Regler, LMR33630CDDAR | HSOIC-8 PowerPAD (DDA) | ClearBell:DDA0008J | Texas Instruments | LMR33630CDDAR | ja / yes | NEIN / NO substitute | Mouser | 595-LMR33630CDDAR
30 | U2 | 1 | ESP32-S3-WROOM-1-N16R8 | WiFi/BT-Modul, ESP32-S3-WROOM-1-N16R8 | Modul 18 x 25,5 mm, 41 Pads | RF_Module:ESP32-S3-WROOM-1 | Espressif | ESP32-S3-WROOM-1-N16R8 | ja / yes | NEIN / NO substitute | Digikey | 1965-ESP32-S3-WROOM-1-N16R8CT-ND
31 | U3 | 1 | MAX98357AETE+T | Class-D-Verstärker, MAX98357AETE+T | QFN-16 3 x 3 mm | ClearBell:QFN50P300X300X80-17N | Analog Devices | MAX98357AETE+T | ja / yes | NEIN / NO substitute | Digikey | MAX98357AETE+TCT-ND
32 | U4 | 1 | IM72D128V01 | MEMS-Mikrofon, digital PDM, 1,62–3,6 V · 72 dB(A) · 128 dBSPL AOP · IP57 | LLGA-5 4 x 3 mm | ClearBell:IFX-PG-LLGA-5-4 | Infineon | IM72D128V01 | ja / yes | NEIN / NO substitute | Digikey | IM72D128V01XTMA1

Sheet: Hinweise
ClearBell V0.2 — Ausseneinheit
Stand | 2026-09-18 | Platine MD5 | 9dd0709b | Quelle | ClearBell_BOM_v20.xlsx
Auf der Platine, aber KEIN Bauteil (nicht bestuecken, nur Kupfer) / copper only, no part:
 | J_SPK1 | Loetpads fuer die Lautsprecherleitung — kein Bauteil
 | J_TOUCH_EG1 | Loetpad fuer die Bronzeelektrode EG — kein Bauteil
 | J_TOUCH_OG1 | Loetpad fuer die Bronzeelektrode OG — kein Bauteil
 | 28 Testpunkte TP_* | blanke Pruefpads, kein Bauteil / bare test pads
Als DNP markiert (Footprint bleibt unbestueckt) / do not place:
 | Cff1 | nicht bestückt (DNP)
Gehoert zum Geraet, wird NICHT auf die Platine bestueckt / not part of the PCBA:
 | LS1 | Visaton K 50 FL (8 Ohm) — Lautsprecher, wird an J_SPK1 angeloetet
Ersatz zulaessig / Substitutes (Spalte K):
 | NEIN / NO | Modul, Mikrofon, Regler-ICs, alle Murata-Kondensatoren (DC-Bias gerechnet), alle uebrigen aktiven Bauteile, Dioden, Spulen, Sicherung, Stecker, Taster, LED, Elko
 | ja, gleiche Daten | nur Widerstaende und die Wuerth-/YAGEO-Kondensatoren: gleicher Wert, Toleranz, Dielektrikum, Spannung, Baugroesse / identical value, tolerance, dielectric, voltage, size
 | ja, jeder S1A | D_FLY1 ist ausdruecklich Mehrquellentyp / multi-source
Die Bestueckungsdaten (…-top-pos.csv) enthalten genau die Positionen mit „Bestuecken = ja".
Alle Bauteile liegen auf der Oberseite (F.Cu); die Rueckseite bleibt frei / top side only.

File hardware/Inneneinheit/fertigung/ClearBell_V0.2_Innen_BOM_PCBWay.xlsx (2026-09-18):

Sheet: BOM
Pos | Designator | Menge / Qty | Wert / Value | Beschreibung / Description | Gehaeuse / Package | KiCad-Footprint | Hersteller / Manufacturer | Hersteller-Teilenummer / MPN | Bestuecken / Populate | Ersatz zulaessig / Substitute allowed | Lieferant / Supplier | Lieferant-Teilenummer / Supplier P/N | Bemerkung / Notes
1 | C_EN1 | 1 | 1u | Keramikkondensator, 1 µF / 25 V / X7R | 0603 | Capacitor_SMD:C_0603_1608Metric | Würth Elektronik | 885012206076 | ja / yes | ja, gleiche Daten / yes, identical specs only | Digikey | 732-7994-2-ND
2 | C_ESD_USB1, C_HF1, C_HF2, C_MIC1, C_VDD_AMP2 | 5 | 100n | Keramikkondensator, 100 nF / 16 V / X7R | 0603 | Capacitor_SMD:C_0603_1608Metric | Murata | GCM188R71C104KA37D | ja / yes | NEIN / NO substitute | Digikey | 490-GCM188R71C104KA37DCT
3 | C_FF1 | 1 | 15p | Keramikkondensator, 15 pF / 50 V / C0G | 0603 | Capacitor_SMD:C_0603_1608Metric | YAGEO | CC0603JRNPO9BN150 | ja / yes | ja, gleiche Daten / yes, identical specs only |  |  | Alternative / alternate (NRND): Murata GRM1885C1H150JA01D oder GCM1885C1H150JA16D, datengleich (15 pF +/-5 % C0G 50 V 0603).
4 | C_IN1, C_OUT1, C_VDD_AMP1 | 3 | 10u | Keramikkondensator, 10 µF / 25 V / X7R | 0805 | Capacitor_SMD:C_0805_2012Metric | Murata | GRM21BZ71E106KE15L | ja / yes | NEIN / NO substitute | Digikey | 490-GRM21BZ71E106KE15LCT
5 | C_MOD1 | 1 | 22u | Keramikkondensator, 22 µF / 10 V / X7R | 0805 | Capacitor_SMD:C_0805_2012Metric | Murata | GRM21BZ71A226ME15L | ja / yes | NEIN / NO substitute | Digikey | 490-GRM21BZ71A226ME15LCT
6 | D_ESD_TCH1 | 1 | ESD9L5.0ST5G | ESD-Schutzdiode, 0,5 pF typ. | SOD-923 | Diode_SMD:D_SOD-923 | onsemi | ESD9L5.0ST5G | ja / yes | NEIN / NO substitute
7 | D_ESD_USB1 | 1 | USBLC6-4SC6 | ESD-Schutzarray, 4-kanalig, 4 Leitungen, 3 pF typ. | SOT-23-6 | Package_TO_SOT_SMD:SOT-23-6 | STMicroelectronics | USBLC6-4SC6 | ja / yes | NEIN / NO substitute | Digikey | 497-4492-1-ND
8 | J_USB1 | 1 | USB4105-GF-A-120 | USB-C-Buchse MIT Datenpins, USB 2.0, 24-Pos., 16 Signal | USB-C SMD + THT-Anker | Connector_USB:USB_C_Receptacle_GCT_USB4105-xx-A_16P_TopMnt_Horizontal | GCT | USB4105-GF-A-120 | ja / yes | NEIN / NO substitute | Digikey | 2073-USB4105-GF-A-120DKR-ND
9 | L1 | 1 | 2.2u | Speicherspule, 2,2 µH / 45 mΩ / 3,1 A Isat | 4 x 4 x 1,8 mm | ClearBell:L_Cyntec_SDER041H_4.0x4.0x1.8mm | Cyntec | SDER041H-2R2MS | ja / yes | NEIN / NO substitute | Digikey | 2037-SDER041H-2R2MSCT-ND
10 | LED1 | 1 | APHBM2012LSURKCGKC | Status-LED, zweifarbig, rot 630 nm + grün 570 nm, beide AlGaInP, klare Linse, 4-polig | 2,0 x 1,25 mm | ClearBell:LED_Kingbright_APHBM2012_2x1.25mm | Kingbright | APHBM2012LSURKCGKC | ja / yes | NEIN / NO substitute
11 | R_BOOT1, R_EN1 | 2 | 10k | Widerstand, 10 kΩ ±1 % 0,1 W | 0603 | Resistor_SMD:R_0603_1608Metric | Yageo | RC0603FR-0710KL | ja / yes | ja, gleiche Daten / yes, identical specs only | Digikey | 311-10.0KHRTR-ND
12 | R_CC1, R_CC2 | 2 | 5k1 | Widerstand, 5,1 kΩ ±1 % 0,1 W | 0603 | Resistor_SMD:R_0603_1608Metric | Yageo | RC0603FR-075K1L | ja / yes | ja, gleiche Daten / yes, identical specs only | Digikey | 311-5.10KHRTR-ND
13 | R_FBB1 | 1 | 40k2 | Widerstand, 40,2 kΩ ±1 % 0,1 W | 0603 | Resistor_SMD:R_0603_1608Metric | Yageo | RC0603FR-0740K2L | ja / yes | ja, gleiche Daten / yes, identical specs only
14 | R_FBT1 | 1 | 180k | Widerstand, 180 kΩ ±1 % 0,1 W | 0603 | Resistor_SMD:R_0603_1608Metric | Yageo | RC0603FR-07180KL | ja / yes | ja, gleiche Daten / yes, identical specs only
15 | R_LED_G1, R_LED_R1 | 2 | 750R | Widerstand, 750 Ω ±1 % 0,1 W | 0603 | Resistor_SMD:R_0603_1608Metric | Yageo | RC0603FR-07750RL | ja / yes | ja, gleiche Daten / yes, identical specs only
16 | R_MIC_DATA1 | 1 | 100 | Widerstand, 100 Ω ±1 % 0,1 W | 0603 | Resistor_SMD:R_0603_1608Metric | Yageo | RC0603FR-07100RL | ja / yes | ja, gleiche Daten / yes, identical specs only
17 | R_SDMODE1 | 1 | 100k | Widerstand, 100 kΩ ±1 % 0,1 W | 0603 | Resistor_SMD:R_0603_1608Metric | Yageo | RC0603FR-07100KL | ja / yes | ja, gleiche Daten / yes, identical specs only | Digikey | 311-100KHRCT-ND
18 | R_TOUCH1 | 1 | 1k | Widerstand, 1 kΩ ±1 % 0,1 W | 0603 | Resistor_SMD:R_0603_1608Metric | Yageo | RC0603FR-071KL | ja / yes | ja, gleiche Daten / yes, identical specs only | Digikey | 311-1.00KHRTR-ND
19 | S_BOOT1, S_RST1 | 2 | EVP-BD6C1A000 | Taster SMD, 2-polig, 6×6×4 mm | Taster 6 x 6 mm SMD | ClearBell:EVP-BD6C1A000 | Panasonic | EVP-BD6C1A000 | ja / yes | NEIN / NO substitute | Digikey | P19748CT-ND
20 | U1 | 1 | TLV62568DBVR | Step-Down-Regler, TLV62568DBVR | SOT-23-5 | Package_TO_SOT_SMD:SOT-23-5 | Texas Instruments | TLV62568DBVR | ja / yes | NEIN / NO substitute | Digikey | 296-47359-1-ND
21 | U2 | 1 | ESP32-S3-WROOM-1-N16R8 | WiFi/BT-Modul, ESP32-S3-WROOM-1-N16R8 | Modul 18 x 25,5 mm, 41 Pads | RF_Module:ESP32-S3-WROOM-1 | Espressif | ESP32-S3-WROOM-1-N16R8 | ja / yes | NEIN / NO substitute | Digikey | 1965-ESP32-S3-WROOM-1-N16R8CT-ND
22 | U3 | 1 | MAX98357AETE+T | Class-D-Verstärker, MAX98357AETE+T | QFN-16 3 x 3 mm | ClearBell:QFN50P300X300X80-17N | Analog Devices | MAX98357AETE+T | ja / yes | NEIN / NO substitute | Digikey | MAX98357AETE+TCT-ND
23 | U4 | 1 | IM72D128V01 | MEMS-Mikrofon, digital PDM, 1,62–3,6 V · 72 dB(A) · IP57 | LLGA-5 4 x 3 mm | ClearBell:IFX-PG-LLGA-5-4 | Infineon | IM72D128V01 | ja / yes | NEIN / NO substitute | Digikey | IM72D128V01XTMA1

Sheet: Hinweise
ClearBell V0.2 — Inneneinheit
Stand | 2026-09-18 | Platine MD5 | db1dd009 | Quelle | ClearBell_BOM_v20.xlsx
Auf der Platine, aber KEIN Bauteil (nicht bestuecken, nur Kupfer) / copper only, no part:
 | J_SPK1 | Loetpads fuer die Lautsprecherleitung — kein Bauteil
 | J_TOUCH1 | Loetpad fuer die Bronzeelektrode — kein Bauteil
 | 21 Testpunkte TP_* | blanke Pruefpads, kein Bauteil / bare test pads
Als DNP markiert (Footprint bleibt unbestueckt) / do not place:
 | keine / none
Gehoert zum Geraet, wird NICHT auf die Platine bestueckt / not part of the PCBA:
 | LS1 | Visaton K 50 SQ (8 Ohm) — Lautsprecher, sitzt auf der Platine, wird an J_SPK1 angeloetet
Ersatz zulaessig / Substitutes (Spalte K):
 | NEIN / NO | Modul, Mikrofon, Regler-ICs, alle Murata-Kondensatoren (DC-Bias gerechnet), alle uebrigen aktiven Bauteile, Dioden, Spulen, Sicherung, Stecker, Taster, LED, Elko
 | ja, gleiche Daten | nur Widerstaende und die Wuerth-/YAGEO-Kondensatoren: gleicher Wert, Toleranz, Dielektrikum, Spannung, Baugroesse / identical value, tolerance, dielectric, voltage, size
 | ja, jeder S1A | D_FLY1 ist ausdruecklich Mehrquellentyp / multi-source
Die Bestueckungsdaten (…-top-pos.csv) enthalten genau die Positionen mit „Bestuecken = ja".
Alle Bauteile liegen auf der Oberseite (F.Cu); die Rueckseite bleibt frei / top side only.

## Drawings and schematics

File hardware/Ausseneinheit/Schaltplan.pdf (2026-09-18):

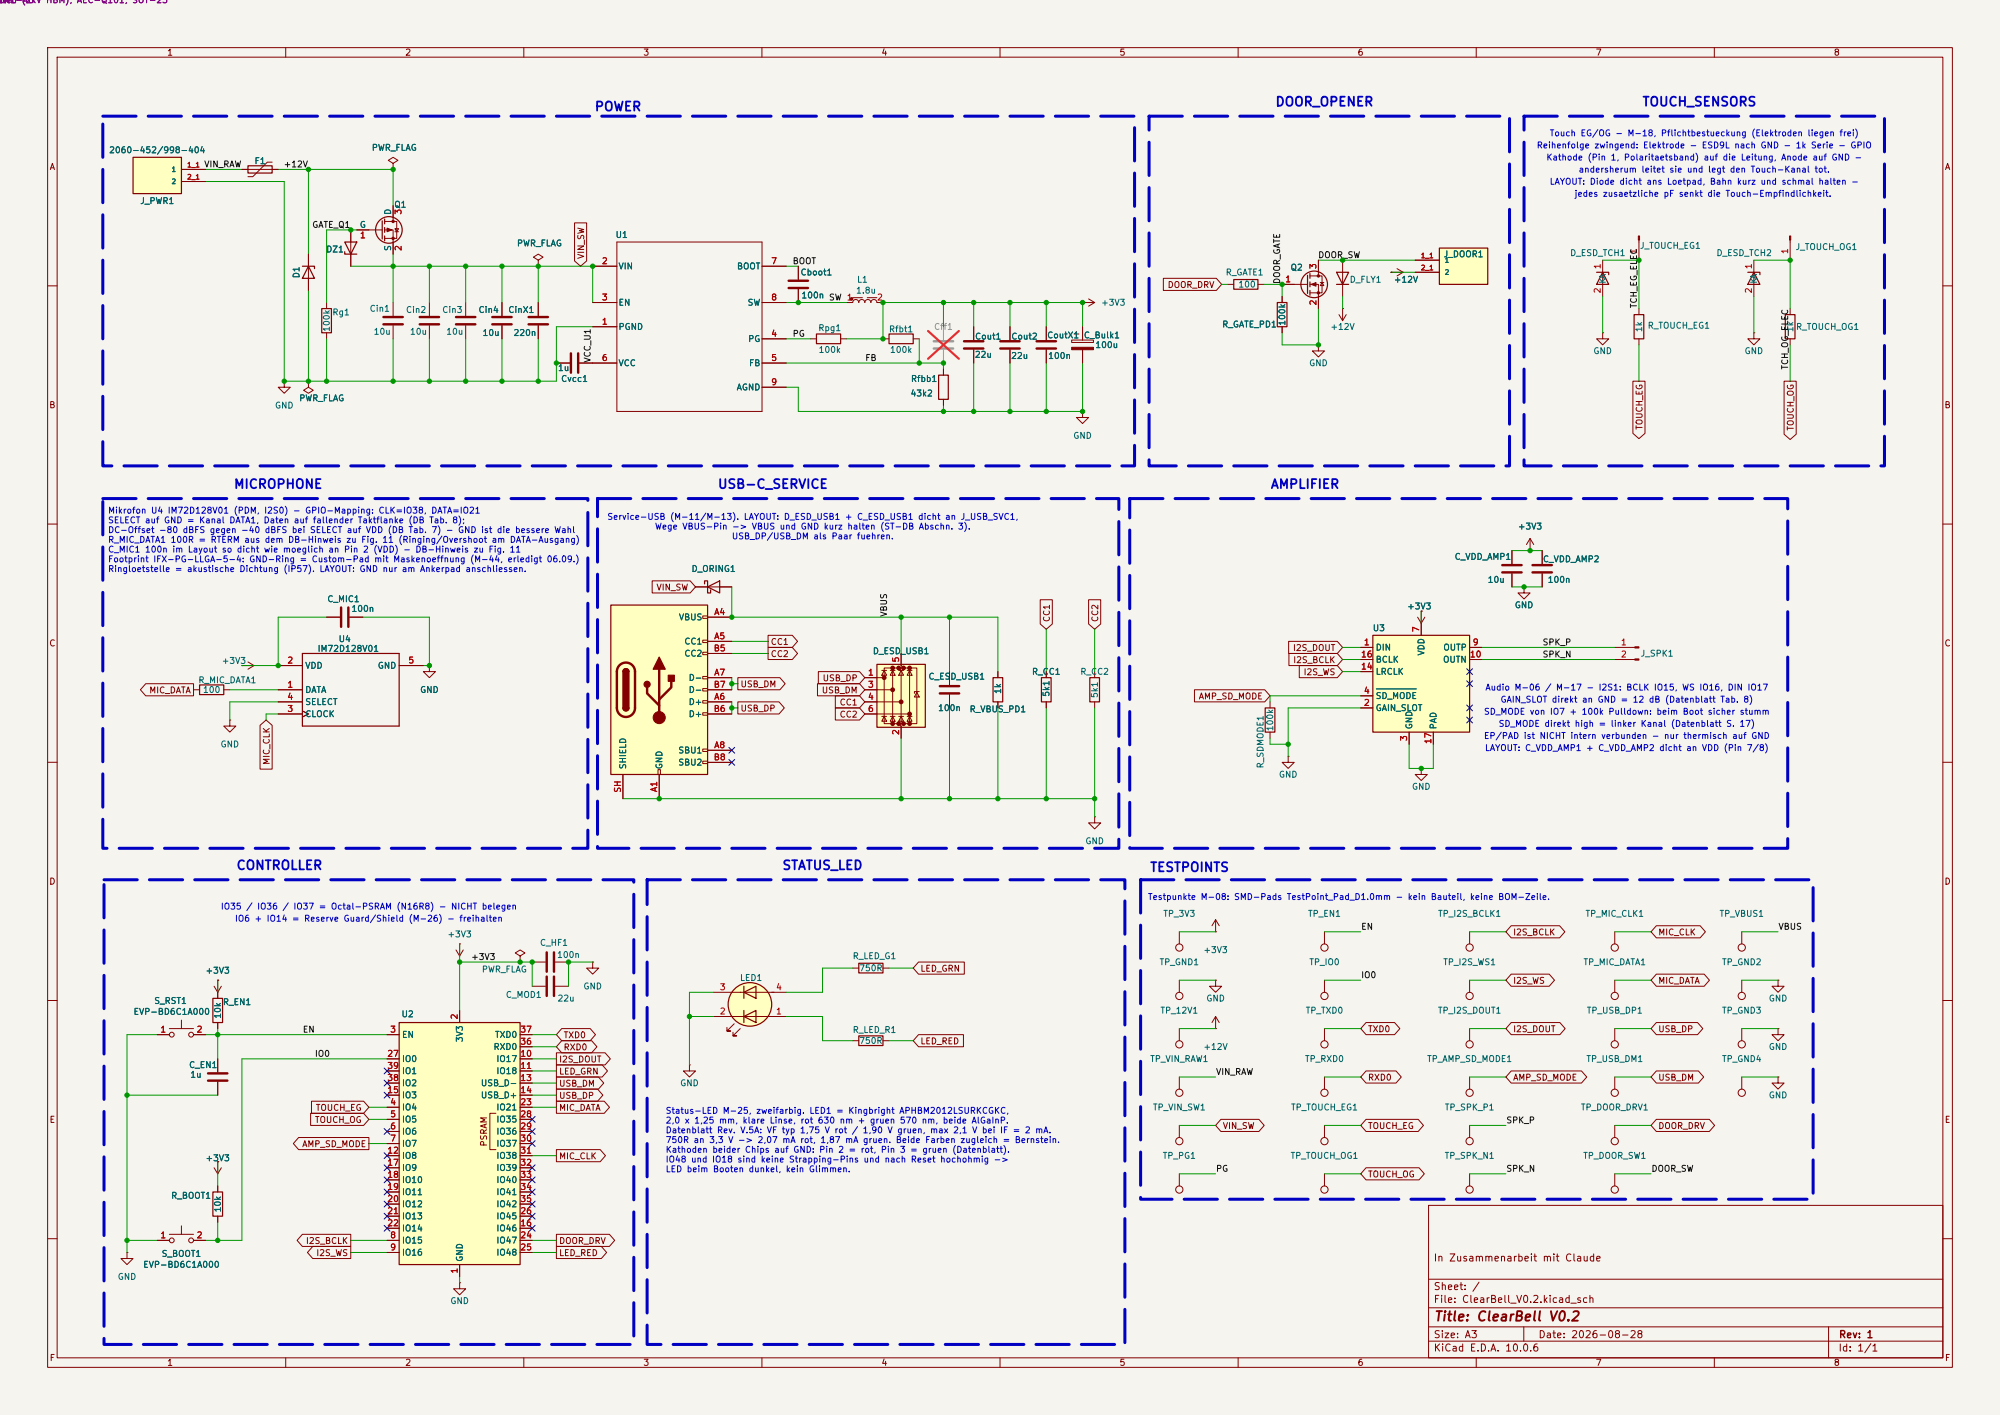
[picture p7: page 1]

andersherum leitet sie und legt den Touch-Kanal tot. TOUCH_SENSORS

Touch EG/OG - M-18, Pflichtbestueckung (Elektroden liegen frei) Service-USB (M-11/M-13). LAYOUT: D_ESD_USB1 + C_ESD_USB1 dicht an J_USB_SVC1,

Reihenfolge zwingend: Elektrode - ESD9L nach GND - 1k Serie - GPIO USB-C_SERVICE

Kathode (Pin 1, Polaritaetsband) auf die Leitung, Anode auf GND -

LAYOUT: Diode dicht ans Loetpad, Bahn kurz und schmal halten - AMPLIFIER

jedes zusaetzliche pF senkt die Touch-Empfindlichkeit.

GAIN_SLOT direkt an GND = 12 dB (Datenblatt Tab. 8) Mikrofon U4 IM72D128V01 (PDM, I2S0) - GPIO-Mapping: CLK=IO38, DATA=IO21
SELECT auf GND = Kanal DATA1, Daten auf fallender Taktflanke (DB Tab. 8); DC-Offset -80 dBFS gegen -40 dBFS bei SELECT auf VDD (DB Tab. 7) - GND ist die bessere Wahl R_MIC_DATA1 100R = RTERM aus dem DB-Hinweis zu Fig. 11 (Ringing/Overshoot am DATA-Ausgang) C_MIC1 100n im Layout so dicht wie moeglich an Pin 2 (VDD) - DB-Hinweis zu Fig. 11

Wege VBUS-Pin -> VBUS und GND kurz halten (ST-DB Abschn. 3).
USB_DP/USB_DM als Paar fuehren. Status-LED M-25, zweifarbig. LED1 = Kingbright APHBM2012LSURKCGKC,

Footprint IFX-PG-LLGA-5-4: GND-Ring = Custom-Pad mit Maskenoeffnung (M-44, erledigt 06.09.)

Audio M-06 / M-17 - I2S1: BCLK IO15, WS IO16, DIN IO17 CONTROLLER

EP/PAD ist NICHT intern verbunden - nur thermisch auf GND
LAYOUT: C_VDD_AMP1 + C_VDD_AMP2 dicht an VDD (Pin 7/8)

Testpunkte M-08: SMD-Pads TestPoint_Pad_D1.0mm - kein Bauteil, keine BOM-Zeile. TESTPOINTS

IO35 / IO36 / IO37 = Octal-PSRAM (N16R8) - NICHT belegen
IO6 + IO14 = Reserve Guard/Shield (M-26) - freihalten

2,0 x 1,25 mm, klare Linse, rot 630 nm + gruen 570 nm, beide AlGaInP. Datenblatt Rev. V.5A: VF typ 1,75 V rot / 1,90 V gruen, max 2,1 V bei IF = 2 mA. 750R an 3,3 V -> 2,07 mA rot, 1,87 mA gruen. Beide Farben zugleich = Bernstein. Kathoden beider Chips auf GND: Pin 2 = rot, Pin 3 = gruen (Datenblatt).

IO48 und IO18 sind keine Strapping-Pins und nach Reset hochohmig ->
LED beim Booten dunkel, kein Glimmen.

Size: A3 | Rev: 1 | F Date: 2026-08-28
KiCad E.D.A. 10.0.6 | Id: 1/1

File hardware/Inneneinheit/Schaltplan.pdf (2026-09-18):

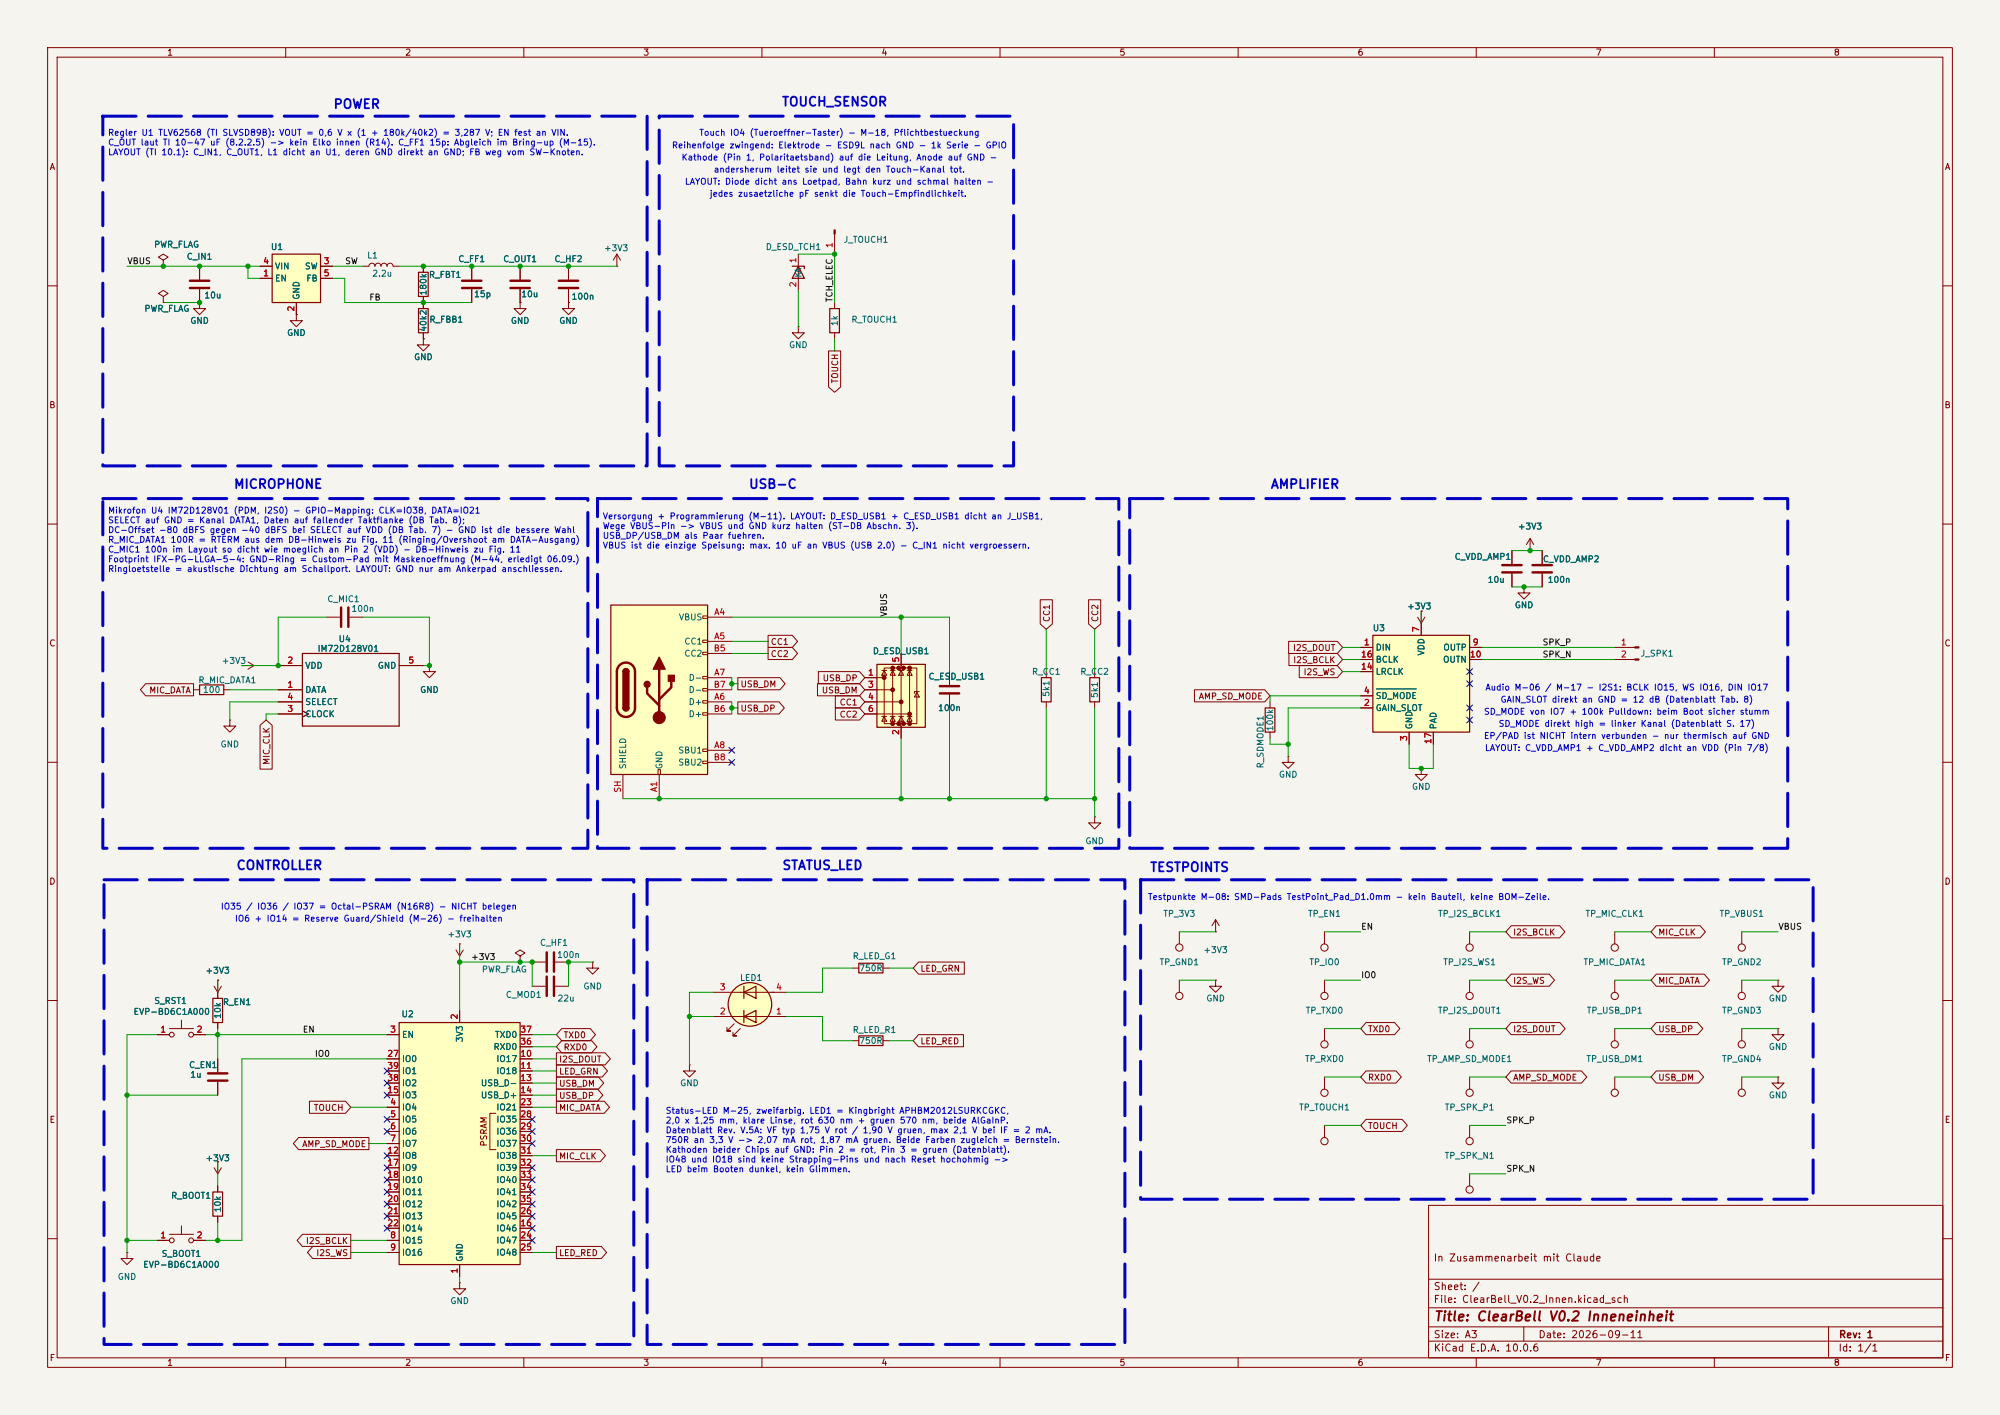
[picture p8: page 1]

Regler U1 TLV62568 (TI SLVSD89B): VOUT = 0,6 V x (1 + 180k/40k2) = 3,287 V; EN fest an VIN. C_OUT laut TI 10-47 uF (8.2.2.5) -> kein Elko innen (R14). C_FF1 15p: Abgleich im Bring-up (M-15). LAYOUT (TI 10.1): C_IN1, C_OUT1, L1 dicht an U1, deren GND direkt an GND; FB weg vom SW-Knoten.

Touch IO4 (Tueroeffner-Taster) - M-18, Pflichtbestueckung Kathode (Pin 1, Polaritaetsband) auf die Leitung, Anode auf GND - USB-C

jedes zusaetzliche pF senkt die Touch-Empfindlichkeit. andersherum leitet sie und legt den Touch-Kanal tot. Reihenfolge zwingend: Elektrode - ESD9L nach GND - 1k Serie - GPIO

LAYOUT: Diode dicht ans Loetpad, Bahn kurz und schmal halten -

EP/PAD ist NICHT intern verbunden - nur thermisch auf GND AMPLIFIER

Testpunkte M-08: SMD-Pads TestPoint_Pad_D1.0mm - kein Bauteil, keine BOM-Zeile. LAYOUT: C_VDD_AMP1 + C_VDD_AMP2 dicht an VDD (Pin 7/8) Audio M-06 / M-17 - I2S1: BCLK IO15, WS IO16, DIN IO17 Mikrofon U4 IM72D128V01 (PDM, I2S0) - GPIO-Mapping: CLK=IO38, DATA=IO21
SELECT auf GND = Kanal DATA1, Daten auf fallender Taktflanke (DB Tab. 8); DC-Offset -80 dBFS gegen -40 dBFS bei SELECT auf VDD (DB Tab. 7) - GND ist die bessere Wahl R_MIC_DATA1 100R = RTERM aus dem DB-Hinweis zu Fig. 11 (Ringing/Overshoot am DATA-Ausgang) C_MIC1 100n im Layout so dicht wie moeglich an Pin 2 (VDD) - DB-Hinweis zu Fig. 11

Versorgung + Programmierung (M-11). LAYOUT: D_ESD_USB1 + C_ESD_USB1 dicht an J_USB1,
Wege VBUS-Pin -> VBUS und GND kurz halten (ST-DB Abschn. 3).

Footprint IFX-PG-LLGA-5-4: GND-Ring = Custom-Pad mit Maskenoeffnung (M-44, erledigt 06.09.)
Ringloetstelle = akustische Dichtung am Schallport. LAYOUT: GND nur am Ankerpad anschliessen. CONTROLLER

GAIN_SLOT direkt an GND = 12 dB (Datenblatt Tab. 8) SD_MODE direkt high = linker Kanal (Datenblatt S. 17)
SD_MODE von IO7 + 100k Pulldown: beim Boot sicher stumm

IO35 / IO36 / IO37 = Octal-PSRAM (N16R8) - NICHT belegen

Status-LED M-25, zweifarbig. LED1 = Kingbright APHBM2012LSURKCGKC,
2,0 x 1,25 mm, klare Linse, rot 630 nm + gruen 570 nm, beide AlGaInP. Datenblatt Rev. V.5A: VF typ 1,75 V rot / 1,90 V gruen, max 2,1 V bei IF = 2 mA. 750R an 3,3 V -> 2,07 mA rot, 1,87 mA gruen. Beide Farben zugleich = Bernstein. Kathoden beider Chips auf GND: Pin 2 = rot, Pin 3 = gruen (Datenblatt).

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

In Zusammenarbeit mit Claude

Size: A3 | Rev: 1 | F Date: 2026-09-11
KiCad E.D.A. 10.0.6 | Id: 1/1

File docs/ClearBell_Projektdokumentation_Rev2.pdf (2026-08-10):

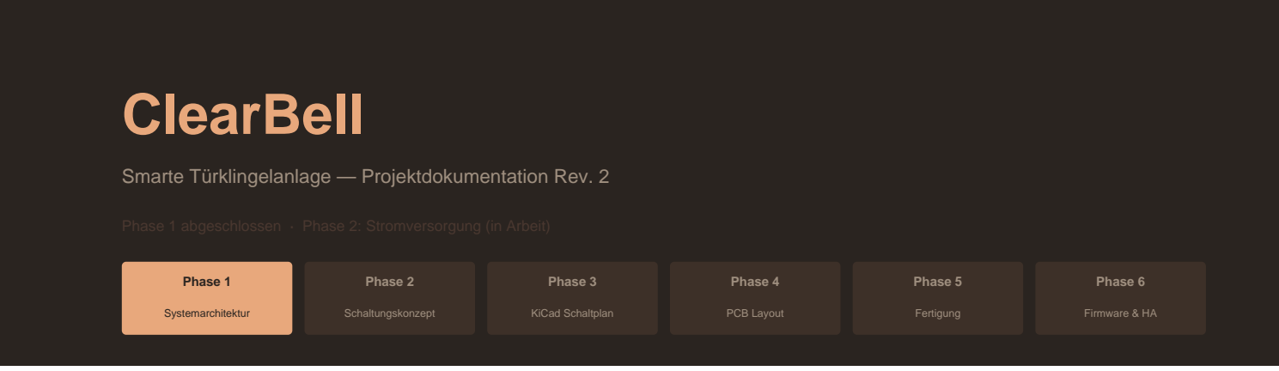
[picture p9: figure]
ClearBell; Phase 1; Systemarchitektur; Phase 2; Schaltungskonzept; Phase 3; KiCad Schaltplan; Phase 4; PCB Layout; Phase 5; Fertigung; Phase 6; Firmware & HA

## Smarte Türklingelanlage — Projektdokumentation Rev. 2

Phase 1 abgeschlossen · Phase 2: Stromversorgung (in Arbeit)

### SYSTEMÜBERSICHT — REV. 2

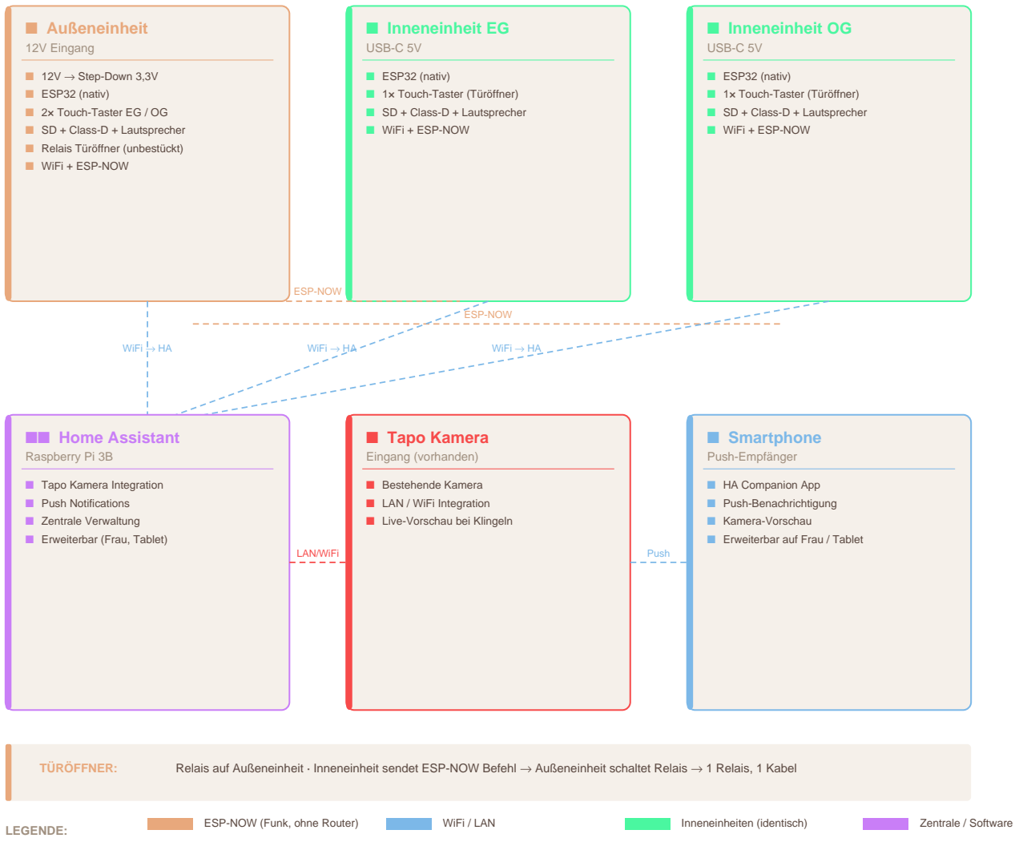
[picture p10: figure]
■ Außeneinheit; 12V Eingang; ■ 12V → Step-Down 3,3V ■ ESP32 (nativ) ■ 2× Touch-Taster EG / OG ■ SD + Class-D + Lautsprecher ■ Relais Türöffner (unbestückt) ■ WiFi + ESP-NOW; ■ Inneneinheit EG; USB-C 5V; ■ ESP32 (nativ) ■ 1× Touch-Taster (Türöffner) ■ SD + Class-D + Lautsprecher ■ WiFi + ESP-NOW; ■ Inneneinheit OG; WiFi → HA; ESP-NOW; ■■ Home Assistant; Raspberry Pi 3B; ■ Tapo Kamera Integration ■ Push Notifications ■ Zentrale Verwaltung ■ Erweiterbar (Frau, Tablet); ■ Tapo Kamera; Eingang (vorhanden); ■ Bestehende Kamera ■ LAN / WiFi Integration ■ Live-Vorschau bei Klingeln; ■ Smartphone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

TÜRÖFFNER: | Relais auf Außeneinheit · Inneneinheit sendet ESP-NOW Befehl → Außeneinheit schaltet Relais → 1 Relais, 1 Kabel

ClearBell Projektdokumentation Rev. 2 · Phase 1 abgeschlossen · Seite 1

# ClearBell

## Anforderungen & Projektplan — Rev. 2

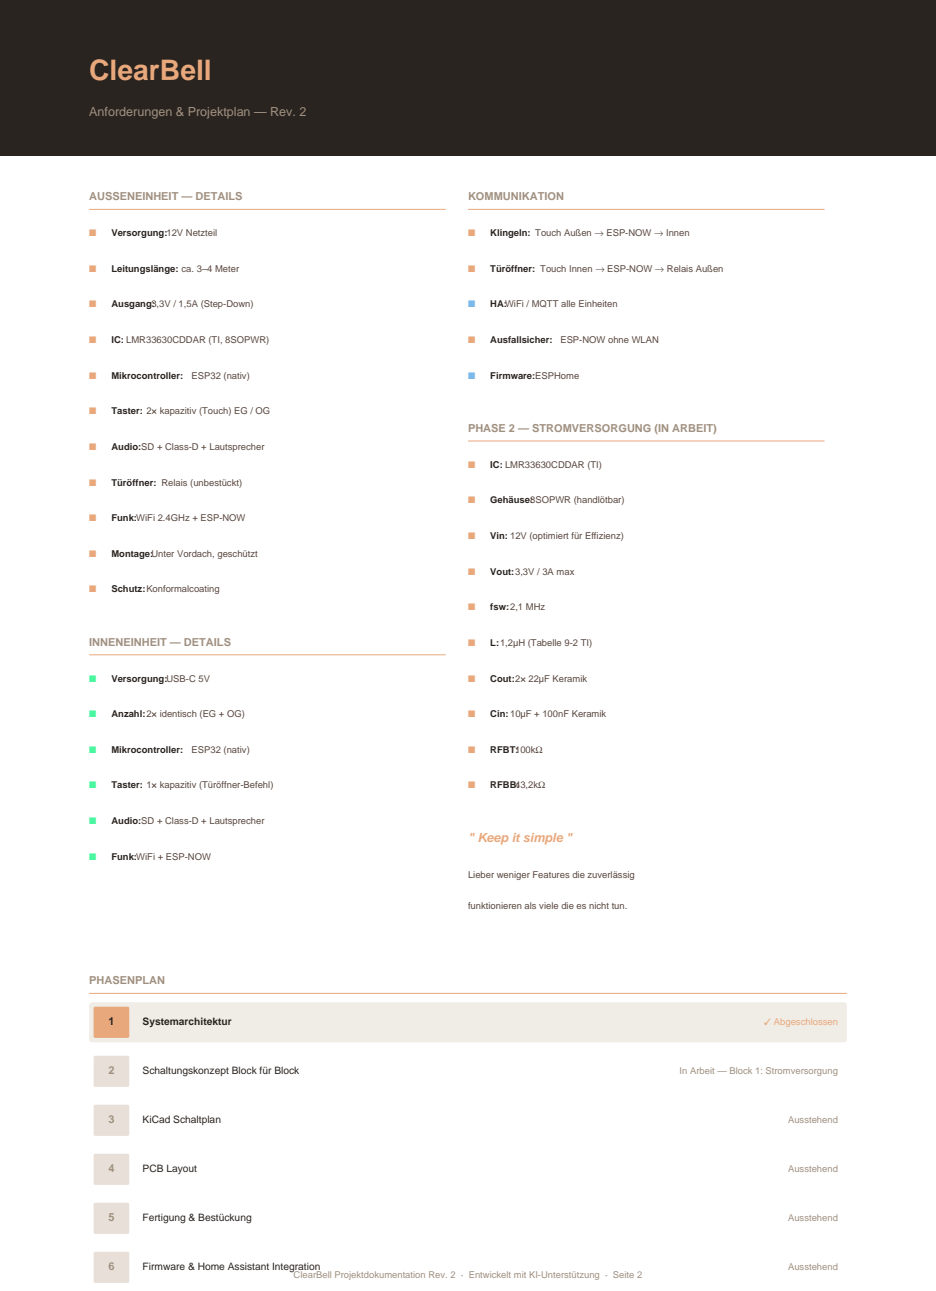
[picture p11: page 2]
AUSSENEINHEIT — DETAILS; Versorgung:12V Netzteil; Leitungslänge: ca. 3–4 Meter; Ausgang:3,3V / 1,5A (Step-Down); IC: LMR33630CDDAR (TI, 8SOPWR); Mikrocontroller: ESP32 (nativ); Taster: 2× kapazitiv (Touch) EG / OG; Audio:SD + Class-D + Lautsprecher; Türöffner: Relais (unbestückt); Funk:WiFi 2.4GHz + ESP-NOW; Montage:Unter Vordach, geschützt; Schutz:Konformalcoating; INNENEINHEIT — DETAILS; Versorgung:USB-C 5V; Anzahl:2× identisch (EG + OG); Taster: 1× kapazitiv (Türöffner-Befehl)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

PHASE 2 — STROMVERSORGUNG (IN ARBEIT)

" Keep it simple "

Lieber weniger Features die zuverlässig

funktionieren als viele die es nicht tun.

ClearBell Projektdokumentation Rev. 2 · Entwickelt mit KI-Unterstützung · Seite 2

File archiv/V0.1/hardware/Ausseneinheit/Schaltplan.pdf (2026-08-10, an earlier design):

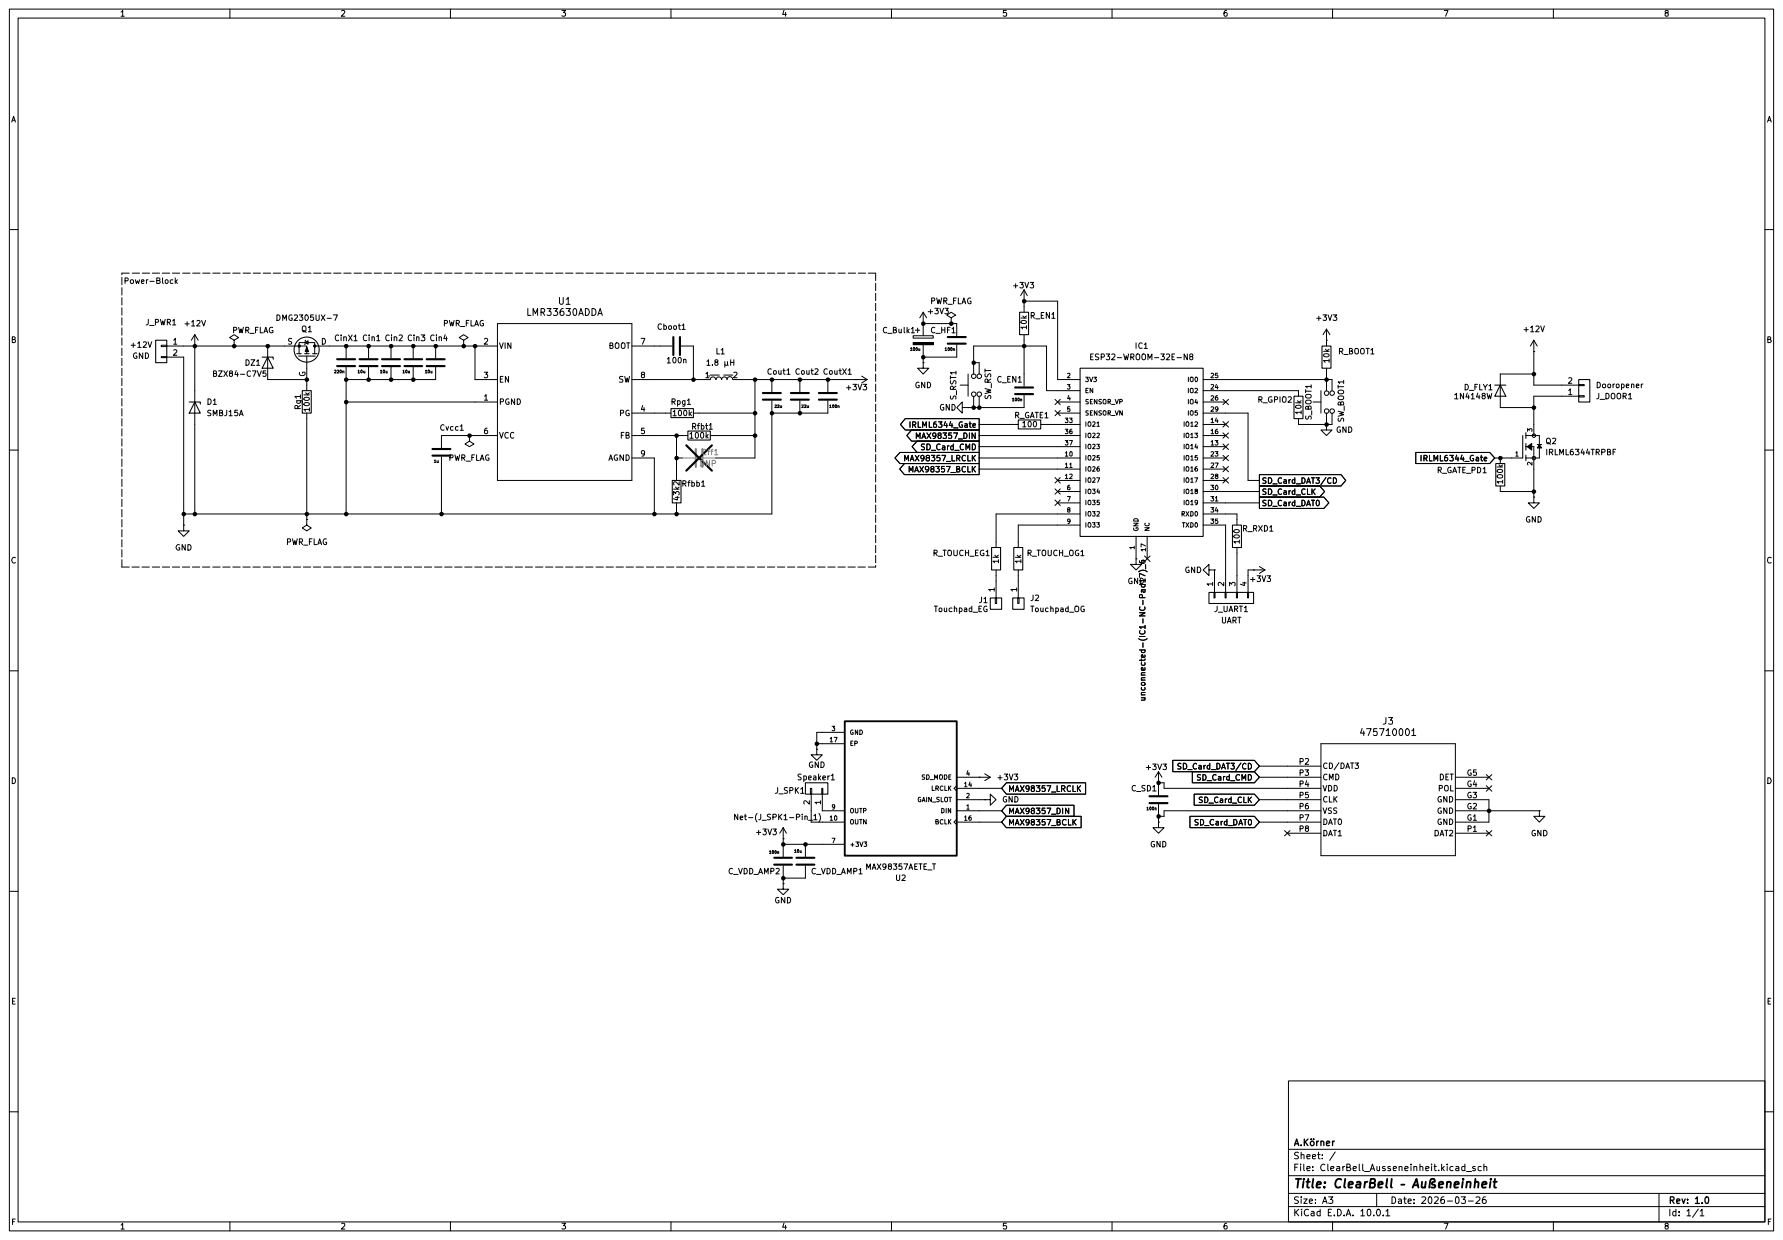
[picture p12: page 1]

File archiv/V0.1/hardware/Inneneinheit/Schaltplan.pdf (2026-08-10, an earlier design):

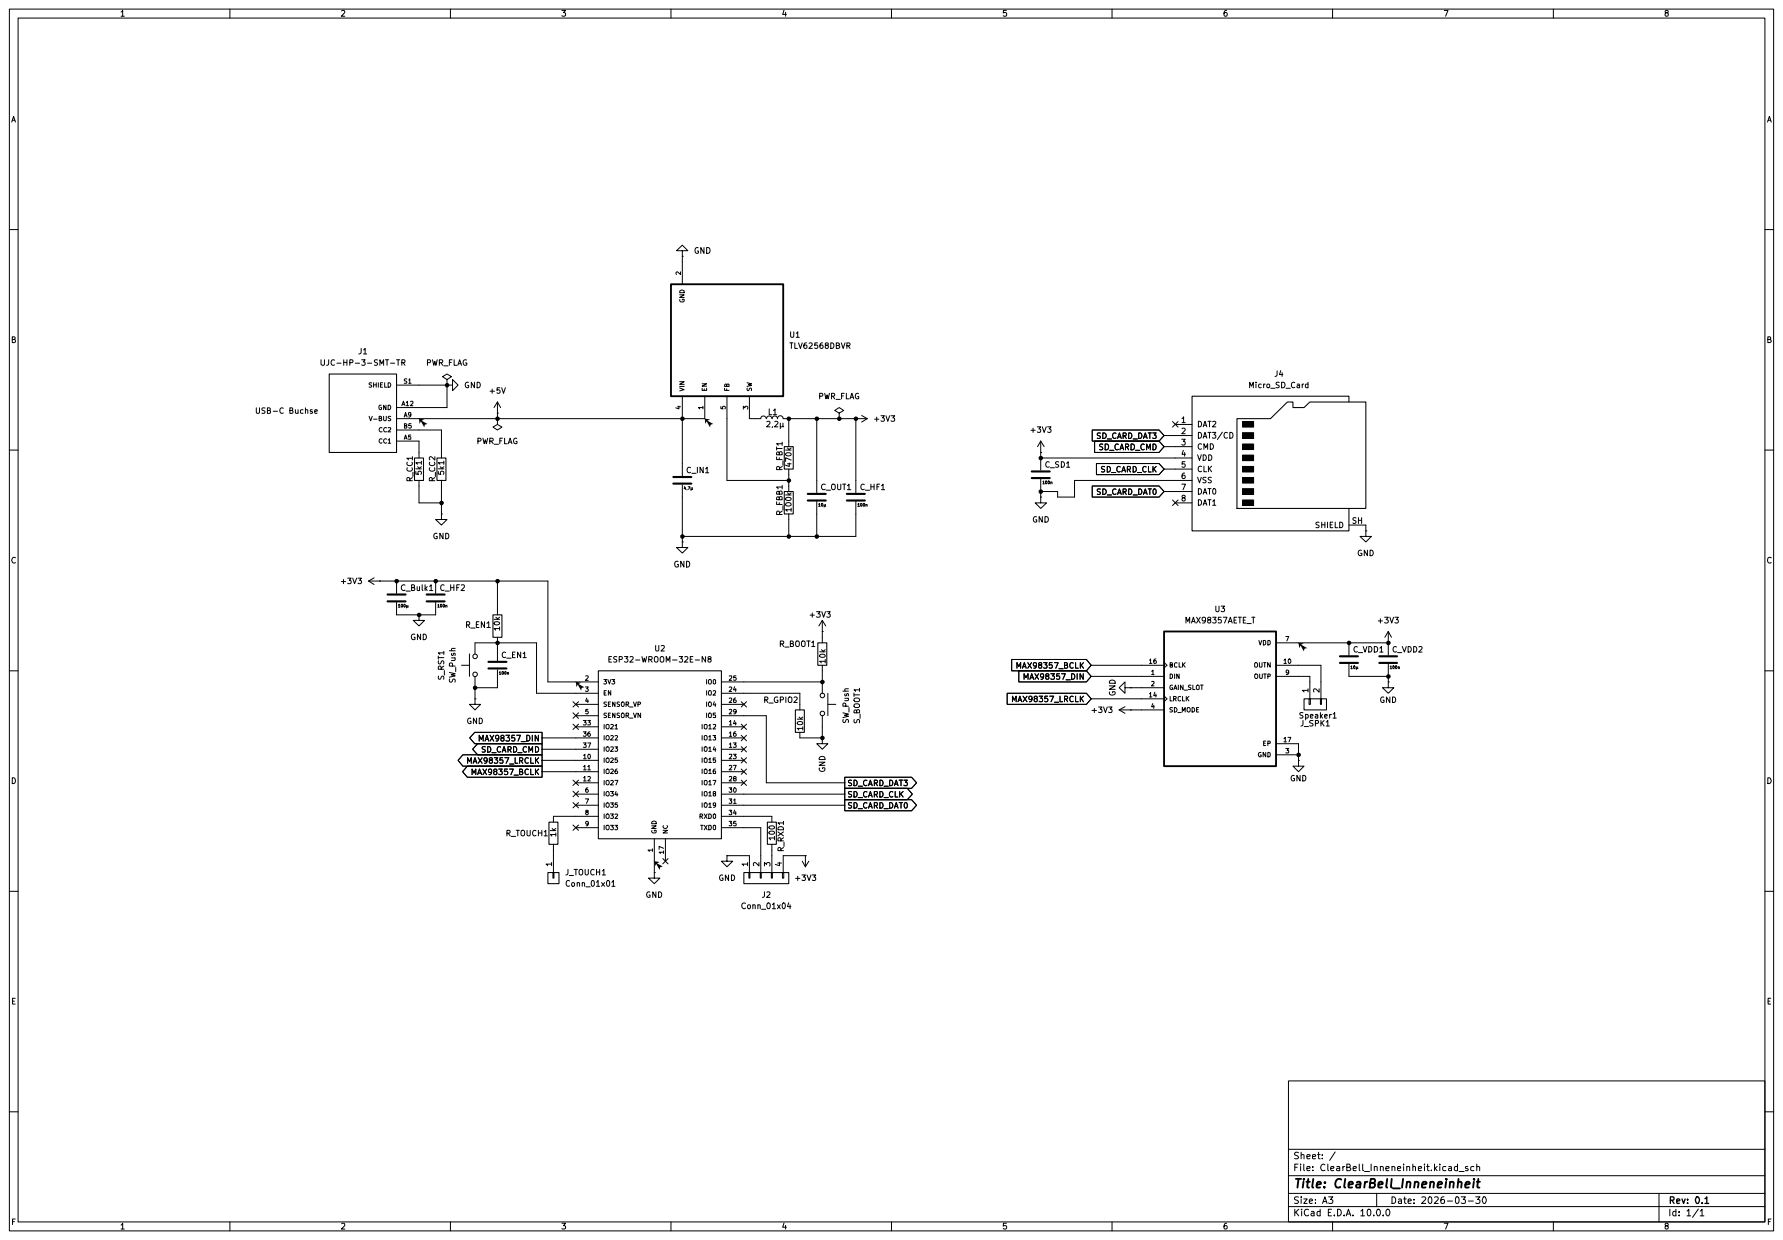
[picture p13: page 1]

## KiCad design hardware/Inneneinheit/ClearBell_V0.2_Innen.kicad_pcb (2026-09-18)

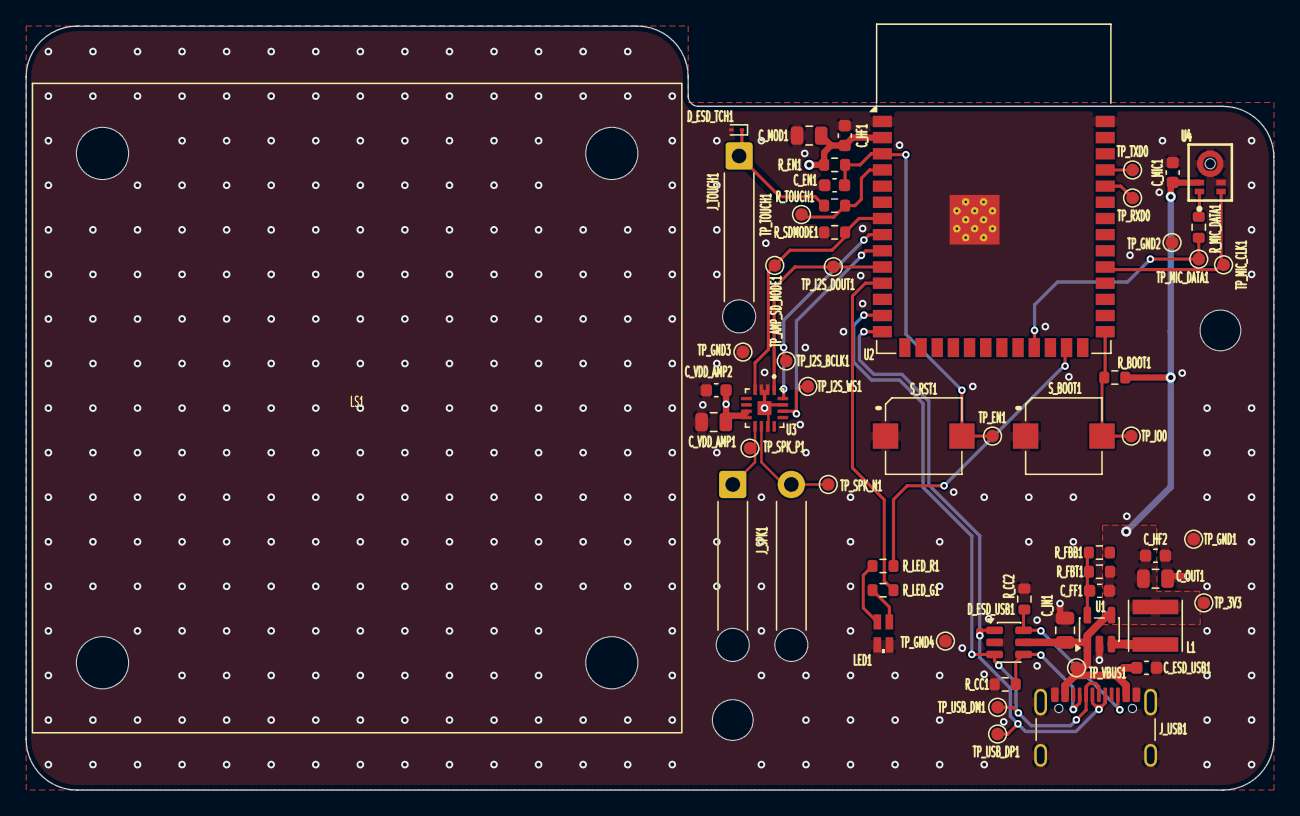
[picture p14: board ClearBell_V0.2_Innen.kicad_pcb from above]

Board: 4 copper layers, 98.0 x 60.0 mm, 59 parts (0 on the bottom side), 28 nets.

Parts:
C_EN1: 1u; C_0603_1608Metric
C_ESD_USB1: 100n; C_0603_1608Metric
C_FF1: 15p; C_0603_1608Metric
C_HF1, C_HF2: 100n; C_0603_1608Metric
C_IN1: 10u; C_0805_2012Metric
C_MIC1: 100n; C_0603_1608Metric
C_MOD1: 22u; C_0805_2012Metric
C_OUT1: 10u; C_0805_2012Metric
C_VDD_AMP1: 10u; C_0805_2012Metric
C_VDD_AMP2: 100n; C_0603_1608Metric
D_ESD_TCH1: ESD9L5.0ST5G; D_SOD-923
D_ESD_USB1: USBLC6-4SC6; SOT-23-6
H1, H2: MountingHole_3.2mm_M3
J_SPK1: Loetpads Lautsprecher; SolderWire-0.5sqmm_1x02_P4.6mm_D0.9mm_OD2.1mm_Relief
J_TOUCH1: Loetpad Elektrode; SolderWire-0.5sqmm_1x01_D0.9mm_OD2.1mm_Relief
J_USB1: USB4105-GF-A-120; USB_C_Receptacle_GCT_USB4105-xx-A_16P_TopMnt_Horizontal
L1: 2.2u; L_Cyntec_SDER041H_4.0x4.0x1.8mm
LED1: APHBM2012LSURKCGKC; LED_Kingbright_APHBM2012_2x1.25mm
LS1: K 50 SQ; LS_Visaton_K50SQ_51x51mm
R_BOOT1: 10k; R_0603_1608Metric
R_CC1, R_CC2: 5k1; R_0603_1608Metric
R_EN1: 10k; R_0603_1608Metric
R_FBB1: 40k2; R_0603_1608Metric
R_FBT1: 180k; R_0603_1608Metric
R_LED_G1: 750R; R_0603_1608Metric
R_LED_R1: 750R; R_0603_1608Metric
R_MIC_DATA1: 100; R_0603_1608Metric
R_SDMODE1: 100k; R_0603_1608Metric
R_TOUCH1: 1k; R_0603_1608Metric
S_BOOT1: EVP-BD6C1A000
S_RST1: EVP-BD6C1A000
TP_3V3: TestPoint_Pad_D1.0mm
TP_AMP_SD_MODE1: TestPoint_Pad_D1.0mm
TP_EN1: TestPoint_Pad_D1.0mm
TP_GND1, TP_GND2, TP_GND3, TP_GND4: TestPoint_Pad_D1.0mm
TP_I2S_BCLK1, TP_I2S_DOUT1, TP_I2S_WS1: TestPoint_Pad_D1.0mm
TP_IO0: TestPoint_Pad_D1.0mm
TP_MIC_CLK1: TestPoint_Pad_D1.0mm
TP_MIC_DATA1: TestPoint_Pad_D1.0mm
TP_RXD0: TestPoint_Pad_D1.0mm
TP_SPK_N1: TestPoint_Pad_D1.0mm
TP_SPK_P1: TestPoint_Pad_D1.0mm
TP_TOUCH1: TestPoint_Pad_D1.0mm
TP_TXD0: TestPoint_Pad_D1.0mm
TP_USB_DM1: TestPoint_Pad_D1.0mm
TP_USB_DP1: TestPoint_Pad_D1.0mm
TP_VBUS1: TestPoint_Pad_D1.0mm
U1: TLV62568DBVR; SOT-23-5
U2: ESP32-S3-WROOM-1-N16R8; ESP32-S3-WROOM-1
U3: MAX98357AETE+T; QFN50P300X300X80-17N
U4: IM72D128V01; IFX-PG-LLGA-5-4

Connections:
+3V3: C_FF1.1, C_HF1.1, C_HF2.1, C_MIC1.1, C_MOD1.1, C_OUT1.1, C_VDD_AMP1.1, C_VDD_AMP2.1, L1.2, R_BOOT1.1, R_EN1.1, R_FBT1.1, TP_3V3.1, U2.2, U3.7, U3.8, U4.2
/EN: C_EN1.1, R_EN1.2, S_RST1.2, TP_EN1.1, U2.3
/FB: C_FF1.2, R_FBB1.1, R_FBT1.2, U1.5
/IO0: R_BOOT1.2, S_BOOT1.2, TP_IO0.1, U2.27
/SPK_N: J_SPK1.2, TP_SPK_N1.1, U3.10
/SPK_P: J_SPK1.1, TP_SPK_P1.1, U3.9
/SW: L1.1, U1.3
/TCH_ELEC: D_ESD_TCH1.1, J_TOUCH1.1, R_TOUCH1.1
/VBUS: C_ESD_USB1.1, C_IN1.1, D_ESD_USB1.5, J_USB1.A4, J_USB1.A9, J_USB1.B4, J_USB1.B9, TP_VBUS1.1, U1.1, U1.4
AMP_SD_MODE: R_SDMODE1.1, TP_AMP_SD_MODE1.1, U2.7, U3.4
CC1: D_ESD_USB1.4, J_USB1.A5, R_CC1.1
CC2: D_ESD_USB1.6, J_USB1.B5, R_CC2.1
GND: C_EN1.2, C_ESD_USB1.2, C_HF1.2, C_HF2.2, C_IN1.2, C_MIC1.2, C_MOD1.2, C_OUT1.2, C_VDD_AMP1.2, C_VDD_AMP2.2, D_ESD_TCH1.2, D_ESD_USB1.2, J_USB1.A1, J_USB1.A12, J_USB1.B1, J_USB1.B12, J_USB1.SH, LED1.2, LED1.3, R_CC1.2, R_CC2.2, R_FBB1.2, R_SDMODE1.2, S_BOOT1.1, S_RST1.1, TP_GND1.1, TP_GND2.1, TP_GND3.1, TP_GND4.1, U1.2, U2.1, U2.40, U2.41, U3.2, U3.3, U3.11, U3.15, U3.17, U4.4, U4.5
I2S_BCLK: TP_I2S_BCLK1.1, U2.8, U3.16
I2S_DOUT: TP_I2S_DOUT1.1, U2.10, U3.1
I2S_WS: TP_I2S_WS1.1, U2.9, U3.14
LED_GRN: R_LED_G1.2, U2.11
LED_RED: R_LED_R1.2, U2.25
MIC_CLK: TP_MIC_CLK1.1, U2.31, U4.3
MIC_DATA: R_MIC_DATA1.1, TP_MIC_DATA1.1, U2.23
unnamed: LED1.1, R_LED_R1.1
unnamed: LED1.4, R_LED_G1.1
unnamed: R_MIC_DATA1.2, U4.1
RXD0: TP_RXD0.1, U2.36
TOUCH: R_TOUCH1.2, TP_TOUCH1.1, U2.4
TXD0: TP_TXD0.1, U2.37
USB_DM: D_ESD_USB1.3, J_USB1.A7, J_USB1.B7, TP_USB_DM1.1, U2.13
USB_DP: D_ESD_USB1.1, J_USB1.A6, J_USB1.B6, TP_USB_DP1.1, U2.14

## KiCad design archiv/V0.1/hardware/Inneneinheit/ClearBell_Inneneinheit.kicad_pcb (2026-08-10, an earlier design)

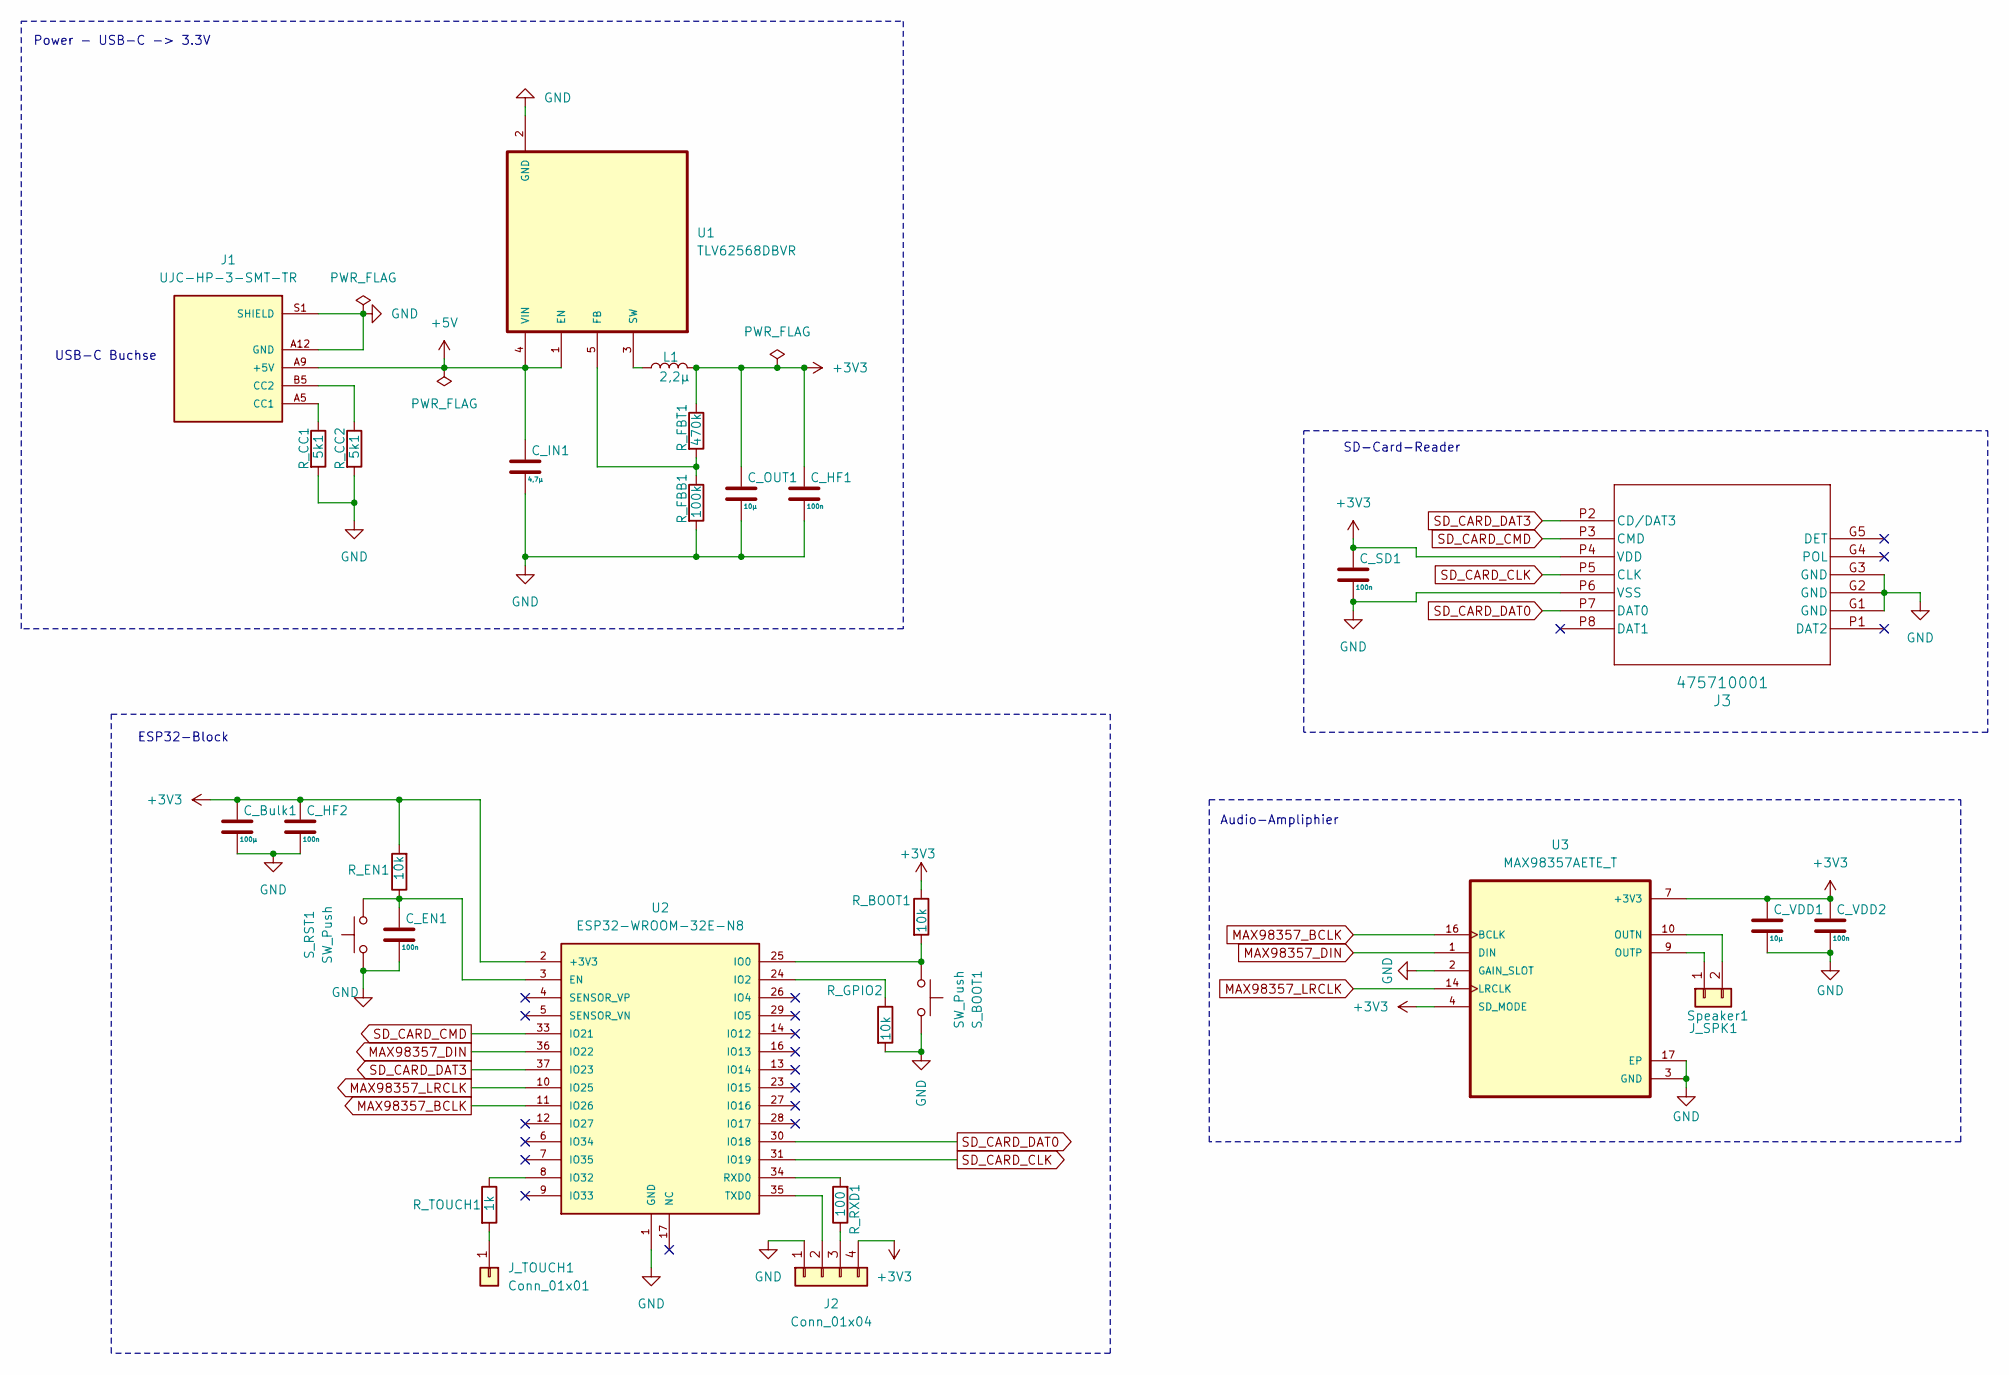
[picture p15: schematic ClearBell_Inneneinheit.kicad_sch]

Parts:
C_Bulk1: 100µ; C_Elec_6.3x5.4
C_EN1: 100n; C_0603_1608Metric_Pad1.08x0.95mm_HandSolder
C_HF1, C_HF2: 100n; C_0603_1608Metric_Pad1.08x0.95mm_HandSolder
C_IN1: 4,7µ; C_0603_1608Metric_Pad1.08x0.95mm_HandSolder
C_OUT1: 10µ; C_0603_1608Metric_Pad1.08x0.95mm_HandSolder
C_SD1: 100n; C_0603_1608Metric_Pad1.08x0.95mm_HandSolder
C_VDD1: 10µ; C_0603_1608Metric_Pad1.08x0.95mm_HandSolder
C_VDD2: 100n; C_0603_1608Metric_Pad1.08x0.95mm_HandSolder
J1: UJC-HP-3-SMT-TR; CUI_UJC-HP-3-SMT-TR; PARTREV 04/30/2020
J2: Conn_01x04; PinSocket_1x04_P2.54mm_Horizontal
J3: 475710001; MOLEX MICRO SD CARD_475710001; MANUFACTURER_PART_NUMBER 0475710001; Digi-Key_Part_Number WM9731CT-ND
J_SPK1: Speaker1; Wago_2086-1202
J_TOUCH1: Conn_01x01; TestPoint_Pad_2.0x2.0mm
L1: 2,2µ; L_Wurth_WE-MAPI-4020HT; MANUFACTURER_PART_NUMBER SDER041H-2R2MS; Digi-Key_Part_Number 2037-SDER041H-2R2MSCT-ND
R_BOOT1: 10k; R_0603_1608Metric_Pad0.98x0.95mm_HandSolder
R_CC1, R_CC2: 5k1; R_0603_1608Metric_Pad0.98x0.95mm_HandSolder
R_EN1: 10k; R_0603_1608Metric_Pad0.98x0.95mm_HandSolder
R_FBB1: 100k; R_0603_1608Metric_Pad0.98x0.95mm_HandSolder
R_FBT1: 470k; R_0603_1608Metric_Pad0.98x0.95mm_HandSolder
R_GPIO2: 10k; R_0603_1608Metric_Pad0.98x0.95mm_HandSolder
R_RXD1: 100; R_0603_1608Metric_Pad0.98x0.95mm_HandSolder
R_TOUCH1: 1k; R_0603_1608Metric_Pad0.98x0.95mm_HandSolder
S_BOOT1: SW_Push; CK_PTS526; MANUFACTURER_PART_NUMBER PTS526SK15SMTR2 LFS; Digi-Key_Part_Number CKN12221-1-ND
S_RST1: SW_Push; CK_PTS526; MANUFACTURER_PART_NUMBER PTS526SK15SMTR2 LFS; Digi-Key_Part_Number CKN12221-1-ND
U1: TLV62568DBVR; SOT95P280X145-5N; Digi-Key_Part_Number 296-47359-1-ND
U2: ESP32-WROOM-32E-N8; ESP32WROOM32EN8; MOUSER_PART_NUMBER 356-ESP32WRM32E164PH
U3: MAX98357AETE_T; QFN50P300X300X80-17N; MANUFACTURER_PART_NUMBER MAX98357AETE+T; Digi-Key_Part_Number MAX98357AETE+TCT-ND

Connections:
+3V3: C_Bulk1.1, C_HF1.1, C_HF2.1, C_OUT1.1, C_SD1.1, C_VDD1.1, C_VDD2.1, J2.4, J3.P4 (VDD), L1.2, R_BOOT1.1, R_EN1.2, R_FBT1.1, U2.2 (+3V3), U3.4 (SD_MODE), U3.7 (+3V3), U3.8 (+3V3)
+5V: C_IN1.1, J1.A9 (+5V), J1.B9 (+5V), U1.1 (EN), U1.4 (VIN)
GND: C_Bulk1.2, C_EN1.2, C_HF1.2, C_HF2.2, C_IN1.2, C_OUT1.2, C_SD1.2, C_VDD1.2, C_VDD2.2, J1.A12 (GND), J1.B12 (GND), J1.S1 (SHIELD), J1.S2 (SHIELD), J1.S3 (SHIELD), J1.S4 (SHIELD), J2.1, J3.G1 (GND), J3.G2 (GND), J3.G3 (GND), J3.P6 (VSS), R_CC1.2, R_CC2.2, R_FBB1.2, R_GPIO2.2, S_BOOT1.2, S_RST1.1, U1.2 (GND), U2.1 (GND), U2.15 (GND), U2.38 (GND), U2.39 (GND), U2.40 (GND), U2.41 (GND), U2.42 (GND), U2.43 (GND), U2.44 (GND), U2.45 (GND), U2.46 (GND), U2.47 (GND), U3.2 (GAIN_SLOT), U3.3 (GND), U3.11 (GND), U3.15 (GND), U3.17 (EP)
MAX98357_BCLK: U2.11 (IO26), U3.16 (BCLK)
MAX98357_DIN: U2.36 (IO22), U3.1 (DIN)
MAX98357_LRCLK: U2.10 (IO25), U3.14 (LRCLK)
unnamed: J1.A5 (CC1), R_CC1.1
unnamed: J1.B5 (CC2), R_CC2.1
unnamed: J2.2, U2.35 (TXD0)
unnamed: J2.3, R_RXD1.1
unnamed: J_SPK1.1, U3.9 (OUTP)
unnamed: J_SPK1.2, U3.10 (OUTN)
unnamed: J_TOUCH1.1 (Pin_1_1), R_TOUCH1.2
unnamed: R_FBB1.1, R_FBT1.2, U1.5 (FB)
unnamed: L1.1, U1.3 (SW)
unnamed: C_EN1.1, R_EN1.1, S_RST1.2, U2.3 (EN)
unnamed: R_BOOT1.2, S_BOOT1.1, U2.25 (IO0)
unnamed: R_GPIO2.1, U2.24 (IO2)
unnamed: R_TOUCH1.1, U2.8 (IO32)
unnamed: R_RXD1.2, U2.34 (RXD0)
SD_CARD_CLK: J3.P5 (CLK), U2.31 (IO19)
SD_CARD_CMD: J3.P3 (CMD), U2.33 (IO21)
SD_CARD_DAT0: J3.P7 (DAT0), U2.30 (IO18)
SD_CARD_DAT3: J3.P2 (CD/DAT3), U2.37 (IO23)

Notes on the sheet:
USB-C Buchse
ESP32-Block
Audio-Ampliphier
SD-Card-Reader
Power - USB-C -> 3.3V

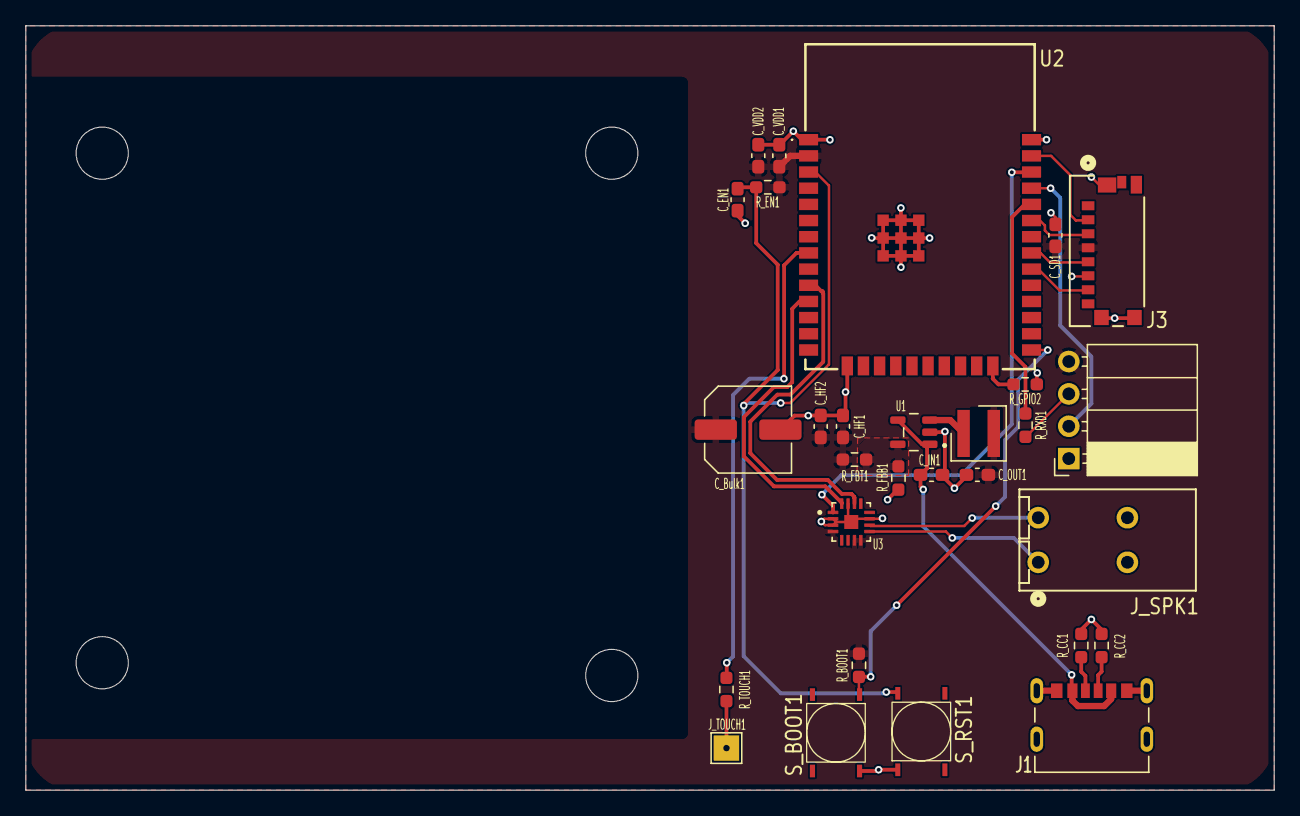
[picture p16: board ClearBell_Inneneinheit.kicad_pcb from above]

Board: 2 copper layers, 98.0 x 60.0 mm, 30 parts (0 on the bottom side), 24 nets.

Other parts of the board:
LS1: Visatone K50 SQ

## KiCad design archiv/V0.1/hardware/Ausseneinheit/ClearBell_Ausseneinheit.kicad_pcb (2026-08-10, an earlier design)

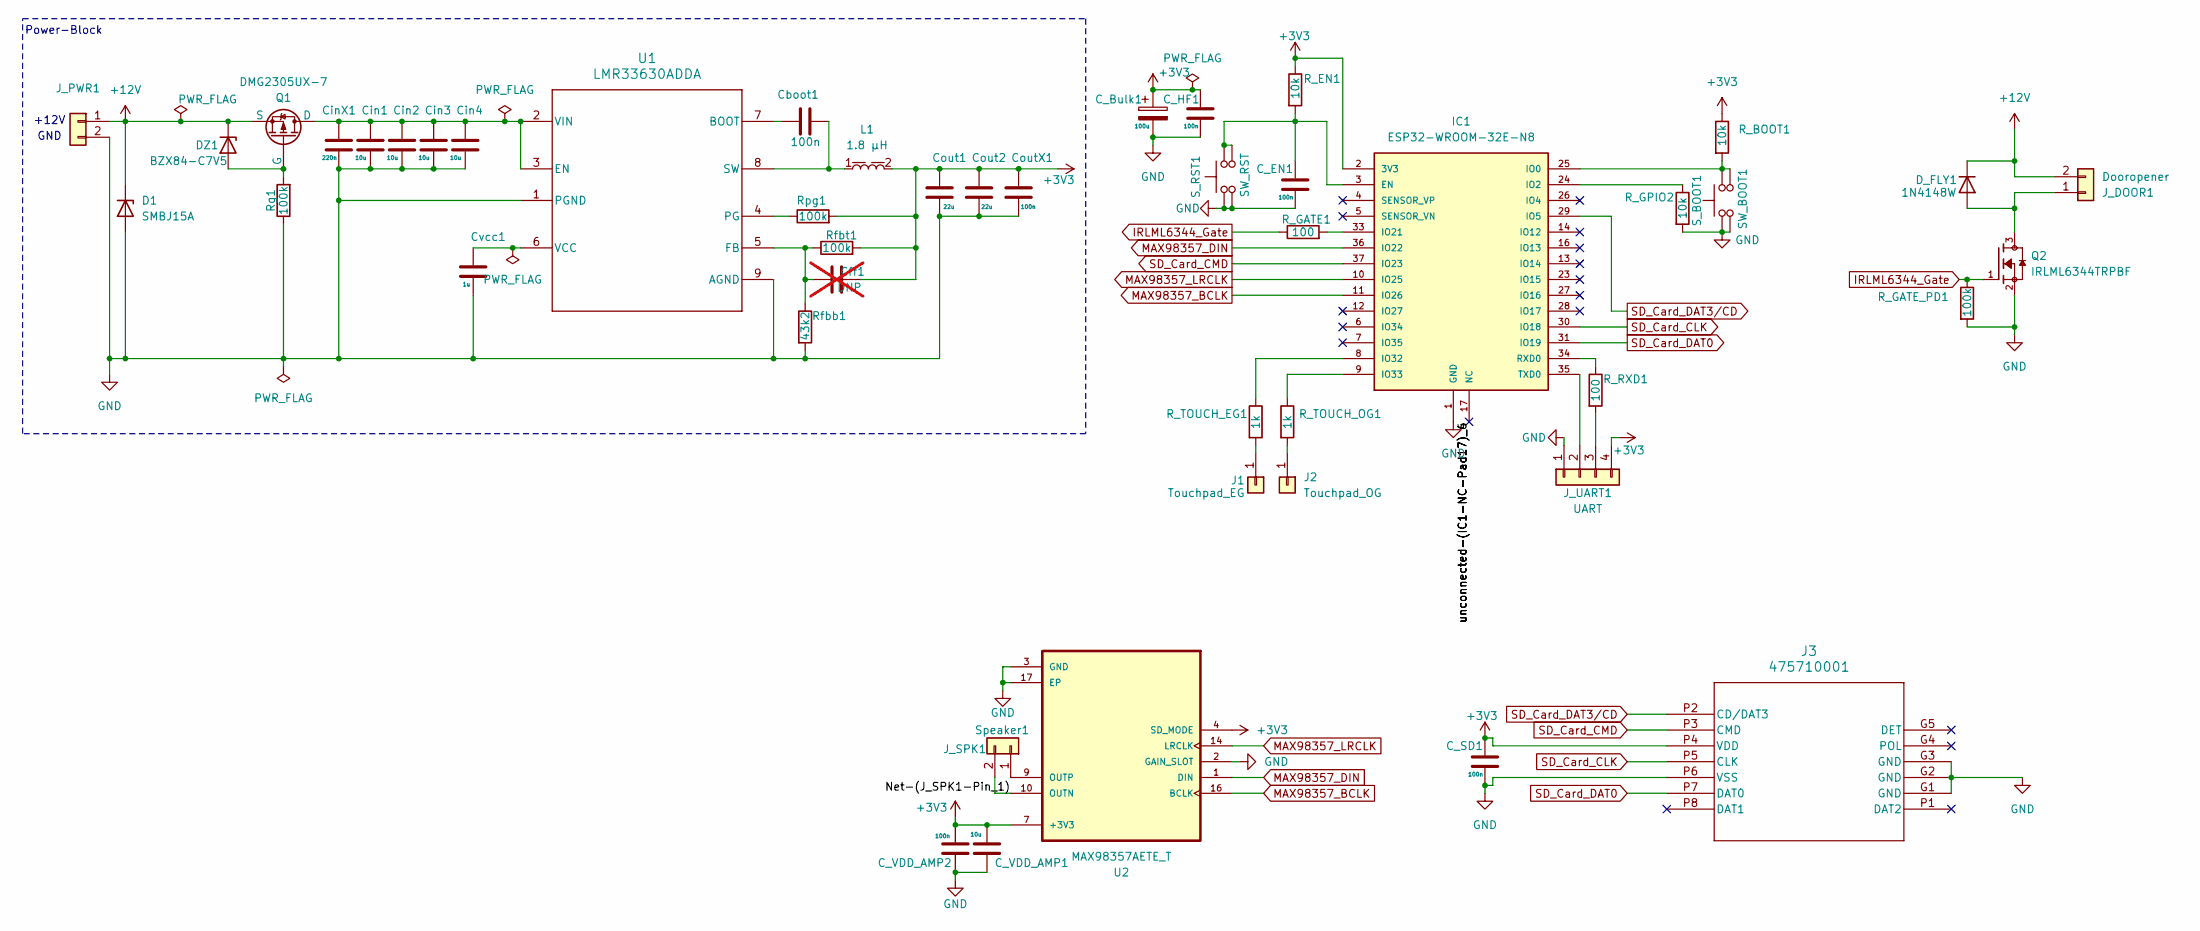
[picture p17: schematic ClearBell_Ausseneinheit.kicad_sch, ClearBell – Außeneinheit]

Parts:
C_Bulk1: 100u; C_Elec_6.3x5.4
C_EN1: 100n; C_0603_1608Metric_Pad1.08x0.95mm_HandSolder
C_HF1: 100n; C_0603_1608Metric_Pad1.08x0.95mm_HandSolder
C_SD1: 100n; C_0603_1608Metric_Pad1.08x0.95mm_HandSolder
C_VDD_AMP1: 10u; C_0603_1608Metric_Pad1.08x0.95mm_HandSolder
C_VDD_AMP2: 100n; C_0603_1608Metric_Pad1.08x0.95mm_HandSolder
Cboot1: 100n; C_0603_1608Metric_Pad1.08x0.95mm_HandSolder
Cff1: DNP; C_0603_1608Metric_Pad1.08x0.95mm_HandSolder; not fitted
Cin1, Cin2, Cin3, Cin4: 10u; C_0805_2012Metric_Pad1.18x1.45mm_HandSolder
CinX1: 220n; C_0603_1608Metric_Pad1.08x0.95mm_HandSolder
Cout1, Cout2: 22u; C_0603_1608Metric_Pad1.08x0.95mm_HandSolder
CoutX1: 100n; C_0603_1608Metric_Pad1.08x0.95mm_HandSolder
Cvcc1: 1u; C_0603_1608Metric_Pad1.08x0.95mm_HandSolder
D1: SMBJ15A; D_SMB-SMC_Universal_Handsoldering; MANUFACTURER_PART_NUMBER SMBJ15A-E3/52; Digi-Key_Part_Number SMBJ15A-E3/52GICT-ND
DZ1: BZX84-C7V5; SOT-23; MANUFACTURER_PART_NUMBER BZX84C7V5; Digi-Key_Part_Number 4878-BZX84C7V5CT-ND
D_FLY1: 1N4148W; SOT-23; MANUFACTURER_PART_NUMBER 1N4148W-E3-18; Digi-Key_Part_Number 1N4148W-E3-18CT-ND
IC1: ESP32-WROOM-32E-N8; ESP32WROOM32EN8; MOUSER_PART_NUMBER 356-ESP32WRM32E164PH
J1: Touchpad_EG; TestPoint_Pad_2.0x2.0mm
J2: Touchpad_OG; TestPoint_Pad_2.0x2.0mm
J3: 475710001; MOLEX MICRO SD CARD_475710001; MANUFACTURER_PART_NUMBER 0475710001; Digi-Key_Part_Number WM9731CT-ND
J_DOOR1: Dooropener; Wago_2086-1202
J_PWR1: WAGO_2086-1202; Wago_2086-1202
J_SPK1: Speaker1; Wago_2086-1202
J_UART1: UART; PinSocket_1x04_P2.54mm_Horizontal
L1: 4020HT_74438356018HT; L_Wurth_WE-MAPI-4020HT; Part Number 74438356018HT; Digi-Key_Part_Number 732-74438356018HTCT-ND
Q1: DMG2305UX-7; SOT-23; MANUFACTURER_PART_NUMBER PJA3415A_R1_00001; Digi-Key_Part_Number 3757-PJA3415A_R1_00001CT-ND
Q2: IRLML6344TRPBF; TRANS_IRLML6344TRPBF; PARTREV December 19, 2014
R_BOOT1: 10k; R_0603_1608Metric_Pad0.98x0.95mm_HandSolder
R_EN1: 10k; R_0603_1608Metric_Pad0.98x0.95mm_HandSolder
R_GATE1: 100; R_0603_1608Metric_Pad0.98x0.95mm_HandSolder
R_GATE_PD1: 100k; R_0603_1608Metric_Pad0.98x0.95mm_HandSolder
R_GPIO2: 10k; R_0603_1608Metric_Pad0.98x0.95mm_HandSolder
R_RXD1: 100; R_0603_1608Metric_Pad0.98x0.95mm_HandSolder
R_TOUCH_EG1: 1k; R_0603_1608Metric_Pad0.98x0.95mm_HandSolder
R_TOUCH_OG1: 1k; R_0603_1608Metric_Pad0.98x0.95mm_HandSolder
Rfbb1: 43k2; R_0603_1608Metric_Pad0.98x0.95mm_HandSolder
Rfbt1: 100k; R_0603_1608Metric_Pad0.98x0.95mm_HandSolder
Rg1: 100k; R_0603_1608Metric_Pad0.98x0.95mm_HandSolder
Rpg1: 100k; R_0603_1608Metric_Pad0.98x0.95mm_HandSolder
S_BOOT1: SW_BOOT1; CK_PTS526; MANUFACTURER_PART_NUMBER PTS526SK15SMTR2 LFS; Digi-Key_Part_Number CKN12221-1-ND
S_RST1: SW_RST; CK_PTS526; MANUFACTURER_PART_NUMBER PTS526SK15SMTR2 LFS; Digi-Key_Part_Number CKN12221-1-ND
U1: LMR33630ADDA; DDA0008J; MANUFACTURER_PART_NUMBER LMR33630ADDA
U2: MAX98357AETE_T; QFN50P300X300X80-17N; MANUFACTURER_PART_NUMBER MAX98357AETE+T; Digi-Key_Part_Number MAX98357AETE+TCT-ND

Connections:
+3V3: C_Bulk1.1, C_HF1.1, C_SD1.1, C_VDD_AMP1.2, C_VDD_AMP2.2, Cff1.2, Cout1.1, Cout2.1, CoutX1.1, IC1.2 (3V3), J3.P4 (VDD), J_UART1.4, L1.2, R_BOOT1.1, R_EN1.1, Rfbt1.2, Rpg1.2, U2.4 (SD_MODE), U2.7 (+3V3), U2.8 (+3V3)
+12V: D1.1 (K), DZ1.1 (K), D_FLY1.1 (K), J_DOOR1.2, J_DOOR1.4, J_PWR1.1 (Pin_1_1), J_PWR1.3 (Pin_2_2), Q1.3 (S)
/Net-(J_SPK1-Pin_1): J_SPK1.2, J_SPK1.4, U2.10 (OUTN)
GND: C_Bulk1.2, C_EN1.2, C_HF1.2, C_SD1.2, C_VDD_AMP1.1, C_VDD_AMP2.1, Cin1.2, Cin2.2, Cin3.2, Cin4.2, CinX1.2, Cout1.2, Cout2.2, CoutX1.2, Cvcc1.2, D1.2 (A), IC1.1 (GND), IC1.15 (GND), IC1.38 (GND), IC1.39 (GND), IC1.40 (GND), IC1.41 (GND), IC1.42 (GND), IC1.43 (GND), IC1.44 (GND), IC1.45 (GND), IC1.46 (GND), IC1.47 (GND), J3.G1 (GND), J3.G2 (GND), J3.G3 (GND), J3.P6 (VSS), J_PWR1.2, J_PWR1.4, J_UART1.1, Q2.2, R_GATE_PD1.2, R_GPIO2.2, Rfbb1.2, Rg1.1, S_BOOT1.1, S_BOOT1.2, S_RST1.1, S_RST1.2, U1.1 (PGND), U1.9 (AGND), U1.V, U2.2 (GAIN_SLOT), U2.3 (GND), U2.11 (GND), U2.15 (GND), U2.17 (EP)
IRLML6344_Gate: Q2.1, R_GATE1.1, R_GATE_PD1.1
MAX98357_BCLK: IC1.11 (IO26), U2.16 (BCLK)
MAX98357_DIN: IC1.36 (IO22), U2.1 (DIN)
MAX98357_LRCLK: IC1.10 (IO25), U2.14 (LRCLK)
unnamed: DZ1.2 (A), Q1.2 (G), Rg1.2
unnamed: D_FLY1.2 (A), J_DOOR1.1 (Pin_1_1), J_DOOR1.3 (Pin_2_2), Q2.3
unnamed: C_EN1.1, IC1.3 (EN), R_EN1.2, S_RST1.3, S_RST1.4
unnamed: IC1.25 (IO0), R_BOOT1.2, S_BOOT1.3, S_BOOT1.4
unnamed: IC1.24 (IO2), R_GPIO2.1
unnamed: IC1.33 (IO21), R_GATE1.2
unnamed: IC1.8 (IO32), R_TOUCH_EG1.1
unnamed: IC1.9 (IO33), R_TOUCH_OG1.1
unnamed: IC1.34 (RXD0), R_RXD1.1
unnamed: IC1.35 (TXD0), J_UART1.2
unnamed: J1.1 (Pin_1_1), R_TOUCH_EG1.2
unnamed: J2.1 (Pin_1_1), R_TOUCH_OG1.2
unnamed: J_SPK1.1 (Pin_1_1), J_SPK1.3 (Pin_2_2), U2.9 (OUTP)
unnamed: J_UART1.3, R_RXD1.2
unnamed: Cin1.1, Cin2.1, Cin3.1, Cin4.1, CinX1.1, Q1.1 (D), U1.2 (VIN), U1.3 (EN)
unnamed: Cboot1.1, U1.7 (BOOT)
unnamed: Cff1.1, Rfbb1.1, Rfbt1.1, U1.5 (FB)
unnamed: Rpg1.1, U1.4 (PG)
unnamed: Cboot1.2, L1.1, U1.8 (SW)
unnamed: Cvcc1.1, U1.6 (VCC)
SD_Card_CLK: IC1.30 (IO18), J3.P5 (CLK)
SD_Card_CMD: IC1.37 (IO23), J3.P3 (CMD)
SD_Card_DAT0: IC1.31 (IO19), J3.P7 (DAT0)
SD_Card_DAT3/CD: IC1.29 (IO5), J3.P2 (CD/DAT3)

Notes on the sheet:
Power-Block
GND
+12V

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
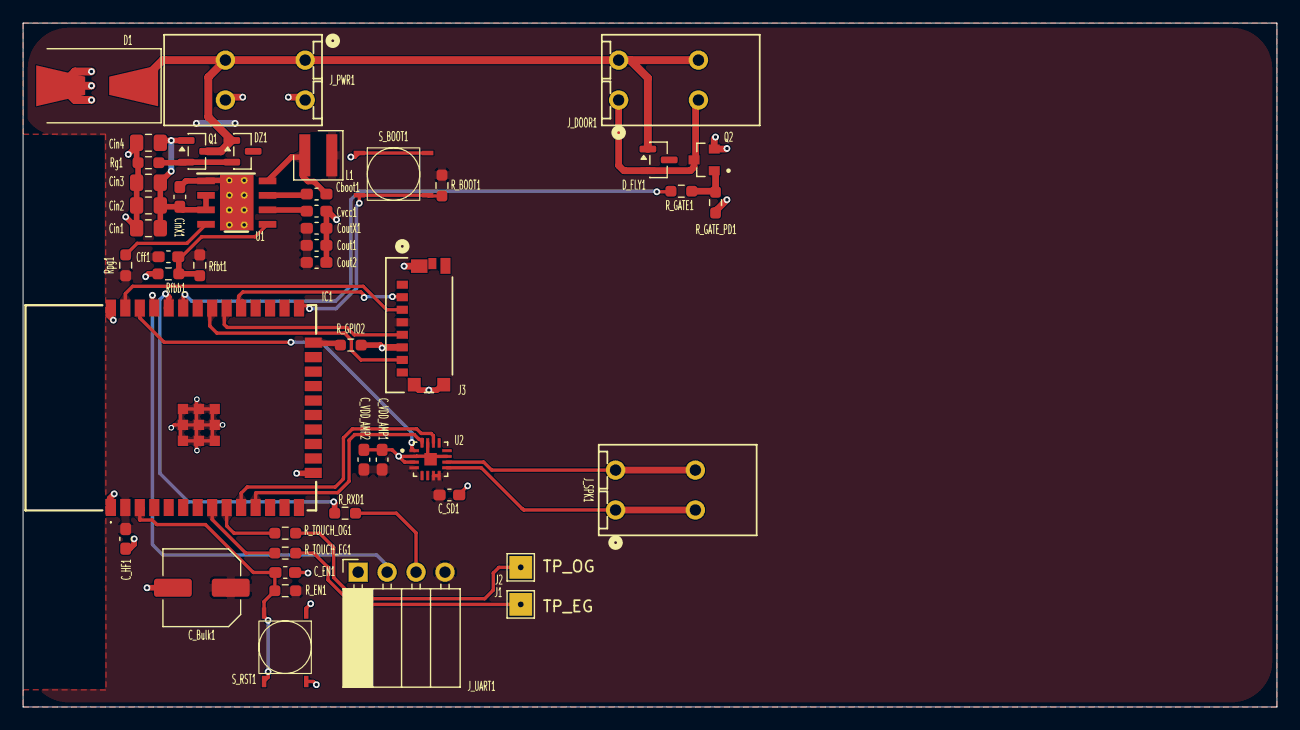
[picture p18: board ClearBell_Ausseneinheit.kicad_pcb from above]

Board: 2 copper layers, 110.0 x 60.0 mm, 47 parts (0 on the bottom side), 32 nets.

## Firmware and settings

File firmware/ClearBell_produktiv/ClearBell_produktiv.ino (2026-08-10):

// ============================================================
// ClearBell – Produktivfirmware
//
// Transport WLAN + UDP. Enthalten & getestet:
//   - nicht-blockierendes WLAN (läuft auch ohne Netz weiter)
//   - UDP-Nachrichten (einheitliches 14-Byte-Paket) + Retry/Quittung
//   - Klingel- und Türbefehl-Fluss mit Erfolgs-/Fehlerton
//   - Türbefehl authentifiziert (HMAC-SHA256 + rollierender Zähler in
//     NVS gegen Replay; je Einheit eigener Schlüssel)
//   - Touch-Taster als Auslöser (Klingel bzw. Türbefehl)
//   - Audio: nicht-blockierender WAV-Player von SD über I2S
//   - Lautstärke per BOOT-Taster (GPIO0), in NVS gespeichert
//   - ntfy-Push (nur EG) asynchron über FreeRTOS-Task
//
// NOCH STUB:
//   - oeffneTuer(): GPIO-Puls des Türöffners (Hardware noch nicht vorhanden)
//
// Serial-Testbefehle (115200), zusätzlich zu den Touch-Tastern:
//   AUSSEN:  'e' = Klingel EG,  'o' = Klingel OG
//   INNEN:   't' = Türbefehl,   'x' = Türbefehl mit falschem Schlüssel
// ============================================================

// === EINHEIT WÄHLEN: genau eine Zeile aktiv lassen ===
#define CB_UNIT_AUSSEN
//#define CB_UNIT_INNEN_EG
//#define CB_UNIT_INNEN_OG

#include <WiFi.h>
#include <WiFiUdp.h>
#include <WiFiClientSecure.h>
#include <HTTPClient.h>
#include <Preferences.h>
#include <string.h>
#include <stddef.h>
#include <SPI.h>
#include <SD.h>
#include <ESP_I2S.h>
#include "mbedtls/md.h"
#include "esp_random.h"
#include "config.h"

// ── eigene Identität aus der gewählten Einheit ableiten ─────────────────────
#if defined(CB_UNIT_AUSSEN)
  #define CB_MY_ID   CB_ID_AUSSEN
  static const char* CB_MY_NAME = "AUSSEN";
#elif defined(CB_UNIT_INNEN_EG)
  #define CB_MY_ID   CB_ID_EG
  #define CB_MEIN_KLINGELSOUND CB_SND_KLINGEL_EG
  #define CB_MEIN_KEY          CB_KEY_EG
  static const char* CB_MY_NAME = "INNEN_EG";
#elif defined(CB_UNIT_INNEN_OG)
  #define CB_MY_ID   CB_ID_OG
  #define CB_MEIN_KLINGELSOUND CB_SND_KLINGEL_OG
  #define CB_MEIN_KEY          CB_KEY_OG
  static const char* CB_MY_NAME = "INNEN_OG";
#endif

// ── Nachrichtentypen ─────────────────────────────────────────────────────────
enum CbTyp : uint8_t {
  CB_PING = 1, CB_PONG = 2,
  CB_KLINGEL = 3, CB_KLINGEL_QUITT = 4,
  CB_TUER_AUF = 5, CB_TUER_QUITT = 6
};

// Einheitliches Paket (14 Byte). Türbefehl nutzt tag (HMAC über die ersten
// 6 Byte: typ|senderId|seq). Bei allen anderen Typen ist tag = 0.
typedef struct __attribute__((packed)) {
  uint8_t  typ;
  uint8_t  senderId;
  uint32_t seq;                    // Türbefehl: rollierender Zähler
  uint8_t  tag[CB_HMAC_TAG_LEN];   // Türbefehl: HMAC, sonst 0
} CbNachricht;

// Anzahl der HMAC-relevanten Bytes am Paketanfang (typ|senderId|seq)
#define CB_HMAC_INPUT_LEN  (offsetof(CbNachricht, tag))

// ── Sende-/Retry-Verwaltung (mehrere gleichzeitig, z.B. Klingel EG+OG) ──────
#define CB_MAX_SENDUNGEN 3
struct CbSendung {
  bool      aktiv;
  uint8_t   typ;
  uint8_t   quittTyp;
  uint32_t  seq;
  uint8_t   tag[CB_HMAC_TAG_LEN];
  IPAddress ziel;
  uint32_t  sendeZeit;
  uint8_t   wiederholungen;
};
CbSendung sendungen[CB_MAX_SENDUNGEN];

// Touch-Pad-Zustand (Definition hier oben, damit Arduinos automatische
// Funktions-Prototypen den Typ kennen – sonst "TouchPad not declared").
struct TouchPad {
  uint8_t  pin;
  bool     gedrueckt;
  uint8_t  zaehler;
  uint32_t letzteMessung;
};

// WAV-Header-Infos (Definition oben, wegen Auto-Prototypen)
struct WavInfo { uint32_t sampleRate; uint16_t kanaele; uint16_t bits; uint32_t datenLen; };

WiFiUDP     udp;
Preferences prefs;                // NVS
IPAddress   ipAussen, ipEG, ipOG;
uint32_t    seqZaehler = 0;       // nur für Klingel/Ping (Türbefehl: NVS-Zähler)

// Audio (Etappe E4)
I2SClass  i2s;
File      audioDatei;
bool      audioAktiv   = false;
bool      sdBereit     = false;
uint32_t  audioRest    = 0;       // verbleibende PCM-Bytes
uint16_t  audioKanaele = 1;
uint32_t  i2sRate      = 0;       // aktuell konfigurierte I2S-Rate (0 = aus)
uint8_t   audioVolume  = CB_AUDIO_VOLUME;  // Laufzeit-Lautstärke (aus NVS, per BOOT-Taster)

// ── Krypto-Helfer (beide Einheiten) ─────────────────────────────────────────
static bool hmacSha256(const uint8_t* key, size_t keyLen,
                       const uint8_t* data, size_t dataLen, uint8_t out[32]) {
  const mbedtls_md_info_t* info = mbedtls_md_info_from_type(MBEDTLS_MD_SHA256);
  if (info == nullptr) return false;
  return mbedtls_md_hmac(info, key, keyLen, data, dataLen, out) == 0;
}

// Konstante-Zeit-Vergleich (kein early-return -> keine Timing-Lecks)
static bool gleichKonstanteZeit(const uint8_t* a, const uint8_t* b, size_t n) {
  uint8_t d = 0;
  for (size_t i = 0; i < n; i++) d |= (uint8_t)(a[i] ^ b[i]);
  return d == 0;
}

// Türbefehl-Tag = HMAC-SHA256(key, typ|senderId|seq)[0..CB_HMAC_TAG_LEN-1]
static void berechneTuerTag(const uint8_t* key, const CbNachricht& n,
                            uint8_t tag[CB_HMAC_TAG_LEN]) {
  uint8_t voll[32];
  hmacSha256(key, 32, (const uint8_t*)&n, CB_HMAC_INPUT_LEN, voll);
  memcpy(tag, voll, CB_HMAC_TAG_LEN);
}

#if defined(CB_UNIT_AUSSEN)
// Schlüssel des jeweiligen Senders (Außeneinheit kennt beide)
static const uint8_t* keyFuerSender(uint8_t senderId) {
  if (senderId == CB_ID_EG) return CB_KEY_EG;
  if (senderId == CB_ID_OG) return CB_KEY_OG;
  return nullptr;
}
static const char* nvsKeyFuer(uint8_t senderId) {
  return (senderId == CB_ID_EG) ? "lastEG" : "lastOG";
}
#else
uint32_t letzteKlingelSeq = 0;
#endif

// ── Hilfen ───────────────────────────────────────────────────────────────────
static bool wlanOk() { return WiFi.status() == WL_CONNECTED; }

// ── Audio: nicht-blockierender WAV-Player (Etappe E4) ───────────────────────
static bool audioLeseU16(File& f, uint16_t& v) {
  uint8_t b[2]; if (f.read(b, 2) != 2) return false; v = b[0] | (b[1] << 8); return true;
}
static bool audioLeseU32(File& f, uint32_t& v) {
  uint8_t b[4]; if (f.read(b, 4) != 4) return false;
  v = (uint32_t)b[0] | ((uint32_t)b[1] << 8) | ((uint32_t)b[2] << 16) | ((uint32_t)b[3] << 24);
  return true;
}
// Parst RIFF/WAVE, sucht fmt+data. Nach Erfolg steht f auf den PCM-Daten.
static bool audioParseWav(File& f, WavInfo& wi) {
  char id[4]; uint32_t dummy;
  if (f.read((uint8_t*)id, 4) != 4 || memcmp(id, "RIFF", 4)) return false;
  if (!audioLeseU32(f, dummy)) return false;
  if (f.read((uint8_t*)id, 4) != 4 || memcmp(id, "WAVE", 4)) return false;
  bool fmtOk = false;
  while (true) {
    if (f.read((uint8_t*)id, 4) != 4) return false;
    uint32_t len; if (!audioLeseU32(f, len)) return false;
    if (!memcmp(id, "fmt ", 4)) {
      uint16_t af, ba; uint32_t br;
      audioLeseU16(f, af); audioLeseU16(f, wi.kanaele); audioLeseU32(f, wi.sampleRate);
      audioLeseU32(f, br); audioLeseU16(f, ba); audioLeseU16(f, wi.bits);
      if (len > 16) f.seek(f.position() + (len - 16));
      fmtOk = true;
    } else if (!memcmp(id, "data", 4)) {
      wi.datenLen = len; return fmtOk;
    } else {
      f.seek(f.position() + len + (len & 1));
    }
  }
}
// I2S nur (um)konfigurieren, wenn sich die Rate ändert.
static void audioI2SRate(uint32_t rate) {
  if (i2sRate == rate) return;
  if (i2sRate != 0) i2s.end();
  i2sRate = 0;
  if (i2s.begin(I2S_MODE_STD, rate, I2S_DATA_BIT_WIDTH_16BIT, I2S_SLOT_MODE_STEREO))
    i2sRate = rate;
}

// Startet die Wiedergabe – kehrt SOFORT zurück (Streaming in audioPflege()).
void spieleSound(const char* datei) {
  if (!sdBereit) { Serial.printf("   [Audio] keine SD -> %s stumm\n", datei); return; }
  if (audioAktiv) { audioDatei.close(); audioAktiv = false; }   // laufenden Sound ersetzen
  audioDatei = SD.open(datei);
  if (!audioDatei) { Serial.printf("   [Audio] %s nicht gefunden\n", datei); return; }
  WavInfo wi;
  if (!audioParseWav(audioDatei, wi) || wi.bits != 16) {
    Serial.printf("   [Audio] %s kein 16-bit-WAV\n", datei); audioDatei.close(); return;
  }
  audioI2SRate(wi.sampleRate);
  if (i2sRate == 0) { Serial.println("   [Audio] I2S-Start fehlgeschlagen"); audioDatei.close(); return; }
  audioRest    = wi.datenLen;
  audioKanaele = wi.kanaele;
  audioAktiv   = true;
  Serial.printf("   [Audio] spiele %s (%lu Hz, %u Kanal)\n",
                datei, (unsigned long)wi.sampleRate, wi.kanaele);
}

// Füttert pro loop()-Durchlauf EINEN kleinen Block an I2S (nicht-blockierend).
void audioPflege() {
  if (!audioAktiv) return;
  uint8_t buf[512];
  uint32_t chunk = audioRest < sizeof(buf) ? audioRest : sizeof(buf);
  int gelesen = audioDatei.read(buf, chunk);
  if (gelesen <= 0) { audioDatei.close(); audioAktiv = false; return; }
  audioRest -= gelesen;
  int16_t* s = (int16_t*)buf;
  size_t anzahl = gelesen / 2;
  if (audioKanaele == 1) {
    int16_t stereo[512];                    // buf=512B -> max 256 Samples -> 512 int16
    for (size_t i = 0; i < anzahl; i++) {
      int16_t v = (int16_t)((int32_t)s[i] * audioVolume / 100);  // Lautstärke
      stereo[2*i] = v; stereo[2*i+1] = v;
    }
    i2s.write((uint8_t*)stereo, anzahl * 4); // mono -> L+R
  } else {
    for (size_t i = 0; i < anzahl; i++)
      s[i] = (int16_t)((int32_t)s[i] * audioVolume / 100);      // Lautstärke
    i2s.write(buf, gelesen);                 // bereits stereo-interleaved
  }
  if (audioRest == 0) { audioDatei.close(); audioAktiv = false; }
}

// ── Lautstärke per BOOT-Taster (GPIO0) durchschalten ────────────────────────
const uint8_t VOL_STUFEN[] = {15, 30, 50, 75, 100};
uint32_t volTasteZeit   = 0;
bool     volTasteVorher = false;

void naechsteVolumeStufe() {
  uint8_t next = VOL_STUFEN[0];                       // Standard: kleinste (Wrap)
  for (uint8_t v : VOL_STUFEN) { if (v > audioVolume) { next = v; break; } }
  audioVolume = next;
  prefs.putUInt("vol", audioVolume);                  // dauerhaft in NVS merken
  Serial.printf("Lautstärke -> %u %%\n", audioVolume);
  spieleSound(CB_SND_OK);                             // Feedback im neuen Pegel
}

// Entprellter Flankenerkenner (BOOT-Taster zieht GPIO0 auf LOW).
void volTasterPflege() {
  bool gedrueckt = (digitalRead(CB_VOL_TASTER_GPIO) == LOW);
  uint32_t jetzt = millis();
  if (gedrueckt && !volTasteVorher && (jetzt - volTasteZeit > 250)) {
    volTasteZeit = jetzt;
    naechsteVolumeStufe();
  }
  volTasteVorher = gedrueckt;
}

void erfolgTon() { Serial.println(">> Erfolg  -> Bestätigungston");  spieleSound(CB_SND_OK); }
void fehlerTon() { Serial.println(">> Fehler  -> Fehlerton");        spieleSound(CB_SND_FEHLER); }

#if defined(CB_UNIT_AUSSEN)
void oeffneTuer() {
  // Etappe: GPIO-Puls nicht-blockierend (CB_TUER_GPIO, CB_TUER_PULS_MS).
  Serial.printf("   [STUB Tür] Türöffner-Puls %d ms\n", CB_TUER_PULS_MS);
}

// ── Fern-Türöffnen: Einmal-Token (ring-gebunden) ────────────────────────────
// Bei jedem EG-Klingeln wird ein 128-bit-Zufallstoken erzeugt und kurz
// gespeichert. Das Token selbst ist die Capability (unfälschbar); die
// Außeneinheit ist Aussteller UND Prüfer. Einmalig + zeitlich begrenzt.
#define CB_MAX_TOKENS 4
struct TuerToken { char token[33]; uint32_t ausgestellt; bool aktiv; };
TuerToken tuerTokens[CB_MAX_TOKENS];

// Erzeugt ein neues Token (32 Hex-Zeichen), speichert es, liefert es in out[33].
void neuesTuerToken(char out[33]) {
  for (int i = 0; i < 16; i++) sprintf(out + i * 2, "%02x", (uint8_t)(esp_random() & 0xFF));
  out[32] = '\0';
  int slot = 0; uint32_t aeltest = UINT32_MAX;      // freier oder ältester Slot
  for (int i = 0; i < CB_MAX_TOKENS; i++) {
    if (!tuerTokens[i].aktiv) { slot = i; break; }
    if (tuerTokens[i].ausgestellt < aeltest) { aeltest = tuerTokens[i].ausgestellt; slot = i; }
  }
  strcpy(tuerTokens[slot].token, out);
  tuerTokens[slot].ausgestellt = millis();
  tuerTokens[slot].aktiv = true;
}

// ── ntfy-Push (asynchron via FreeRTOS-Task, damit loop() nicht blockiert) ───
volatile bool pushAngefordert = false;
char          pushText[80];
char          pushToken[33];      // Token für den "Tür öffnen"-Button ("" = kein Button)

void pushTask(void*) {
  for (;;) {
    if (pushAngefordert) {
      pushAngefordert = false;
      if (wlanOk()) {
        WiFiClientSecure client;
        client.setInsecure();                    // ntfy.sh: ohne Zertifikatsprüfung
        HTTPClient http;
        String url = String(CB_NTFY_SERVER) + "/" + CB_NTFY_TOPIC_EG;
        if (http.begin(client, url)) {
          http.addHeader("Title", CB_NTFY_TITLE);
          http.addHeader("Priority", CB_NTFY_PRIORITY);
          if (pushToken[0]) {
            // "Tür öffnen"-Button: postet das Einmal-Token ans Kommando-Topic
            String actions = String("http, ") + CB_TUER_BTN_LABEL + ", " +
                             CB_NTFY_SERVER + "/" + CB_NTFY_CMD_TOPIC +
                             ", method=POST, body=" + pushToken + ", clear=true";
            http.addHeader("Actions", actions);
          }
          int code = http.POST((uint8_t*)pushText, strlen(pushText));
          Serial.printf("   [Push] ntfy HTTP %d\n", code);
          http.end();
        } else {
          Serial.println("   [Push] Verbindung fehlgeschlagen");
        }
      } else {
        Serial.println("   [Push] kein WLAN -> übersprungen");
      }
    }
    vTaskDelay(pdMS_TO_TICKS(50));
  }
}

// Fordert einen Push an – kehrt SOFORT zurück (Task erledigt den HTTP-POST).
// token==nullptr -> ohne Button; sonst mit "Tür öffnen"-Aktion.
void sendePush(const char* text, const char* token) {
  strncpy(pushText, text, sizeof(pushText) - 1);
  pushText[sizeof(pushText) - 1] = '\0';
  if (token) { strncpy(pushToken, token, sizeof(pushToken) - 1); pushToken[sizeof(pushToken) - 1] = '\0'; }
  else         pushToken[0] = '\0';
  pushAngefordert = true;
}

// EG-Klingel-Push: erzeugt ein frisches Einmal-Token und schickt die Push
// mit "Tür öffnen"-Button.
void klingelPushEG() {
  char tok[33];
  neuesTuerToken(tok);
  sendePush(CB_NTFY_TEXT, tok);
}

// ── Fern-Türöffnen: Kommando-Empfang (SSE/raw in eigenem Task) ──────────────
// Prüft eine empfangene Zeile gegen die Token-Tabelle: einmalig (sofort
// verbraucht) + zeitlich begrenzt. Kein Treffer -> stillschweigend ignoriert
// (deckt Chunk-Größen/Keepalives/Fremdmüll ab).
void verarbeiteKommando(const String& zeile) {
  for (int i = 0; i < CB_MAX_TOKENS; i++) {
    if (!tuerTokens[i].aktiv) continue;
    if (zeile == tuerTokens[i].token) {
      tuerTokens[i].aktiv = false;                       // one-time: sofort verbrauchen
      if (millis() - tuerTokens[i].ausgestellt <= CB_TUER_TOKEN_TTL_MS) {
        Serial.println("   [Cmd] gültiges Token -> Tür öffnen");
        oeffneTuer();
      } else {
        Serial.println("   [Cmd] Token abgelaufen -> verworfen");
      }
      return;
    }
  }
}

// Hält eine Streaming-Verbindung zum Kommando-Topic offen und reicht jede
// empfangene Zeile an verarbeiteKommando(). Reconnect bei Abriss.
void cmdTask(void*) {
  for (;;) {
    if (!wlanOk()) { vTaskDelay(pdMS_TO_TICKS(1000)); continue; }
    WiFiClientSecure client;
    client.setInsecure();
    if (!client.connect("ntfy.sh", 443)) {
      Serial.println("   [Cmd] Verbindung zu ntfy fehlgeschlagen");
      vTaskDelay(pdMS_TO_TICKS(3000));
      continue;
    }
    client.printf("GET /%s/raw HTTP/1.1\r\nHost: ntfy.sh\r\nConnection: keep-alive\r\n\r\n",
                  CB_NTFY_CMD_TOPIC);
    Serial.println("   [Cmd] lausche auf Kommando-Topic");

    bool     headerFertig = false;
    String   zeile;
    uint32_t letzteDaten = millis();
    while (client.connected()) {
      while (client.available()) {
        char c = client.read();
        letzteDaten = millis();
        if (c == '\r') continue;
        if (c == '\n') {
          if (!headerFertig) { if (zeile.length() == 0) headerFertig = true; }  // Leerzeile = Header-Ende
          else if (zeile.length() > 0) verarbeiteKommando(zeile);
          zeile = "";
        } else {
          zeile += c;
          if (zeile.length() > 200) zeile = "";          // Schutz gegen Müll
        }
      }
      if (millis() - letzteDaten > 60000) break;          // 60 s still -> neu verbinden
      vTaskDelay(pdMS_TO_TICKS(20));
    }
    client.stop();
    Serial.println("   [Cmd] Verbindung getrennt -> Neuaufbau");
    vTaskDelay(pdMS_TO_TICKS(1000));
  }
}
#endif

void sendePaket(uint8_t typ, uint32_t seq, const uint8_t* tag, IPAddress ziel) {
  CbNachricht n;
  memset(&n, 0, sizeof(n));
  n.typ = typ;
  n.senderId = CB_MY_ID;
  n.seq = seq;
  if (tag) memcpy(n.tag, tag, CB_HMAC_TAG_LEN);
  udp.beginPacket(ziel, CB_UDP_PORT);
  udp.write((const uint8_t*)&n, sizeof(n));
  udp.endPacket();
}

// Startet eine quittungspflichtige Sendung. Ohne WLAN sofort Fehler.
void starteSendung(uint8_t typ, uint8_t quittTyp, uint32_t seq,
                   const uint8_t* tag, IPAddress ziel) {
  if (!wlanOk()) {
    Serial.println("WLAN offline -> Sendung sofort als Fehler gewertet");
    fehlerTon();
    return;
  }
  CbSendung* s = nullptr;
  for (auto& e : sendungen) if (!e.aktiv) { s = &e; break; }
  if (!s) { Serial.println("Keine freie Sendung -> Fehler"); fehlerTon(); return; }

  s->aktiv = true;
  s->typ = typ;
  s->quittTyp = quittTyp;
  s->seq = seq;
  memset(s->tag, 0, CB_HMAC_TAG_LEN);
  if (tag) memcpy(s->tag, tag, CB_HMAC_TAG_LEN);
  s->ziel = ziel;
  s->wiederholungen = 0;
  s->sendeZeit = millis();
  sendePaket(typ, seq, tag, ziel);
  Serial.printf("Sendung typ=%u seq=%lu -> %s\n",
                typ, (unsigned long)seq, ziel.toString().c_str());
}

#if !defined(CB_UNIT_AUSSEN)
// Türbefehl bauen: NVS-Zähler hochzählen+persistieren, HMAC berechnen, senden.
// falscherSchluessel=true nur für den Sicherheits-Test ('x'): die Außeneinheit
// muss den Befehl dann wegen HMAC-Fehler verwerfen.
void sendeTuerbefehl(bool falscherSchluessel = false) {
  uint32_t counter = prefs.getUInt("tuerCtr", 0) + 1;
  prefs.putUInt("tuerCtr", counter);   // VOR dem Senden persistieren -> nie doppelt

  CbNachricht tmp;
  memset(&tmp, 0, sizeof(tmp));
  tmp.typ = CB_TUER_AUF;
  tmp.senderId = CB_MY_ID;
  tmp.seq = counter;

  uint8_t key[32];
  memcpy(key, CB_MEIN_KEY, 32);
  if (falscherSchluessel) {
    key[0] ^= 0xFF;   // Schlüssel verfälschen -> HMAC passt nicht zur Außeneinheit
    Serial.println("!! TEST: Türbefehl mit ABSICHTLICH falschem Schlüssel");
  }
  uint8_t tag[CB_HMAC_TAG_LEN];
  berechneTuerTag(key, tmp, tag);

  Serial.printf("Türbefehl counter=%lu (NVS), HMAC berechnet\n", (unsigned long)counter);
  starteSendung(CB_TUER_AUF, CB_TUER_QUITT, counter, tag, ipAussen);
}
#endif

void pruefeSendungen() {
  uint32_t jetzt = millis();
  for (auto& s : sendungen) {
    if (!s.aktiv) continue;
    if (jetzt - s.sendeZeit < CB_QUITT_TIMEOUT_MS) continue;
    if (s.wiederholungen < CB_MAX_WIEDERHOLUNGEN) {
      s.wiederholungen++;
      sendePaket(s.typ, s.seq, s.tag, s.ziel);   // gleicher tag bei Wiederholung
      s.sendeZeit = jetzt;
    } else {
      s.aktiv = false;
      Serial.printf("seq=%lu endgültig verloren\n", (unsigned long)s.seq);
      fehlerTon();
    }
  }
}

void verarbeite(const CbNachricht& n, IPAddress von) {
  // 1) Quittung zu einer eigenen offenen Sendung?
  for (auto& s : sendungen) {
    if (s.aktiv && n.typ == s.quittTyp && n.seq == s.seq && von == s.ziel) {
      s.aktiv = false;
      Serial.printf("Quittung typ=%u seq=%lu erhalten\n", n.typ, (unsigned long)n.seq);
      erfolgTon();
      return;
    }
  }

  // 2) Eingehende Anfragen (einheitsspezifisch)
#if defined(CB_UNIT_AUSSEN)
  if (n.typ == CB_TUER_AUF) {
    // 2a) Echtheit: HMAC mit dem Schlüssel des angegebenen Senders prüfen
    const uint8_t* key = keyFuerSender(n.senderId);
    if (key == nullptr) {
      Serial.printf("TUER_AUF: unbekannter Sender %u -> verworfen\n", n.senderId);
      return;
    }
    uint8_t erwartet[CB_HMAC_TAG_LEN];
    berechneTuerTag(key, n, erwartet);
    if (!gleichKonstanteZeit(erwartet, n.tag, CB_HMAC_TAG_LEN)) {
      Serial.printf("TUER_AUF seq=%lu: HMAC UNGÜLTIG -> verworfen (Fälschung?)\n",
                    (unsigned long)n.seq);
      return;   // kein Quittieren, kein Öffnen
    }
    // 2b) Frische: Replay-Schutz über rollierenden Zähler (NVS)
    uint32_t last = prefs.getUInt(nvsKeyFuer(n.senderId), 0);
    if (n.seq > last) {
      prefs.putUInt(nvsKeyFuer(n.senderId), n.seq);
      sendePaket(CB_TUER_QUITT, n.seq, nullptr, von);
      Serial.printf("TUER_AUF von ID %u seq=%lu -> echt & frisch -> öffnen\n",
                    n.senderId, (unsigned long)n.seq);
      oeffneTuer();
    } else if (n.seq == last) {
      sendePaket(CB_TUER_QUITT, n.seq, nullptr, von);   // Retransmit: nur requittieren
      Serial.printf("TUER_AUF seq=%lu == last -> Retransmit, nur requittiert\n",
                    (unsigned long)n.seq);
    } else {
      Serial.printf("TUER_AUF seq=%lu < last=%lu -> REPLAY -> verworfen\n",
                    (unsigned long)n.seq, (unsigned long)last);
      // bei Replay bewusst NICHT quittieren
    }
  }
#else
  if (n.typ == CB_KLINGEL) {
    bool dup = (n.seq == letzteKlingelSeq);
    letzteKlingelSeq = n.seq;
    sendePaket(CB_KLINGEL_QUITT, n.seq, nullptr, von); // Quittung ZUERST (µs) – blockiert Ton nicht
    if (!dup) {
      Serial.printf("KLINGEL seq=%lu -> Klingelton SOFORT\n", (unsigned long)n.seq);
      spieleSound(CB_MEIN_KLINGELSOUND);
    } else {
      Serial.printf("KLINGEL seq=%lu -> Duplikat, nur requittiert\n", (unsigned long)n.seq);
    }
  }
#endif
}
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
void loop() {
  wlanPflege();
  empfange();
  pruefeSendungen();
  audioPflege();          // WAV-Streaming (nicht-blockierend)
  volTasterPflege();      // BOOT-Taster -> Lautstärke durchschalten
  touchPflege();          // echte Auslöser
  serielleTestbefehle();  // Test-Backup ('t'/'x' bzw. 'e'/'o')
  delay(2);
}

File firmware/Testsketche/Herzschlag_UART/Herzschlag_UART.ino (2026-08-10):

// ClearBell – Testsketch: UART-Herzschlag
// Einheiten-neutral (keine Pinbelegung noetig)
// IBN-Nachweis: Versorgung, EN/GPIO0, UART-TX, Programmstart
// Nach dem Flashen manuell S_RST druecken (kein Auto-Reset auf ClearBell-Platinen)

void setup() {
  Serial.begin(115200);
}

void loop() {
  static uint32_t n = 0;
  Serial.printf("ClearBell lebt – %lu s\n", n++);
  delay(1000);
}

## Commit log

2026-08-10 ClearBell: ESP32 Smart-Doorbell - Hardware + Firmware
    [ClearBell_Ausseneinheit.kicad_pcb, ClearBell_Ausseneinheit.kicad_sch, ClearBell_Ausseneinheit_BOM.csv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]
2026-08-11 docs: add project images, dedupe hero, downscale for web
    - Add README images (hero, pcb_innen, prototyp, schaltplan) under docs/img/
    - "Außeneinheit PCB" reuses hero.jpg (same board photo) — drop the duplicate
    pcb_aussen.jpg and point the README/table at hero.jpg
    - Downscale hero/pcb_innen/prototyp to 1600 px (~18 MB -> ~1.8 MB); keep
    schaltplan.jpg full-res for legibility
    - Finalize README hero image (remove placeholder comment)
2026-09-18 V0.2 als Hauptansicht, V0.1 ins Archiv
    - hardware/: V0.2 Außen- und Inneneinheit (KiCad 10) mit Schaltplan-PDF
    und Fertigungsdaten (Gerber, Stückliste, Bestückungsdaten)
    - README: V0.2-Übersicht mit 3D-Ansichten, Änderungen gegenüber V0.1,
    Fertigung und Stand
    - archiv/V0.1/: erste Generation (Hardware, Firmware, Dashboard, Doku)
    mit eigenem README
    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
    [ClearBell_Ausseneinheit.kicad_pcb, ClearBell_Ausseneinheit.kicad_sch, ClearBell_Ausseneinheit_BOM.csv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]
2026-09-26 Softwarearchitektur V0.2 (de + en) und Sicherheitsrichtlinie
    - docs/Softwarearchitektur_V0.2.md und .en.md: Firmware-Architektur der V0.2 in
    Revision 2 - Aufbau und Ausführungsmodell, authentifiziertes Protokoll v2 mit
    Challenge-Response für den Türbefehl, Laufzeitverhalten, Datenhaltung,
    Sicherheitskonzept mit Angreifermodell, Restrisiken und Abgleich mit
    ETSI EN 303 645, Fehlerverhalten, Portierungsplan und Teststrategie
    - SECURITY.md: vertrauliche Meldung von Schwachstellen über GitHub, Fristen für
    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
2026-09-27 README: Stand auf Fertigung bei PCBWay und Softwarearchitektur
    - Einleitung und Abschnitt "Stand": die V0.2-Platinen werden bei PCBWay
    gefertigt und bestückt (statt "zur Fertigung eingereicht")
    - Stand verweist auf die Firmware-Architektur (Revision 2)
2026-09-27 SECURITY.md: Abschnitt „Bitte beachten“ gestrichen
    Die Testhinweise zielten auf fremde Installationen, die es bei ClearBell
    nicht gibt. Der Hinweis auf versehentlich veröffentlichte Zugangsdaten
    steht jetzt im Geltungsbereich (de + en).
2026-11-06 Firmware V0.2: Portierung Schritte 1–10c, Softwarearchitektur Revision 3
    ESP-IDF 5.5.5 mit Arduino-ESP32 3.3.12 (R21_ESP_IDF_mit_Arduino). Auf AU-1 und IN-1 getestet,
    Belege in firmware/docs/Testprotokoll.md:
    - Schritte 1–9: Gerüst, Grundstellung, Netz mit Protokoll v2, Türbefehl per Challenge–Response,
    Audio, Touch, Tür-Task, Statusseite mit Digest-Anmeldung und Öffnungsprotokoll, Fern-Öffnen per Push
    - Schritt 10: Updates per Upload in der Wartung, Probezeit mit Rückfall
    (R25_Updates_ohne_Schluessel)
    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
2026-11-08 Firmware V0.2: 7-h-Dauertest, Handprüfungen, Touch-Befunde, Statusseite mit Einstellungen und eigenem Passwort
    - Türöffner effeff 118W an AU-1 bestanden (Testprotokoll 7.10); F-3_Pulslaenge auf 2000 ms festgelegt (SA de/en)
    - 7-h-Dauertest lautlos bestanden, neues Werkzeug tools/dauertest.py (Testprotokoll Schritt 11)
    - FW-B-06_Baseline_eingefroren behoben: ruhiger Versatz +5..+50 % wird nach 30 s übernommen
    - FW-B-07_Beide_Tasten_klingelt behoben: Klingeln wartet 120 ms auf die andere Taste
    - Statusseite: Karte Einstellungen (Lautstärke auch im Normalbetrieb, Probeton, LED-Abgleich und Pulslänge in der
    Wartung), Akzent Dunkelgrün, Handy-Layout, Abfrage stoppt bei 401/429
    - Eigenes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
2026-11-08 Testprotokoll: Zugangsdaten und Netzangaben entfernt
    - eigene Passwörter der Statusseite (Schritte 8.18) durch Verweis auf die Anlagendatei ersetzt
    - Heim-IP (8.15) und Name des Gastnetzes (Schritt 11) entfernt
2026-11-10 Firmware V0.2: signierte Updates (Schritt 10d, R26), Versionsschutz, FW-B-08
    - Updates nur noch signiert (Secure-Boot-v2-Format, RSA-3072/PSS): zwei
    Herstellerschlüssel fest in der Firmware (Haupt, Ersatz offline), dazu
    wahlweise ein eigener Schlüssel des Besitzers in der Wartung, optional
    allein gültig; Werksreset entfernt ihn (cb_update_sig.h, cb_update_keys.h)
    - Versionsschutz: ältere Version nur mit „ältere Version zulassen“
    (PUT /update?older=1, cb.py update --aelter)
    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
2026-11-12 Werkzeuge: Werksschritt prüft Start, trägt Gerätecode in Anlage ein (FW-B-18, FW-B-19)
    - werk prüft am Ende per Konsolenbefehl info, ob die Firmware läuft; sonst
    Watchdog-Reset, sonst klarer Hinweis USB ab- und wieder anstecken (Exit-Code 2)
    - werk --name trägt Gerätenummer und Gerätecode in die Anlagendatei ein,
    anlage-einheit übernimmt beides aus dem Werksregister
    - Testprotokoll: zweite Inneneinheit IN-2 (OG) eingerichtet, gekoppelt,
    Klingel OG geprüft
2026-11-12 Werkzeuge: Statusseite nur einmal anmelden, keine Selbstsperre (FW-B-20)
    - urllib wiederholte die Digest-Anmeldung nach 401 bis zu fünfmal; mit
    veraltetem Passwort sperrte sich die Einheit 30 s, auch für den nächsten
    Aufruf mit richtigem Passwort
    - jetzt Abbruch nach dem ersten abgelehnten Versuch (Wiederholung nur bei
    stale=true), Meldung mit Hinweis auf anlage-webpasswort
    - gilt für status, update, ton-hochladen und fern.py
2026-11-12 Testprotokoll: 10a.12 und 10b.10 bestanden, Werksreset AU-1, FW-B-21/22
    - 10a.12 an IN-2: Werksreset, QR-Einrichtung, Einrichtungsseite öffnet von
    selbst; Gerätecode mit Bindestrichen als WLAN-Passwort abgelehnt
    - Werksreset AU-1 (versehentlich) und Neueinrichtung per QR, Kopplung EG/OG
    über die Seite (10b.10), Handy neu, Fern-Öffnen, Klingel EG/OG
    - FW-B-21 Wohnungsnamen frei wählbar (beschlossen), FW-B-22 Fern-Öffnen
    für beide Wohnungen (Frage)
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2026-11-12 Etikett: Avery Zweckform 3657, Code ohne Trennzeichen, Druckbogen (10a.13)
    - werk erzeugt das Etikett 48,5 x 25,4 mm: WLAN-QR, Art, Gerätenummer und
    den Code genau so, wie man ihn tippt (keine Striche, kein Erklärtext)
    - neuer Befehl cb.py etiketten: A4-Druckbogen (PDF) im 3657-Raster, ab
    Feld N, --rahmen für den Probedruck auf Normalpapier
    - Testprotokoll: 10a.13 entschieden, Werksschritt AU-1, FW-B-14 Ergebnis
2026-11-12 R27 umgesetzt: Fern-Öffnen nur mit ntfy, beide Wohnungen, Ausfallmeldung
    - Klingel-Push mit ntfy-Knopf „Tür öffnen“, der das Einmal-Token selbst an das
    Befehls-Topic des Handys schickt; keine Handy-Signatur, kein HTTP Shortcuts mehr
    - je Handy ein geheimes Topic-Paar aus seinem Schlüssel; Token je Handy und
    Klingeln, 5 min, einmalig; Bestätigungs-Push an die Handys der Wohnung
    - Handys auf der Seite der eigenen Inneneinheit (EG und OG, je bis 4),
    neue Endpunkte /phone/test und /phone/link
    - Inneneinheiten melden ihren Handys den Ausfall der Außeneinheit und die Rückkehr
    - fern.py/cb.py für R27; SA 4.5 (DE/EN) neu, Rev. 3.2; README, CHANGELOG,
    Testprotokoll (R27.1-R27.9, F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
2026-11-14 VK-07: Gegenstellen-Adresse und Türbefehl gegen eingespielte Pakete gehärtet (RV-10, RV-11, RV-34, RV-37)
    cb_link meldet, ob ein echter Rahmen auch frisch war; cb_net lernt Adressen nur daraus, antwortet an die Absenderadresse und lässt mDNS bei Unerreichbarkeit/WLAN-Verlust wieder suchen (Router-Reset). Ein wiederholter DOOR_REQUEST bekommt dieselbe Challenge statt die gültige zu entwerten. Bekannte Gegenstellen bekommen eigenen Ratentopf und eigene Warteschlange, alle Unbekannten einen gemeinsamen Deckel. 7 neue PC-Tests (Tür-Tests vorher rot, Gegenprobe für die Frische). Gerätetest SK1.2b nach dem 24-h-Lauf.
2026-11-14 VK-06: Webserver begrenzt Anfragekörper, sperrt Kopplungsversuche je Absender, lehnt fremde Seiten ab (RV-17, RV-41, RV-35 Teil B, RV-39)
    Neues cb_core-Modul cb_http_guard (BodyReader, FailGuard, request_origin_ok) mit 10 PC-Tests; main/cb_http_util als Brücke. Alle 7 Leseschleifen haben eine Frist, die Herkunftsprüfung (X-ClearBell, Origin, Sec-Fetch-Site, Host) läuft vor jeder Anmeldung, falsche Kopplungsangebote sperren nur ihren Absender. Seiten und statusseite.py senden die Kopfzeile. Frische-Teil von RV-35 bewusst nach VK-13. Gerätetests SK1.3b/c nach dem 24-h-Lauf.
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
